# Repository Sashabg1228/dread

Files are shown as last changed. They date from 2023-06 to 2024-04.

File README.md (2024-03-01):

# dread
Version 1 of the battlebot was sawbot battlebot inspired by Sawblaze
It was made for the event TuesBattlebots 2023.
The project was developed from December 2022 to June 2023.

Version 2 of the robot is used for graduation project in school.
The type of the robot is changed from sawbot to hammersaw, meaning the saw no longer has the function of cutting but of striking the opponents. The work on this version started at the end of September 2023.

Link to github repo:
https://github.com/Sashabg1228/dread.git

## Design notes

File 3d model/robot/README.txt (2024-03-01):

To see the current version of the project go to:
https://a360.co/3Ihqd91

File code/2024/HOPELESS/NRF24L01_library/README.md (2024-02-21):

library for nRF24L01 radio module

IMPORTANT:
The library is specifically made for the STM32F103C8 (blue pill) board.

Set the fowolling user labels to the coresponding pins:

NRF24L01_IRQ - the pin connected to the IRG pin of the nRF24L01 module 
NRF24L01_CE - the pin connected to the CE pin of the nRF24L01 module
NRF24L01_CSN - the pin connected to the CSN pin of the nRF24L01 module

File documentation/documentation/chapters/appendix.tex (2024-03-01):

\begingroup % Begin a TeX group in order to localize scope of next three instructions
    \small
    \begin{longtable}{| m{4.5cm} | m{4.5cm} | m{3cm} | m{2cm} |}
    %% Headers and footers
    \caption{Използвани елементи в печатната платка на робота}
    \label{table:elements-robot} \\
    \hline
    \textbf{Вид} 
      & \textbf{Продуктов номер / Размер}
      & \textbf{Reference(s)}
      & \textbf{брой} \\ \hline
    \endfirsthead 
    \hline
    \textbf{Вид} 
      & \textbf{Продуктов номер / Размер}
      & \textbf{Reference(s)}
      & \textbf{брой} \\ \hline
    \endhead 
    \multicolumn{4}{r@{}}{\em}\\
    \endfoot
    \endlastfoot
    %% Body of table
    Електролитен Кондензатор & 100uF & C1, C5, C8 & 3 
    \\ \hline
    Керамичен Кондензатор & 100nF & C2, C3, C4, C6, C7, C9, C10, C11, C12 & 9
    \\ \hline
    Ценеров диод & BZX85C10-TAP & D1 & 1
    \\ \hline
    Двупосочен трансил & P6KE27CA & D3 & 1
    \\ \hline
    Оптрони & HCPL-2531 & IC1, IC2, IC3 & 3
    \\ \hline
    Клема 2 пина & 236-102 & J1, J3, J4, J7, J16, J6, J9, J18, J13, J14, J15 & 11
    \\ \hline
    Клема 4 пина & 236-104 & J2, J10, J11 & 1
    \\ \hline
    Клема 1 пин & 236-401 & J5, J8, J12, J17 & 4
    \\ \hline
    Бобина & 2.2uH & L1 & 1
    \\ \hline
    P-MOS транзистор & IXTP120P065T & Q1 & 1
    \\ \hline
    Резистор & 8.2kR & R1 & 1
    \\ \hline
    Резистор & 680R & R2, R3, R4 & 3
    \\ \hline
    Линеен регулатор & L7805 & U3, U4 & 2
    \\ \hline
    Преобразувател на логическото ниво & CD40109BE & U12 & 1
    \\ \hline
    Гнездо за бушон & 3522-2 & X1 & 1
    \\ \hline
    \end{longtable}
\endgroup % End of TeX group

%================================================================================
%================================================================================

\begingroup % Begin a TeX group in order to localize scope of next three instructions
\begin{landscape}
    \small
    \begin{longtable}{| m{2cm} | m{5cm} | m{3cm} | m{3cm} | m{9cm} |}
    %% Headers and footers
    \caption{Конфигурация на изводите на микроконтролера на робота}
    \label{table:pins-robot} \\
    \hline
    \textbf{Pin Nо.} 
      & \textbf{User label}
      & \textbf{GPIO mode}
      & \textbf{GPIO pull-up}
      & \textbf{GPIO function} \\ \hline
    \endfirsthead 
    \hline
    \textbf{Pin Nо.} 
      & \textbf{User label}
      & \textbf{GPIO mode}
      & \textbf{GPIO pull-up}
      & \textbf{GPIO function} \\ \hline
    \endhead 
    \multicolumn{5}{r@{}}{\em Cont'd on following page}\\
    \endfoot
    \endlastfoot
    %% Body of table
    PA1 & HAND\_PWM & GPIO\_OUTPUT & NO & Чрез таймер 2 се генерират импулси за управление на стъпковия мотор\\
            \hline
            PA2 & HAND\_DIR & GPIO\_OUTPUT & NO & Управлява се посоката на движение на стъпковия мотор\\
            \hline
            PA4 & DISK\_DIR & GPIO\_OUTPUT & NO & Управлява се посоката на движение на мотора за оръжието\\
            \hline
            PA5 & WHEEL\_LEFT\_DIR & GPIO\_OUTPUT & NO & Управлява се посоката на движение на мотора за лявото колело\\
            \hline
            PA6 & WHEEL\_RIGHT\_DIR & GPIO\_OUTPUT & NO & Управлява се посоката на движение на мотора за дясното колело\\
            \hline
            PA7 & DISK\_PWM & TIM3\_CH2 & NO & Чрез канал 2 на таймер 3 се генерира ШИМ сигнал за управление на скоростта на мотора за оръжието\\
            \hline
            PB0 & WHEEL\_LEFT\_PWM & TIM3\_CH3 & NO & Чрез канал 3 на таймер 3 се генерира ШИМ сигнал за управление на скоростта на мотора за лявото колело\\
            \hline
            PB1 & WHEEL\_RIGHT\_PWM & TIM3\_CH4 & NO & Чрез канал 4 на таймер 3 се генерира ШИМ сигнал за управление на скоростта на мотора за дясното колело\\
            \hline
            PB14 & HAND\_END\_LEFT & GPIO\_EXTI14 & PULL-UP & Чрез външното прекъсване на този пин, генерирано при падащ и растящ фронт, се предотвратява излизането на стъпковия мотор извън крайното си състояние\\
            \hline
            PB15 & HAND\_END\_RIGHT & GPIO\_EXTI15 & PULL-UP & Чрез външното прекъсване на този пин, генерирано при падащ и растящ фронт, се предотвратява излизането на стъпковия мотор извън крайното си състояние\\
            \hline
             PB7 & OPT\_END\_WHEEL\_RIGHT & GPIO\_EXTI7 & PULL-UP & Чрез външното прекъсване на този пин, генерирано при падащ фронт, се проследява каква е скоростта на мотора за дясното колело\\
            \hline
            PB8 & OPT\_END\_WHEEL\_LEFT & GPIO\_EXTI8 & PULL-UP & Чрез външното прекъсване на този пин, генерирано при падащ фронт, се проследява каква е скоростта на мотора за лявото колело\\
            \hline
            PB9 & OPT\_END\_WHEEL\_DISK & GPIO\_EXTI9 & PULL-UP & Чрез външното прекъсване на този пин, генерирано при падащ фронт, се проследява каква е скоростта на мотора за оръжието\\
            \hline
            PB5 & SPI1\_MOSI & SPI1\_MOSI & NO & Използва се за MOSI пин при помуникацията с радиочестотния модул\\
            \hline
            PB4 & SPI1\_MISO & SPI1\_MISO & NO & Използва се за MISO пин при помуникацията с радиочестотния модул\\
            \hline
            PB3 & SPI1\_SCK & SPI1\_SCK & NO & Използва се за SCK пин при помуникацията с радиочестотния модул\\
            \hline
            PA10 & NRF24L01\_IRQ & GPIO\_EXTI10 & NO & Чрез външното прекъсване на този пин, генерирано при падащ фронт, се известява за това, че има получен пакет информация\\
            \hline
            PA11 & NRF24L01\_CE & GPIO\_OUTPUT & NO & Управлява се дали може да се изпращат и получават данни\\
            \hline
            PA15 & NRF24L01\_CSN & GPIO\_OUTPUT & NO & Управлява се дали може да се четат и пишат регистрите на радиочестотния модул\\
            \hline
    \end{longtable}
\end{landscape}
\endgroup % End of TeX group

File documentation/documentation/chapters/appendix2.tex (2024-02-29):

\begin{figure}[H]
    \centering
    \caption{На следващата страница е електрическата схема на робота }
    \label{fig:robot-schema} 
\end{figure}

\includepdf[pages={1}]{documents/robot-schema.pdf}

\begin{figure}[H]
    \centering
    \caption{Печатна платка на робот}
    Следващите 7 изображения са отделните слоеве на печатната платка в робота. Те са в мащаб 1:1 и са наредени в следния ред:
    Мед, страна компоненти \\
    Мед, страна спойки \\
    Ситопечат, страна компоненти \\
    Ситопечат, страна спойки \\
    солдер маска, страна компоненти\\
    солдер маска, страна спойки\\
    Ръбове и отвори 
    
    \label{fig:pcb-layout-multy-robot} 
\end{figure}

\includepdf[pages={1}]{documents/PCB-layout-multy-robot.pdf}
\includepdf[pages={2}]{documents/PCB-layout-multy-robot.pdf}
\includepdf[pages={7}]{documents/PCB-layout-multy-robot.pdf}
\includepdf[pages={8}]{documents/PCB-layout-multy-robot.pdf}
\includepdf[pages={9}]{documents/PCB-layout-multy-robot.pdf}
\includepdf[pages={10}]{documents/PCB-layout-multy-robot.pdf}
\includepdf[pages={11}]{documents/PCB-layout-multy-robot.pdf}

\begin{figure}[H]
    \centering
    \caption{На следващата страница е монтажната схема на робота }
    \label{fig:robot-mounting-schema} 
\end{figure}

\includepdf[pages={1}]{documents/robot-mounting-schema.pdf}

\begin{figure}[H]
    \centering
    \caption{На следващата страница е електрическата схема на пулта за управление }
    \label{fig:controller-schema} 
\end{figure}

\includepdf[pages={1}]{documents/controller-schema.pdf}

\begin{figure}[H]
    \centering
    \caption{Печатна платка на пълта за управление}
    Следващите 7 изображения са отделните слоеве на печатната платка в робота. Те са в мащаб 1:1 и са наредени в следния ред:
    Мед, страна компоненти \\
    Мед, страна спойки \\
    Ситопечат, страна компоненти \\
    Ситопечат, страна спойки \\
    солдер маска, страна компоненти\\
    солдер маска, страна спойки\\
    Ръбове и отвори 
    
    \label{fig:pcb-layout-multy-controller} 
\end{figure}

\includepdf[pages={1}]{documents/PCB-layout-multy-controller.pdf}
\includepdf[pages={2}]{documents/PCB-layout-multy-controller.pdf}
\includepdf[pages={3}]{documents/PCB-layout-multy-controller.pdf}
\includepdf[pages={4}]{documents/PCB-layout-multy-controller.pdf}
\includepdf[pages={5}]{documents/PCB-layout-multy-controller.pdf}
\includepdf[pages={6}]{documents/PCB-layout-multy-controller.pdf}
\includepdf[pages={7}]{documents/PCB-layout-multy-controller.pdf}

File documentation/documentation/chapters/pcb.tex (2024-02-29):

\chapter{Проектиране на печатните платки}

За проектирането на печатните платки и монтажните схеми в проекта е използван софтуерния пакет KiCad. Той е избран за целта, защото е безплатен и има богата библиотека с компоненти, съдържащи символи и очертания на корпуси.

%================================================================================
% ЕЛЕКТРИЧЕСКА СХЕМА  -  РОБОТ

\section{Принципна електрическа схема на робота}

Принципната електрическа схема на печатната платка в робота може да бъде видяна на \cref{fig:robot-schema}. Основният елемент на схемата е микроконтролерът STM32F103C8T6 (blue pill), който управлява останалите компоненти. Използваните компоненти в проектирането на тази печатната платка могат да бъдат видяни в таблица \cref{table:pins-robot}.

\subsection{Радиочестотен модул}
\label{ssec:rf-module-robot}

Връзката между дистанционното и робота се осъществява посредством nRF24L01+ PA/LNA радиочестотен модул. Комуникацията между него и използвания микроконтролер е посредством SPI интерфейс. Радиочестотният модул бива захранван с 3,3V от вградения регулатор на напрежението на blue pill. С цел повишаване на съотношението сигнал/шум са поставени 100nF керамичен кондензатор и 100uF електролитен кондензатор, които да намалят съответно високочестотните и нискочестотните шумове.

предавател по далеч / мощни мотори = повече шум
слаб сигнал

%+ какво е ПА/ЛНА 
%+ режим на СПИ интерфей и неговата скорост
\begin{figure}[H]
    \centering
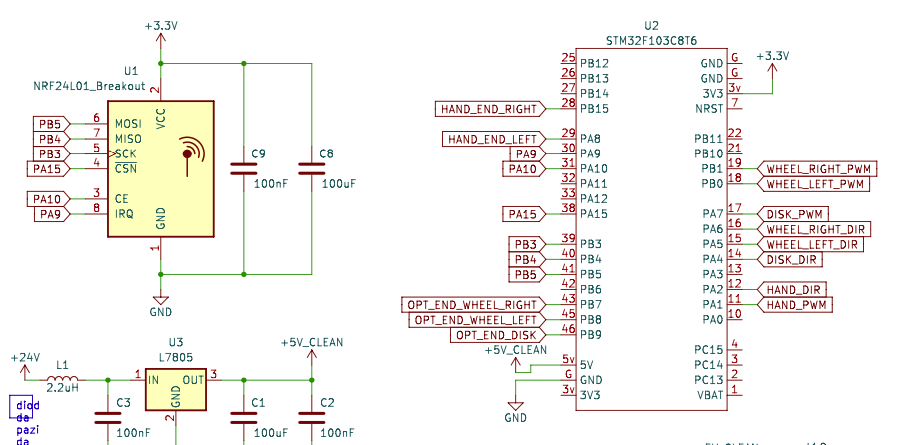
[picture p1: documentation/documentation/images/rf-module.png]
    
    
    \caption{Радиочестотен модул в робота}
    \label{fig:rf-module-robot} 
\end{figure}

\subsection{Управление на моторите}

Управлението на постоянно токовите четкови мотори се извършва посредством MD13S драйвери. Необходимите логически сигнали за да може да се реализира управлението са ШИМ сиганл, който упоменава скоростта, с която мотора трябва да се върти, и високо или ниско ниво, което да показва посоката на движение. С цел постигане на галванична изолация между микроконтролера и драйверите са поставени оптрони. Начинът на свързване на всеки оптрон може да бъде видян на \cref{fig:brushed-control}. Необходимото захранване на всеки мотор е 24V и то бива подадено посредством отделен конектор.

\begin{figure}[H]
    \centering
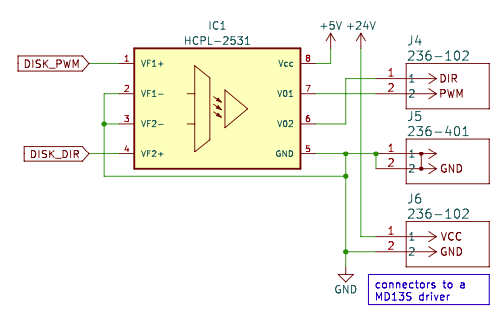
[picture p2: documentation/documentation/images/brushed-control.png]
    
    
    \caption{Оптрон}
    \label{fig:brushed-control} 
\end{figure}

За управлението на стъпковия мотор се използва драйвер DM556T. Сигналите за управление включват , поредица от импулси, които указват колко стъпки трябва да бъдат направени и логическо ниво (високо или ниско), указващо посоката им. Не е поставен допълнителен оптрон за изолация между драйвера и микроконтролера, поради причината, че на входовете си DM556T има вградени такива. Така направена схемата обаче няма да работи, защото логика на blue pill-а е на 3,3V, докато драйвера използва 5V логика. Този проблем бива решен като се използва преобразувател на логически нива U12, който превежда логическото управление от 3,3V към 5V, съответстващо на логиката, използвана от драйвера.

\begin{figure}[H]
    \centering
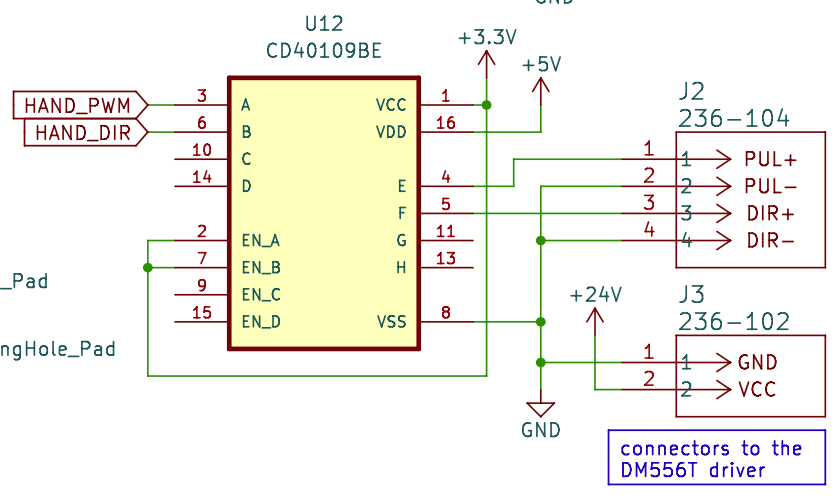
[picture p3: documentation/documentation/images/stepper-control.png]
    
    
    \caption{Преобразувател на логически нива}
    \label{fig:stepper-control} 
\end{figure}

\subsection{Сензори}

За следене на скоростта на робота са предвидени и инсталирани оптични сензори. Те биват свързвани към печатната плака чрез конекторите J10, J11 и J12. Всеки сензор има извод за данни и изводи за захранване. Сигналите от оптичните сензори минават през пасивни нискочестотни RC филтри с цел да се премахнат потенциални смущения.

\begin{figure}[H]
    \centering
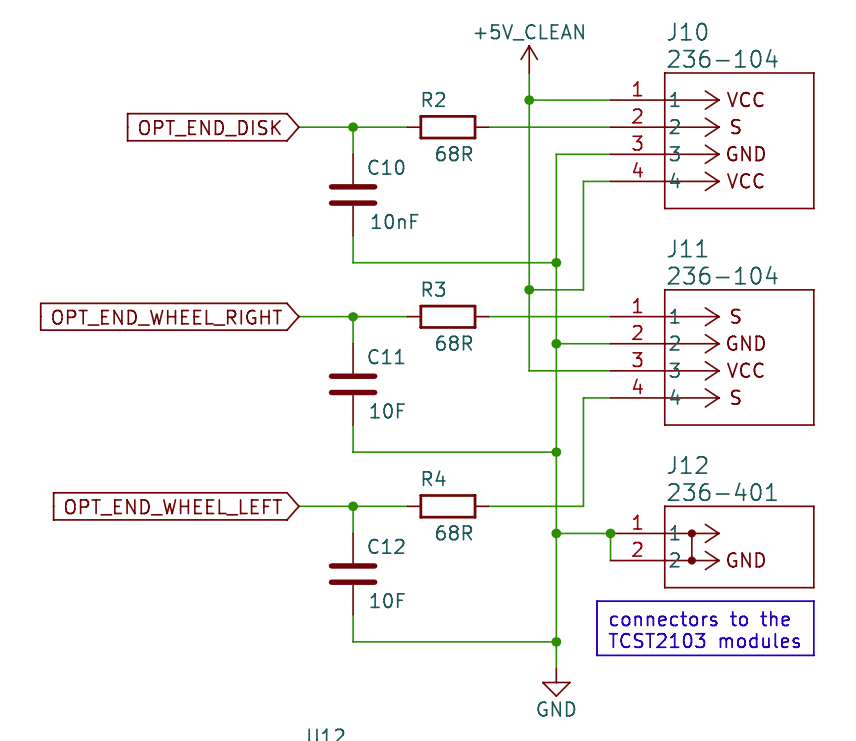
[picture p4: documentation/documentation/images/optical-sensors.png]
    
    
    \caption{оптични сензори}
    \label{fig:optical-sensors} 
\end{figure}

Съгласно изискванията за безопасност са предвидени и крайни изключватели, които да следят дали стъпковият мотор е достигнал някоя от крайните си позиции. Те са свързани, чрез конекторите J13 и J14

\begin{figure}[H]
    \centering
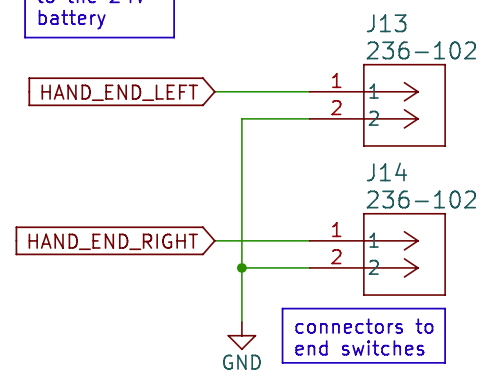
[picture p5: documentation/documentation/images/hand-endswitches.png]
    
    
    \caption{Крайни изключватели за ръката}
    \label{fig:hand-endswitches} 
\end{figure}

\subsection{Захранване на печатната платка}

Печатната платка се захранва директно от 24V постояннотокова батерия. Съгласно изискванията за безопасност изводите на конектор J15 са предвидени за ключ, който да спира цялото захранване на робота. Освен това има имплементирани хардуерни защити против късо съединение, пренапрежение и обратен поляритет на захранването. Първата от трите е реализирана чрез поставянето на автомобилен бушон на държача X1 последователно свързан след главния ключ. Защитата против пренапрежение се осъществява посредством двупосочния трансил D3. С цел защита против неправилен поляритет на напрежението е поставена P-MOS защита след трансила. Тя се реализира чрез транзистора Q2, ценеровия диод D1 и резистора R1. При правилното свързване на батерията през диода в Q1 протича ток. Поради образувания делител на напрежение D1 и R1, напрежението гейт-сорс на Q2 става равно на пробивното напрежение на D1 и транзисторът се отпушва. В случай, че батерията бъде свързана с обратен поляритет, диодът в Q1 бива свързан в обратна посока и транзисторът остава запушен. Във веригата е поставен и кондензатора C7 за да стабилизира напрежението върху ценера D1.

\begin{figure}[H]
    \centering
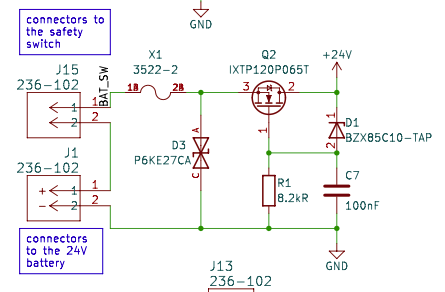
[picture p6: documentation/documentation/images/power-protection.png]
    
    
    \caption{Защити на захранването}
    \label{fig:power-protection} 
\end{figure}

Захранването на логическата част на проекта е постигнато посредством линейни стабилизатори L7805. Tо е разделено на два канала за да може да бъдат намалени шумовете в захранването на микроконтролера и радиочестотния модул. По-чувствителните към шумове елементи разполагат с отдлно захранване. 

Първият канал използва стабилизатора U4 за да успее да свали напрежението до 5V, които да бъдат подадени после на оптроните на логическата част на четковите мотори и на логическия преобразовател на стъпковия мотор. Той е показан на \cref{fig:power-5V}. За намаляване на шумовете в системата са поставени електролитния кондензатор C5 и керамичния C4 и C6. 

Второто захранване е почти идентичен с първия. Той се използва за захранването на микроконтролера, радиочестотния модул и сензорите в робота. Може да бъде видян на \cref{fig:power-5V-clean}. Това захранване допълнително разполага с индуктор L1, който блокира смущения.

\begin{figure}[H] 
    \centering
    \begin{subfigure}[h]{0.6\textwidth}
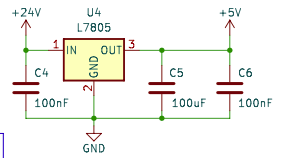
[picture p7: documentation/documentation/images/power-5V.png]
        
        \caption{Захранване на логиката на силовата електроника}
        \label{fig:power-5V}
    \end{subfigure}
    \\ %add desired spacing between images, e. g. ~, \quad, \qquad, \hfill etc. 
      %(or a blank line to force the subfigure onto a new line)
    \begin{subfigure}[h]{0.75\textwidth}
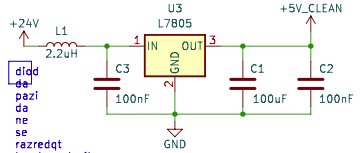
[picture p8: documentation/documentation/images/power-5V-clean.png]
        
        \caption{Захранване на микроконтролера, радиочестотния модул и сензорите}
        \label{fig:power-5V-clean}
    \end{subfigure}
    ~ %add desired spacing between images, e. g. ~, \quad, \qquad, \hfill etc. 
    %(or a blank line to force the subfigure onto a new line)    
    \caption{Захранване на логическата част в робота.}
    \label{fig:power-low}
\end{figure}

%================================================================================
% PCB layout  -  РОБОТ

\section{Опроводяване на печатната платка на робота}

На \cref{fig:pcb-layout-color-robot} могат да се видят двата слоя на печатната платка. Захранващата мрежа +24V е опроводена чрез медни зони. При проектирането и е спазена добрата практика, когато има две различни напрежения на печатната платка те да бъдат отделени максимално далеч едно от друго. По останалата част от проводниците се движат или +5V, или от +3.3V. Голямата медна област от долната страна се използва за земя. В 3 от четирите ъгъла могат да бъдат видени предвидените монтажни отвори за закрепване на платката. Особеност на тази платка е неизбежното застъпването на U1 и U12. В общия случай подобно разположение на елементите е груба грешка, но U1 е модул, монтиран на стандартни рейки. Това оставя повече от достатъчно пространство U12 да бъде поставен. 

В \cref{fig:pcb-layout-multy-robot} са показани поотделно всеки слой на печатната платка.

\begin{figure}[H]
    \centering
    
    
    \caption{Печатна платка на робота}
    \label{fig:pcb-layout-color-robot} 
\end{figure}

%================================================================================
% МОНТАЖНА СХЕМА  -  РОБОТ

\section{Монтажна схема на робота}

Монтажната схема на робота може да бъде намерена в \cref{fig:robot-mounting-schema}. На нея може да се види основната част в робота, представляваща разработената печатна платка, която съдържа радиочестотния модул за комуникация, микроконтролера, управляващ робота, и хардуерните защити на захранването. Нейното захранване индва от 24V батерия DeWalt DE0241 и съгласно изисканията за безопасност във всеки момент то може да бъде прекъснато чрез ключът SW1. Разработената платка захранва и управлява 3 постояннотокови четкови мотори с помощта на драйвери MD13S. С цел мониторинг на тяхната скорост е предвидено на всеки от тях да има монтиран по един оптичен сензор за скорост. Използваният nema 24 стъпков мотор се управлява посредством DM556T драйвер. Начинат на свързване на драйвера към печатната платка е конфигурация общ катод. Съгласно изискванията за безопасност чрез SW1 и SW2 се следи дали стъпковият мотор не е стигнал до крайните си състояния.

%+ параметри на входовете на драйверите

%================================================================================
% ЕЛЕКТРИЧЕСКА СХЕМА  -  ДИСТАНЦИОННО

\section{Принципна електрическа схема на пулта за управление}

Принципната електрическа схема на печатната платка на дистанционното може да бъде видяна на \cref{fig:controller-schema}. Основният елемент на схемата е микроконтролерът STM32F103C8T6 (blue pill), който чете данните от сензорите, обработва ги и после ги праща към робота посредством радиочестотния модул. Връзката между него и микроконтролера е идентична на тази описана в \cref{ssec:rf-module-robot}. Захранването на пулта за управление на бойния робот се реализира посредством USB извода на използвания микроконтролер.

\begin{figure}[H]
    \centering
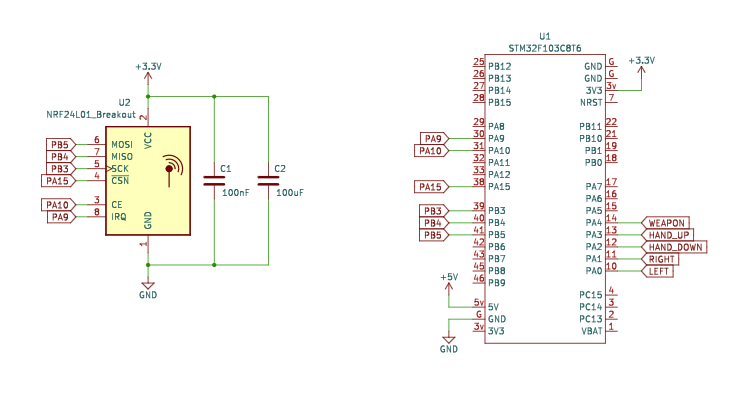
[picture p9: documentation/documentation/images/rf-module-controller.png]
    
    
    \caption{Радиочестотен модул в пулта за управление}
    \label{fig:rf-module-controller} 
\end{figure}

\subsection{Сензори}

Компонентите, които се използват за четене на инструкциите от пилота на бойния робот са 2 потенциометъра и 3 бутона. Потенциометрите са свързани посредством конекторите J4, J5 и J6. Връзката с бутоните е осъществена чрез конекторите J1, J2 и J3.

\begin{figure}[H]
    \centering
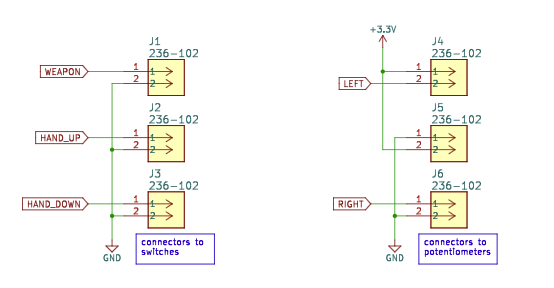
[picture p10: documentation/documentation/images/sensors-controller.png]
    
    
    \caption{Сензори в пулта за управление}
    \label{fig:sensors-controller} 
\end{figure}

%================================================================================
% PCB layout  -  ДИСТАНЦИОННО

\section{Опроводяване на печатната платка на дистанционното}

На \cref{fig:pcb-layout-color-robot} могат да се видят двата слоя на печатната платка на дистанционното. По проводниците, които могат да се видят, се движат 3,3V. Голямата медна област, която се забелязва се използва за земя. Забелязва се и липсата на монтажни отвори. Причината за тяхното отсъствие е това, че платката е предвидена да бъде легнала на страна спойки във специално по размери 3D принтирано легло.

В \cref{fig:pcb-layout-multy-controller} са показани поотделно всеки слой на печатната платка.

\begin{figure}[H]
    \centering
    
    
    \caption{Печатна платка на пулта за управление}
    \label{fig:pcb-layout-color-controller} 
\end{figure}

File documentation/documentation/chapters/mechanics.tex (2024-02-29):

\chapter{Механика}

%================================================================================
% ЦЯЛОСТЕН МОДЕЛ
 
\section{Цялостен модел на робота}

Както е описано в предишната глава, дизайна на бойния робот е вдъхновен от робота SawBlaze. Материала, който е използван за изграждането на прототипа на проекта е два милиметра дебела студено валцована въглеродна стомана DC01. Механичната конструкция на робота може да бъде разделена на два основни компонента - шасито, в което седят почти всички елементи, и механичната ръка, на която е закрепено оръжието.  

\begin{figure}[H]
    \centering
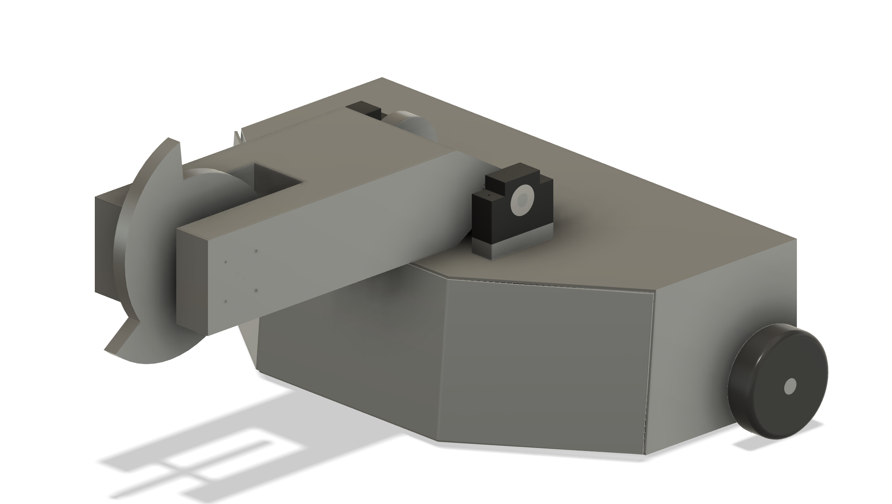
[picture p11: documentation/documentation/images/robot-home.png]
    
    
    \caption{3D макет на бойния робот}
    \label{fig:robot-home} 
\end{figure}

%================================================================================
% ЗАДВИЖВАНЕ

\section{Задвижване на робота}
\label{sec:motion}

По време на проектирането на механиката на боен робот първият проблем, който трябва да бъде разгледан е как той ще се придвижва по арената. След направеното проучване в \cref{sec:motion-types} бе установено, че най-ефективният метод е диференциалното задвижване с колела. По дизайн роботът има две задвижващи колела отдвете си страни и още две допълнителни пасивни колела, които го балансират и му помагат да се движи по-добре. Всяко от задвижващите колела е с външен диаметър 80мм и ширина 12мм. Използваните мотори за тяхното задвижване са CHANCS 895 DC.

\begin{figure}[H]
    \centering
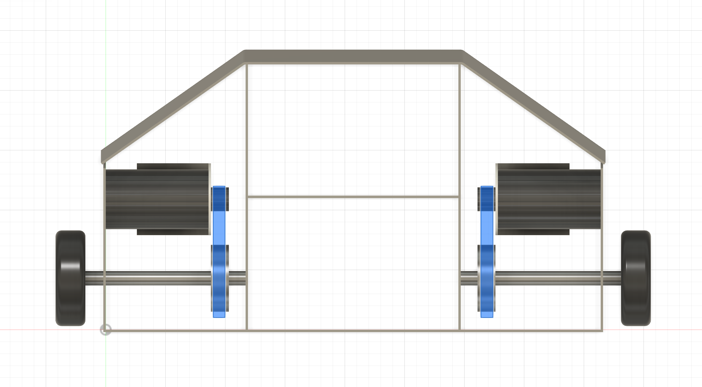
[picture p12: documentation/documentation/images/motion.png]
    
    
    \caption{Схема на задвижването на бойния робот}
    \label{fig:motion} 
\end{figure}

За да може батълбота, който тежи приблизително 18kg, да се задвижва от две колела трябва да бъде пресметнато какъв въртящ момент трябва да достига до всяко от тях
\footnote{Изчисленията са извършени като се приема, че роботът се движи на равна повърхност}
. За целта на изчисленията приемаме, че двете активни колела ще понасят цялото тегло на робота. Понеже на двете колела лежи тежестта от 18kg, означава, че всяко колело изпитва натиска от 9kg или еквивалентните им 88,29N. Коефициента на триене между колелата и пода на арената варира между 0,75 когато робота е в покой и 0,65 когато е в движение. Следователно най-голямата сила на съпротивление, която всяко колело може да генерира без самото колело да се върти е 88,29N х 0.75 = 66,2175N. След като диаметъра на колелото е 80мм следва, че радиусът му е 40мм или 0,04м. Следователно минималният въртящ момент, който позволява на колелата да се въртят е равен на 66,2175N x 0,04m = 2,6487Nm. Следователно минималният въртящ момент, който мотора трябва да достави на колелото е 2,6487Nm, но по време на въртенето си той има само 0,735Nm.

Поради тази причина се налага да се направи редукция на скоростта на мотора за да се увеличи неговия въртящ момент. За да се изчисли каква трябва да бъде нужната редукция трябва да се намери отношението на необходимият въртящ момент и този, който може да бъде генериран. Редукцията, която се получава, че трябва да бъде реализирана между мотора и колелото е минимум 2,6487Nm / 0,735Nm = 3,6.

Начинът, по който е реализирано диференциалното задвижване е като всяко от активните колела бива задвижвано от различен мотор. Връзката между тях е реализирана, чрез зъбчат ремък с ширина 10мм. За да се постигне необходимата редукция, отношението на зъбите на ремъчните ролки на осите на колелата и тези на моторите трябва да бъде равно на нея. Поради това използваните ролки на моторите са с по 10 зъба, а другите са с по 36 зъба. С цел намаляване на триенето между осите на колелата и стените, осите са захванати с лагери в специално изработените за целта лагерни опори, закрепени за стените.

%================================================================================
% РЪКАТА

\section{Задвижване на ръката}

Първата специфична функционалност на разработения боен робот е начина, по който механичната ръка се върти около оста си и се задържа на позицията, на която и бива зададено да седи. Тази задача бива изпълнена чрез употребата на стъпков мотор Nema 24.

За да може ръката да се върти около оста си първо трябва да бъде изчислено какъв въртящ момент ще бъде необходим за целта. Тежестта на ръката е приблизително 4kg, което означава, че силата която е нужно да бъде приложена за да може тя да се завърти е 39,24N. За да пресметнем колко е необходимият въртящ момент за нейното завъртане е необходимо получената сила да бъде умножена по дължината на ръката, която е 240мм(0,24м). По този начин получаваме, че трябва да бъдат приложени 39,24N х 0,24м = 9,4176Nm. Употребеният стъпков мотор може да задържа на една позиция само товари, които изискват въртящ момент 3,1Nm или по-малко, от което следва, че се налага да бъде приложена минимална редукция от 3,03 за да може да бъде реализирано въртенето на ръката.

\begin{figure}[H]
    \centering
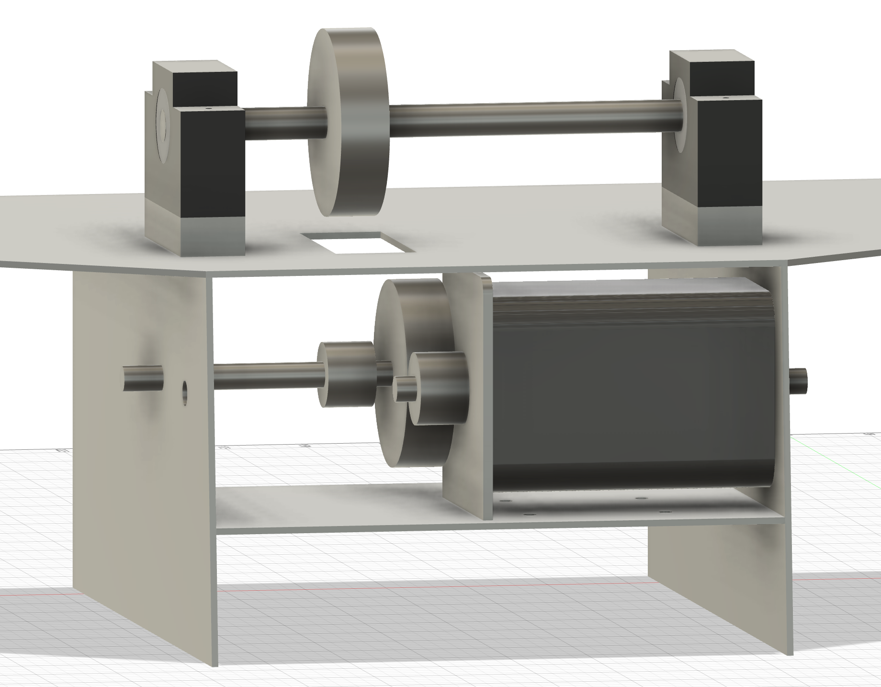
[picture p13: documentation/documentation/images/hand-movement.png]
    
    
    \caption{Схема на задвижването на механичната ръка}
    \label{fig:hand-movement} 
\end{figure}

Начинът, по който е осъществено завъртането на ръката е като тя бива захваната за своята ос така, че чрез завъртането на оста ръката да бъде придвижена заедно с нея. Предаването на движението от стъпковия мотор към оста на ръката е постигнато посредством зъбни ремъци. С цел максималното увеличение на приложената редукция е поставена спомагателна ос между мотора и оста на ръката. По този начин се получават две редукции на движението на мотора. Първата бива от мотора към спомагателната ос, като поставената ролка на мотора има 12 зъба, а тази на спомагателната ос 36 зъба. Постиганата редукция чрез тази връзка е 3. Втората редукция бива от спомагателната ос към оста на ръката и използваните ролки са в същото отношение като тези в предишната предавка. Резултатът от двете връзки е, че общата редукция на скоростта на въртене на мотора се получава да бъде умножението на двете, от които е съставена, което я прави 9. За намаляване на съпротивлението по време на въртенето си са поставени лагерни опори в краищата на двете оси.

%================================================================================
% ОРЪЖИЕТО

\section{Задвижване на оръжието}

Друг проблем, който трябва да бъде решен по време на проектирането на механиката на всеки боен робот е по какъв начин неговото оръжие ще се задвижва. Както е описано в точка \cref{sec:block-schemas} оръжието, което се използва в разработения проект е 180-милиметров диск с ширина 8мм и специфична форма. Формата на диска може да бъде видяна на фигура \cref{fig:disk}. Той е захванат за своята ос така, че чрез завъртането на оста и диска да се върти заедно с нея. Използваният мотор за движението на оръжието е CHANCS 895 DC. Начина, по който е реализирано предаването на движението от мотора до оста на диска е посредством плосък ремък. Избран е плосък ремък за тази цел, а не зъбчат поради причината, че при удар ремъка и мотора трябва отведнъж да спрат своето движение, което често може да доведе до прескачане на зъби на зъбчатия ремък и тяхното ронене. В тези ситуации плоския ремък няма да се амортизира по този начин, а само ще се приплъзне леко по своите ролки. Реализирана е и редукция от 5 на скоростта на тази предавка поради високата скорост, с която би се въртял диска. С цел намаляване на съпротивлението по време на въртенето си в краищата си оста на диска е поставен в лагерни опори, които са застопорени за стените на ръката.

\begin{figure}[H]
    \centering
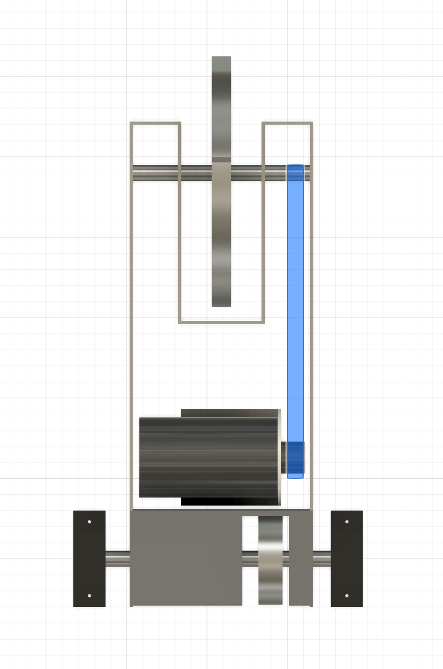
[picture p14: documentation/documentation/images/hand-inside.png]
    
    
    \caption{Схема на задвижването на оръжието}
    \label{fig:hand-inside} 
\end{figure}

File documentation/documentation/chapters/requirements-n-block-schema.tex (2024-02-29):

\chapter{Дизайн и блоковата схема на робота}

\section{Дизайн и Функционални изисквания към робота}
\label{sec:requirements}

В рамките на дипломната работа бойният робот, който се разработва, е с оръжие "hammer saw". Този вид оръжие е хибрид между пневматичните чукове и въртящите се режещи дискове. По дизайн оръжието е диск, чиято формата не е перфектен кръг, а е неправилна особена форма. Тя може да бъде видяна на \cref{fig:disk}. Разработения робот е вдъхновен от робота SawBlaze участник от телевизионното състезание BattleBots.

\begin{figure}[H]
    \centering
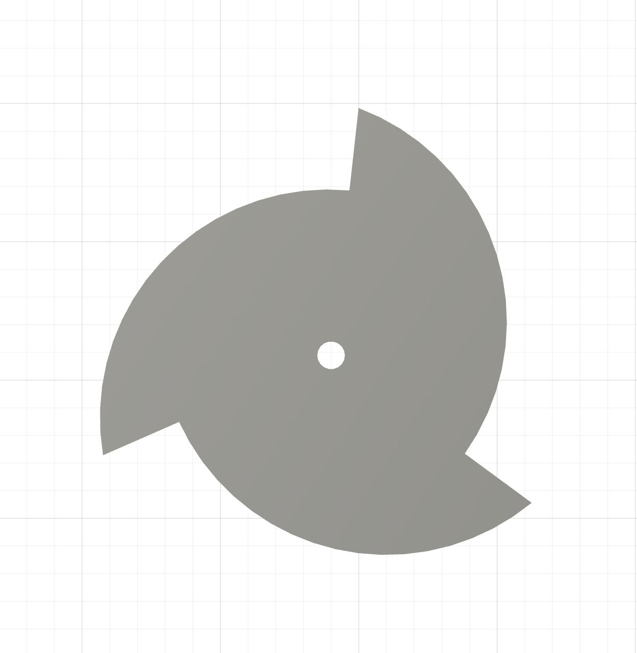
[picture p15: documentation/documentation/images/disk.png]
    
    
    \caption{Хоризонтален разрез на оръжието}
    \label{fig:disk} 
\end{figure}

\section{Блок схеми}
\label{sec:block-schemas}

На \cref{fig:block-controller} и \cref{fig:block-robot} са представени блоковите схеми на пулта за управление и робота. Със син цвят са представени устройствата слаботоковите устройства, а червен захранването и силовата електроника. Черните стрелки на схемите представляват пренос на данни, а червените - захранване.

Основния компонент в схемата на дистанционното печатната платка, върху която седи микроконтролерът и радиочестотния модул. Това което микроконтролера прави е да прочита данните от бутоните и потенциометрите и да се предават посредством радио модула до печатната платка в робота. За повече информация какъв е цикъла на работа може да се прочете \cref{sec:logic-schemas}.

\begin{figure}[H]
    \centering
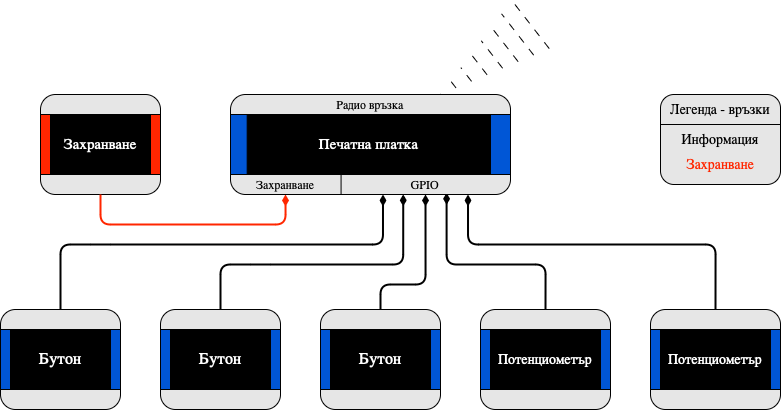
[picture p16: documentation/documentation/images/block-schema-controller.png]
    
    
    \caption{Блокова схема на дистанционното}
    \label{fig:block-controller} 
\end{figure}

Подобно на пулта за управление основния компонент в робота е печатната платка, защото на нея са поставени избраният микроконтролер и радиочестотния модул. Тук функцията на nRF модула е да се получават данните изпратени от дистанционното и да се предадат на микроконтролера. Той на свой ред ги изпълнява като в зависимост от тях се променя управлението на силовите компоненти. Два от четковите мотори се използват за задвижване на робота, а третия за завъртане на оръжието. Стъпковият мотор се използва за да се контролира позицията на ръката с оръжието. Успоредно на това чрез оптичните сензори се следи скоростта на четковите мотори. Освен това чрез крайните изключватели се следи стъпковия мотор да не излиза извън крайните си състояния.

\begin{figure}[H]
    \centering
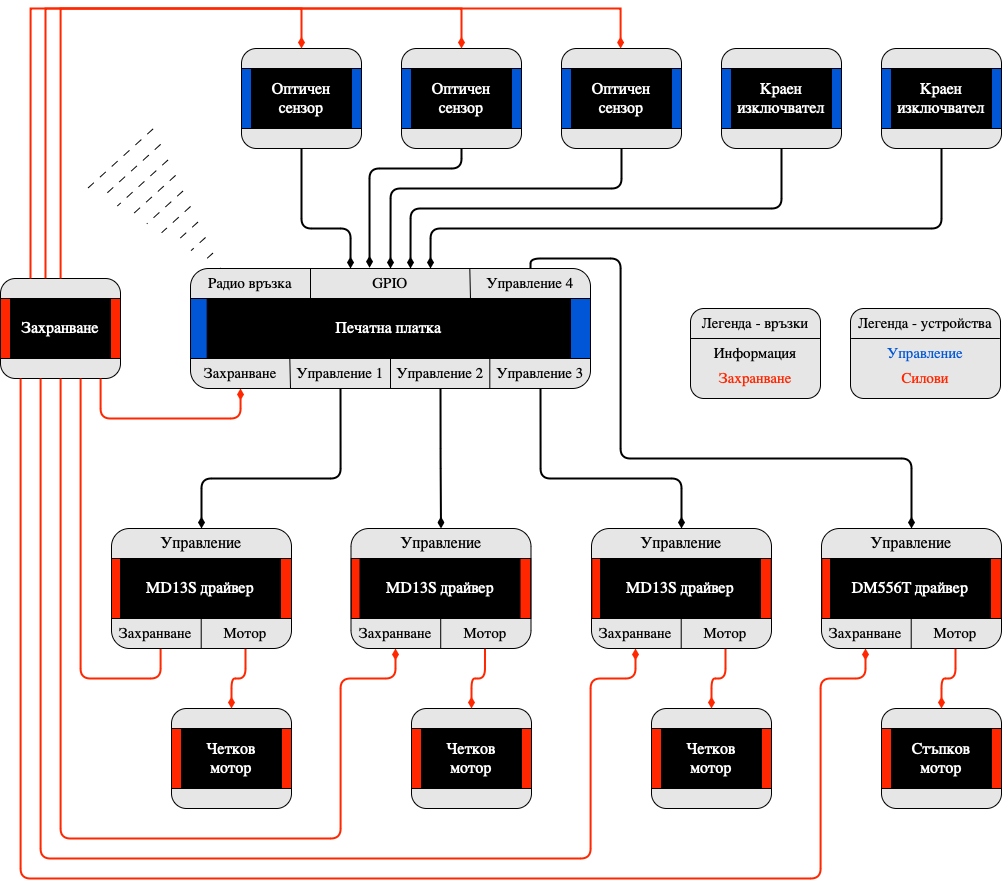
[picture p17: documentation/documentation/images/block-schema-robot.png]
    
    
    \caption{Блокова схема на робота}
    \label{fig:block-robot} 
\end{figure}

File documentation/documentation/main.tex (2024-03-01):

\documentclass{tu_coursework}

%================================================================================
% МЕТАДАННИ
\title{Боен робот с пулт за дистанционно управление по радио връзка}
\doctype{ДИПЛОМНА РАБОТА}
\author{Александър Иванов}
%\speciality{Системно програмиране}
\admgroup{69}
\faculty{ТЕХНОЛОГИЧНО УЧИЛИЩЕ ЕЛЕКТРОННИ СИСТЕМИ\\ към ТЕХНИЧЕСКИ УНИВЕРСИТЕТ - СОФИЯ}
\fac{ФЕТТ}
\facnumber{101218420}
\supervisor{инж. Владимир Гаристов}
% Закоментирай долния ред, ако няма рецензент
%\reviewer{проф. д.т.н. Юлиан Вучков}
\date{\today}
\city{София}

\usepackage{array,ragged2e,longtable}
\usepackage{pdflscape}
\begin{document}

%================================================================================
% Заглавие

\maketitle
\cleardoublepage

%================================================================================
% Задание

\includepdf[pages={1}]{documents/assignment_signed.pdf}

%================================================================================
% Съдържание

\pagenumbering{arabic}
\tableofcontents
\listoffigures
\listoftables
\lstlistoflistings

%================================================================================
% Глави

\input{chapters/intro}

\input{chapters/research}
\input{chapters/requirements-n-block-schema}
\input{chapters/mechanics}
\input{chapters/pcb}
\input{chapters/software}

\input{chapters/conclusion}

\appendix
\chapter{Списъци на използваните пинове и компоненти}
\input{chapters/appendix}

\chapter{Схеми на използваните печатните платки}
\input{chapters/appendix2}

\nocite{combat-tutorial}
\nocite{battlebots-rules}
\nocite{pmos-article}
\nocite{optron-article}
\nocite{nRF24L01-datasheet}
\nocite{STM32F103C8-reference}
\nocite{STM32F103C8-datasheet}

\printbibliography
\end{document}

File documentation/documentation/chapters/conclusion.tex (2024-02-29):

\chapter{Заключение}

\section{Постигнати резултати}

Успешно е реализирано проектирането и изработката на механичното конструкция на бойния робот. Осъществен е и контрола на движението на постояннотоковите четкови мотори посредством широчинно-импулсен сигнал. Инсталирани са и са тествани оптични сензори, с които се мери скоростта на четковите мотори. Реализирано е и управлението на стъпковия мотор на механичната ръка. Инсталирани са и крайните изключватели, които да следят да не се преминават крайните позиции от ръката. Постигната е и безжичната радиовръзка робот - пулт за управление. По време на проектирането на дипломния проект бяха спазени всички изисквания от правила на Tues BattleBots 2024 и дефинираните функции за безопасност.

\section{Бъдещо развитие}

Основните недостатъци на разработения дипломен проект са свързани с избрания радиочестотен модул и неговата употреба в проекта. Избраният модул въпреки, че има възможността да предава и получава повече от достатъчно количество информация на голямо разстояние, не може да го прави едновременно. За да се постигне двупосочна комуникация трябва постоянно да се преконфигурира неговият режим на работа. 

Разработената безжична комуникация е постигната без употребата на криптиране на инструкциите към робота. Този факт излага на риск хората и техниката около робота поради причината, че се дава възможност на злонамерени лица да управляват робота.

Към момента на предаване на дипломния проект има реализирана функция за отмерване на скоростта на постояннотоковите мотори, но тази информация е достъпна само за микроконтролера в робота. На пулта за управление може да бъде добавен дисплей и да се разработи графичен интерфейс, който да показва отмерените скорости, състоянието на оръжието и друга информация като нивото на батерията на робота.

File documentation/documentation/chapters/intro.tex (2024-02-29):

\chapter{Увод}

Още от зората си, човечеството търси разнообразни и вълнуващи начини да успее да избяга от еднообразното си ежедневие. За целта много и различни методи за развлечение са възникнали, вариращи от приятелски игри до зрелищни спектакли. Едно от най-разпространените забавления още от тогава е също толкова популярно и днес, а именно – боевете. Зрелището на това два индивида да се бият помежду си завладява всеки зрител. Годините са доказали, че колкото по-драматична е една битка, толкова по-силни са чувствата, които се пораждат у нейните наблюдатели. Но това води до един неизбежен проблем: участниците в такива интензивни битки винаги биват физически наранени. Поради тази причина се появява казусът как може да се постигнат тези зрелища, без участниците да пострадат. Решението на този проблем са битките с бойни роботи (или батълботи). Стандартна битка трае 3 минути и в тях роботизираните системи, контролирани чрез дистанционно управление, целят увреждането на опонента до такава степен, че вече да не може да извършва движения.

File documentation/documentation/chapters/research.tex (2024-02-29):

\chapter{ Методи, средства и методологии за изработване на бойни роботи}

%================================================================================
% ЗАДВИЖВАНЕ

\section{Основни методи и технологии за задвижване на бойни роботи}
\label{sec:motion-types}

Бойните роботи традиционно могат да се задвижват по три начина чрез вериги, колела или механични крака. Има и други начини, но те не са ефективни в битка.
Роботите, задвижвани с танкови вериги, имат отлично сцепление със земята и вървят много стабилно, но имат много недостатъци. Поради голямата площ на триене при завъртане те изразходват значително количество енергия. Освен това и самото движение се извършва сравнително бавно, което позволява на опонента да заобиколи робота и да го удари в гръб. Боен робот, задвижван от верига, може да се види на \cref{fig:using-treads}.

\begin{figure}[H]
    \centering
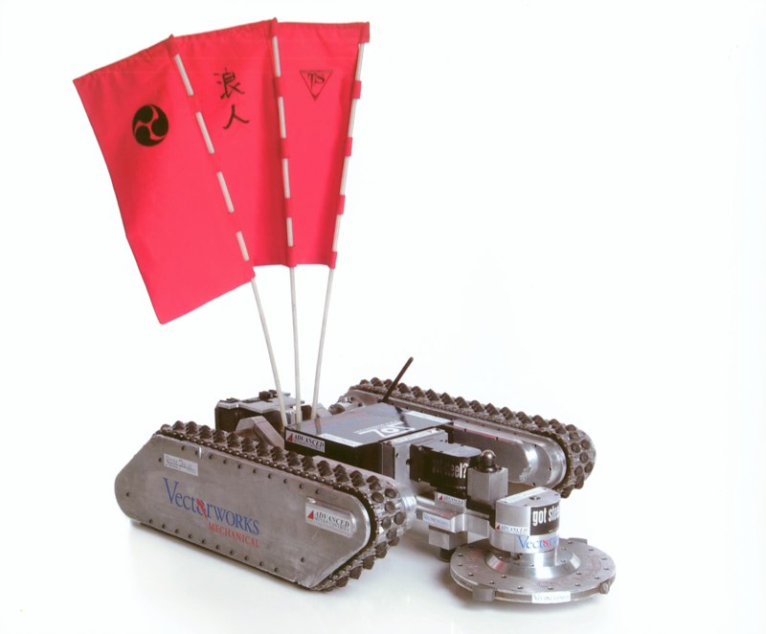
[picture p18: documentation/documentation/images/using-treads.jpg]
    
    
    \caption{Боен робот, задвижван от вериги}
    \label{fig:using-treads} 
\end{figure}

Механичните крака имат също много недостатъци. Някои от които са, че са много сложни за конструкция и контрол. Друг техен недостатък е, че те не са достатъчно здрави по време на битка, особено срещу посичащите спинер роботи. Повече за този тип бойни роботи може да се прочете в \cref{sec:robot-types}. Трета слабост е, че центъра на тежестта на роботи с такава система за задвижване е много високо над земята, което ги прави уязвими срещу атаки, целящи преобръщане. Батълбот, използващ механични крака може да бъде видян на \cref{fig:using-legs}.

\begin{figure}[H]
    \centering
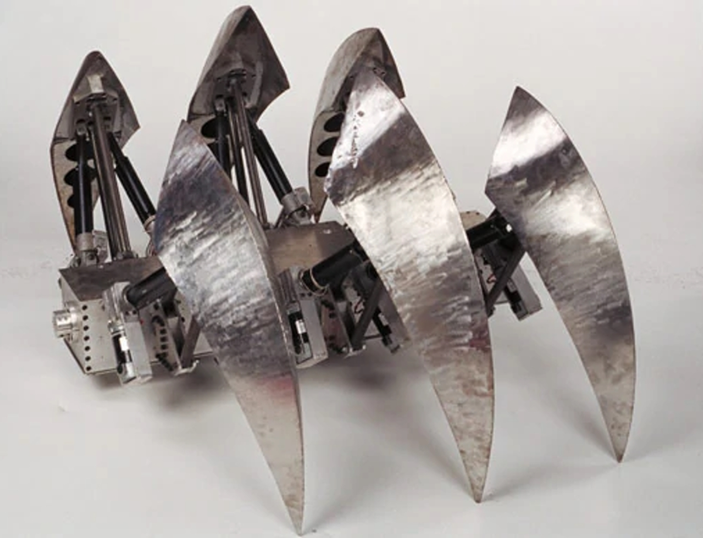
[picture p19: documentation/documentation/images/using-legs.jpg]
    

    \caption{Боен робот, задвижван от механични крака}
    \label{fig:using-legs} 
\end{figure}

Поради гореспоменатите причини, най-често бойните роботи се задвижват чрез колела. Разпространени са два начина на управление на задвижването на моторни средства с колела – Акерман управление и диференциално управление. Акерман управлението е възприето от повечето моторни-превозни средства. При него един голям мотор задвижва колелата и един по-малък отговаря за тяхното завъртане. То е ефективно при движение в права линия, но когато трябва да се завие се изискват определени маневри. Диференциалното управление е много по-често срещано в роботиката. При него лявата и дясната страна на робота се задвижват напълно индивидуално. Недостатъкът на този метод е фактът, че за да се движи моторното средство в права линия двете половини требва да имат еднаква скорост, което е трудно за постигане. Голямото преимущество обаче е, че завиването става значително по-бързо.

Освен по начин на управление на задвижването роботите придвижващи се с колела се различават помежду си и чрез броя на задвижваните колела. При такива с две задвижващи колела и диференциално управление на задвижването, завиването се случва със сравнително ниски загуби на енергия. Проблемът е, че с две опорни точки, роботът най-вероятно ще има нужда от поне още една такава. Той се решава чрез добавянето на ball transfer units.

%================================================================================
% КОМУНИКАЦИЯ

\section{Основни методи и технологии за дистанционно управление на бойни роботи}

Съгласно официалните изисквания за работа към бойните роботи, те трябва да бъдат контролирани безжично дистанционно. За целта могат да се използват много технологии за безжична комуникация, като едни от най–популярните са Wi-Fi, Bluetooth и nRF24L01.

Wi-Fi позволява много висока скорост на предаване на информацията, но има много недостатъци. Един от тях е, че има много високо потребление на енергия. Друг е, че не може директно да се предава информация от едно устройство на друго безжично, а първо трябва тази информация да се подаде на маршрутизатор и след това той да я изпрати до устройството получател. Отделно по време на боевете се очаква да има голяма публика и безплатен Wi-Fi което предполага, че каналите, които се използват за тази технология ще бъдат претоварени и съответно ще има по-лоша свързаност. 

Bluetooth технологията осигурява средна скорост на предаване на информация, на цената на средно ниво на консумация на енергия. Недостатъкът е, че за да могат две устройства да се свържат и да общуват безжично и двете трябва предварително да се сдвоят, което е непрактично за системи, които не включват компютри или телефони.

Модулът nRF24L01 позволява безжична радиочестотна комуникация с други такива модули. От трите технологии за безжична комуникация този модул предлага тази с най-ниско потребление на енергия. За разлика от Wi-Fi, nRF24L01 може да се комуникира с друго устройство директно, без необходимостта от маршрутизатор. Предимството му пред Bluetooth е, че не е необходимо предварително двете устройства да се сдвояват.

\begin{table}[H]
    \centering
    \begin{tabular}{| m{4cm} | m{3,5cm} | m{3,5cm} | m{3,5cm} |}
        \hline
        & Wi-fi & Bluetooth & nRF24L01+ \\
        \hline
        Скорост &  Висока & Средно & Средна \\
        \hline
        Обхват & 10ки метри & 10 метра & 10-150 метра \\
        \hline
        Енергийна консумация & Висока & Средна & Ниска\\
        \hline
    \end{tabular}
    \caption{Сравнителна таблица за безжични технологии}
    \label{table:wireless}
\end{table}

%================================================================================
% БРОНЯ

\section{Основни методи за защита на бойни роботи}

За защита на бойните роботи винаги се монтира броня около неговата структура. Видовете броня са: традиционна, аблативна и реактивна.

Традиционната броня е изработена от много здрави и твърди материали, които се стремят да абсорбират и предадат енергията на удара без да се повреждат. Високата твърдост и здравина на този вид защита често се използва за чупене или изтъпяване на остриетата на вражеските оръжия и запазване целостта на робота при удари. Благодарение на здравината си тази броня по-рядко трябва да се сменя след битки, но нейният недостатък е, че при удар енергията на сблъсъка се предава до елементите вътре в робота, което може да доведе до тяхното повреждане.

Аблативната защита, от друга страна е проектирана да предпазва от щети робота, като самата тя бива повреждана чрез процеса аблация. Това е процеса на премахване на материал от повърхността на обект посредством изпарение или стружко отделяне. Материалите, от които е изградена са също твърди и здрави, но за разлика от традиционната броня имат по-ниска твърдост. Поради това тяхно свойство, когато тези брони трябва да предпазват от силни удари, вътрешните елементи биват изложени на риск. Материали като дървото са много ефикасни представители на този вид елементи, но друг техен недостатък е, че сблъсъците водят до много визуални следи, което често носи допълнителни точки на опонента за щети.

Третия вид броня е реактивната. По време на удар тя реагира по някакъв начин, за да предотврати щети. Има различни видове реактивна броня и всяка има свой предимства и недостатъци. Пример за такъв вид защита е пласт гума между два пласта метал. Предимството й е, че в случай на удар, пластът гума би абсорбирал енергията на удара. Този вид броня не е ефективна в боевете с роботи, поради причината, че много бързо бива повреждана и спира да пази.

%================================================================================
% ВИДОВЕ РОБОТИ

\section{Видове съществуващи бойни роботи}
\label{sec:robot-types}

Съществуват много различни видове батълботи. Основно изискване към всеки от тях е да имат поне едно оръжие, чрез което да могат да повредят опонента. В зависимост от своето оръжие роботите се разделят на 14 типа: „rammer“, „wedge“, „lifter“, „flipper“, „spearbots“, „horizontal spinner“, „sawbot“, „vertical spinner“, „drumbot“, „hammerbot“, „clamper“, „crusher“, „flamethrower“ и „multibot“. Има и други видове роботи, но те почти винаги могат да бъдат категоризирани в един от гореспоменатите видове. За ефективността на бойния робот в битка има голямо значение какво оръжие е избрано. Примерно със своите огромни дискове нанасящи разрушителни удари роботите с оръжие „vertical spinner“ са много ефективни срещу голяма част от роботите. Те имат обаче един фатален недостатък, който се изразява в това, че поради голямата скорост на въртене на съответното оръжие генерират жироскопичен ефект, който намалява осезателно скоростта им на движение, което ги прави уязвими към удари отзад. С времето в роботските боеве категориите „flipper“, „horizontal spinner“, „vertical spinner“, „drumbot“, „hammerbot“ и „clamper“ са се откроили като по-ефективни в сравнение с останалите.

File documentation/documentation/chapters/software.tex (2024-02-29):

\chapter{Софтуерна реализация}
\label{chap:software}
% TODO: ask Garistov if 1/4 sec is enough for magic smoke to appear
% TODO: ask Garistov what to do with the messed up interupts
Използваната среда за разработка на софтуерната част от дипломния проект е софтуерния пакет STM32CubbeIDE на STMicroelectronics. Тази платформа е предназначена за изграждане на софтуерното управление на STM микроконтролери и микропроцесори. Чрез интеграцията на GNU GCC компилатор и GBD дебъгер, тя предоставя стабилна среда за разработка на C/C++ програми. В STM32CubbeIDE е интегриран и графичния инструмент STM32CubeMX. Той улеснява конфигурацията и инициализацията на различни части и периферии на микроконтролерите, сред които са пинове, таймери, системни прекъсвания и DMA заявки. Друга основна характеристика на избраната среда за разработка е възможността за подробен дебъгване чрез мониторинг на процесорните ядра, регистрите на периферията, паметта и заделените променливи и други. Софтуерният пакет може да бъде свален безплатно от сайта на STMicroelectronics за 64-битовите версии на операционните системи Windows, Linux и macOS. Поради споменатите причини тази среда за разработка беше използвана за проекта.

%================================================================================
% ЛОГИЧЕСКА СХЕМА  -  РОБОТ

\section{Логическа схема на проекта}
\label{sec:logic-schemas}

Съгласно заданието на дипломния проект разработеният боен робот бива управляван посредством специално изработено дистанционно. Комуникацията между тях бива реализирана посредством радиочестотните модули nRF24L01 на компанията Nordic. Те използват вградения си протокол за комуникация Enhanced ShockBurst, който е предназначен за лесна комуникация с ниска енергийна консумация.

Като се получи захранване микроконтролера и радиочестотния модул в дистанционното биват инициализирани. След това започва непрекъснато повтарящият се на равни интерваи цикъл на работа. Първо се прочитат входните данни от потенциометрите и бутоните. След това те биват обработени и записани в подходящ вид. В края на този цикъл обработените потребителски команди биват записани в пакет с инструкции за контрол на бойния робот и той бива изпратен към батълбота за изпълнение. После цикъла на работа на дистанционното започва да се изпълнява отначало. Микроконтролерът е настроен да може да бъдат изпращани по 20 пакета с команди в секунда. Това скорост гарантира на пилота възможността да може да управлява своята машина с минимално системно забавяне.

\begin{figure}[H]
    \centering
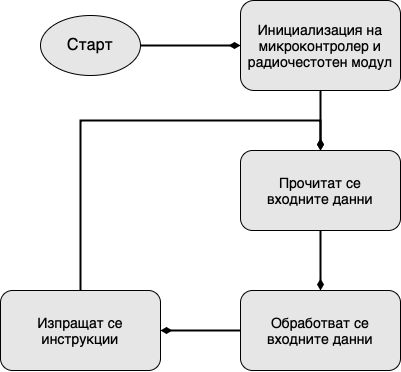
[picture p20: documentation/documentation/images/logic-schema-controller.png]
    
    
    \caption{Логическа схема на дистанционното}
    \label{fig:logic-controller} 
\end{figure}

Полетата, които се съдържат в изпратения пакет са инструкция за позицията, на която трябва да застане механичната ръка на робота, инструкции за скоростта и посоката на въртене на двете колела и инструкция за това дали оръжието трябва да се върти. Структурата на такъв пакет може да бъде видяна на \autoref{lst:payload}.

\lstinputlisting[language=c, consecutivenumbers=false, linerange={11-17}, caption={Пакет инструкции}, label={lst:payload}]{documents/rf-library/NRF24L01.h}

Подобно на дистанционното първата работа на печатната платка, когато получи захранване е да се инициализират микроконтролера и радиочестотния модул. След това започва непрекъснат цикъл на проверяване дали има получен пакет инструкции и ако има се прави опит той да бъде достъпен. При успешното им прочитане те биват заредени в паметта на платката и биват изпълнени. След тази стъпка следва повторно започване на работния цикъл на робота. В случаите, в които няма получени инструкции или не бъде успешно тяхното прочитане, цикъла на работа започва отначало и се спира движението на робота.

\begin{figure}[H]
    \centering
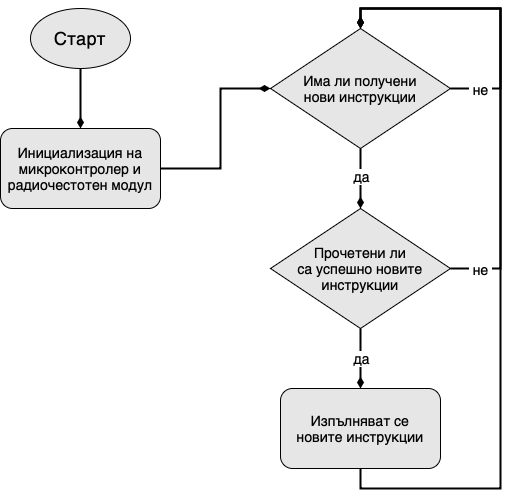
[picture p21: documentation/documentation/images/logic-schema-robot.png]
    
    
    \caption{Логическа схема на робота}
    \label{fig:logic-robot} 
\end{figure}

%================================================================================
% СОФТУЕР  -  РАДИО

\input{chapters/sections/software-library}

%================================================================================
% СОФТУЕР  -  ДИСТАНЦИОННО

\input{chapters/sections/software-controller}

%================================================================================
% СОФТУЕР  -  РОБОТ

\input{chapters/sections/software-robot}

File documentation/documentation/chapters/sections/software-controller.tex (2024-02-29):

\section{Софтуерна реализация на дистанционното}
\label{sec:software-controller}

%================================================================================
% ИНИЦИАЛИЗАЦИЯ

\subsection{Инициализация на микроконтролера на дистанционното}
\label{ssec:init-controller}

След като получи захранването си микроконтролера преминава през серия от процеси, които трябва да конфигурират използваните периферии, изводи и променливи. Посредством функцията HAL\_Init() се рестартират всички периферии и се инициализират HAL библиотеката и всички нейни функционалности. След това чрез SystemClock\_Config() се конфигурира системния таймер. После следва конфигурацията на изводите на микроконтролера. Една от тях може да бъде видяна в \autoref{lst:conf-pin-controller}. За това кой пин как е конфигуриран и за какво се използва може да се разбере от таблица \cref{table:pins-controller}. След това се инициализира SPI връзката с nRF модула. Чрез MX\_TIM4\_Init() се инициализира таймер 4, с помощта на когото се изпращат пакетите с инструкции на равни периоди. След това се инициализират и двата аналогово-цифрови преобразувателя, които се използват за четене на състоянието на потенциометрите. Последната инициализация е тази на радиочестотния модул и се задава неговия режим на работа. Преди да започне повтарящият се цикъл на работа таймера се стартира и се пуска калибрация на аналогово-цифровите преобразуватели.

\lstinputlisting[language=c, consecutivenumbers=false, linerange={72-76}, caption={Конфигуриране на пин}, label={lst:conf-pin-controller}]{documents/controller/gpio.c}

%================================================================================
% РАБОТЕН ЦИКЪЛ

\subsection{Работен цикъл на дистанционното}
\label{ssec:loop-controller}

Както е описано в \cref{sec:logic-schemas} цикъла на работа се повтаря на равни интервали. Това е постигнато посредством прекъсването при преливане на таймер 4. Той е конфигуриран така, че прекъсването да бъде генерирано на всяка десета от секундата. След извикването на прекъсването се вдига флага send\_flag. При това действие се прочитат състоянията на потенциометрите и се записват на полетата за скорост на лявото и дясното колело. Това е последвано от извикването на функцията за калибриране на данните. В края на този цикъл се инициира изпращане на пакета с инструкциите и при успех се сменя състоянието на вградения светодиод.

\lstinputlisting[language=c, consecutivenumbers=false, linerange={113-134}, caption={Работен цикъл}, label={lst:loop-controller}]{documents/controller/controller.c}

Успоредно на това има конфигурирани и външни прекъсвания. Те имат функцията да редактират позицията на ръката и да пускат или спират движението на оръжието.

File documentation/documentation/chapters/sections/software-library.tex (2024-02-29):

\section{Софтуерна реализация на библиотеката на радиочестотния модул}
\label{sec:library}

Безжичната комуникация между дистанционното и бойния робот се осъществава посредством радиочестотния модул nRF24L01 на компанията Nordic. За целите на дипломния проект не беше употребявана готова библиотека за управление на избрания модул, а беше разработена собствена такава. За нейната реализация са употребявани функционалностите на вградената HAL библиотека. С цел улеснение на написването на библиотеката, в заглавния файл са дефинирани като макроси адресите в паметта на регистрите и SPI командните думи. За да може библиотеката да работи, предварително трябва да бъде конфигуриран SPI интерфейса и пиновете, които се използват nRF модула. С цел улеснение на работата с библиотеката е предвидено предварително изводите на радиочестотния модул да имат зададени потребителските етикети NRF24L01\_CSN, NRF24L01\_CE и NRF24L01\_IRQ на съответните им пинове на микроконтролера.

Основните функционалности, които трябва да бъдат реализирани, за да може библиотеката да бъде разработена са писане и четене на регистрите на радиочестотния модул. За да се пише в регистър се подготвя масив с дължина 2 байта. В първия се поставя номера на регистъра, а във втория стойността, която трябва да бъде записана. За да може nRF модула да разбере, че трябва да запише получената стойност, трябва да бъде поставена единица на 5-та позиция от първия байт. Съгласно секция 8.3. "SPI комуникация" от документацията на nRF24L01 всяка SPI операция трябва да бъде започната с падащ фронт на CSN извода на радиочестотния модул. След това се извиква HAL функцията за предаване на информация по SPI интерфейса.

\lstinputlisting[language=c, consecutivenumbers=false, linerange={37-51}, caption={Писане в регистър}, label={lst:write-register}]{documents/rf-library/NRF24L01.c}

Четенето на регистър се реализира аналогично. При него не се подготвя масив, в който да се постави адреса на регистъра и той не бива редактиран. Вместо това първо се използва HAL функцията за предаване на номера на регистъра, който трябва да бъде прочетен, и след това се използва HAL функцията за получаване на данни по SPI.

\lstinputlisting[language=c, consecutivenumbers=false, linerange={72-87}, caption={Четене на регистър}, label={lst:read-register}]{documents/rf-library/NRF24L01.c}

Основната част от регистрите в паметта на използвания nRF модул са с размер 1 байт, но тези, които съхраняват адреси за каналите за комуникация 0 и 1 имат 5 пъти по-голяма дължина. Поради тази причина са написани функциите nrf24\_write\_reg\_multi() и nrf24\_read\_reg\_multi(), които съответно могат да бъдат видени на \autoref{lst:write-big-register} и \autoref{lst:read-big-register}. Те са реализирани аналогично на по-малките им подобни функции.

\lstinputlisting[language=c, consecutivenumbers=false, linerange={52-70}, caption={Писане на големи регистри}, label={lst:write-big-register}]{documents/rf-library/NRF24L01.c}

\lstinputlisting[language=c, consecutivenumbers=false, linerange={88-99}, caption={Четене на големи регистри}, label={lst:read-big-register}]{documents/rf-library/NRF24L01.c}

%================================================================================
% ИНИЦИАЛИЗАЦИЯ

\subsection{Инициализация на модула}
\label{ssec:init}

При получаване на захранване първата задача на микроконтролера и радио модула е да бъдат конфигурирани. Инициализацията на първия може да бъде видяна в \cref{ssec:init-controller} и \cref{ssec:init-robot}. Привеждането на радиочестотния модул в състояние, което позволява безжично предаване на информация е осъществено като се извикват една след друга първо функцията за инициализация на модула и след това и допълнителна такава, с която се пояснява дали същия е предавател или получател на информацията.

При началото на инициализацията на CE пина се подава ниско ниво за да се гарантира, че няма да се активира механизма за изпращане на данни. След това се подават зануляват стойностите на CONFIG и RF\_CH регистрите. Те следва да бъдат редактирани при задаването на роля на модула(предавател или приемник). Чрез записване на 0 в EN\_AA регистъра се изключват автоматичните потвърждения по време на безжичното предаване. В регистъра EN\_RXADDR стойността 0 спира употребата на 6-те информационни канала. За да се дефинира дължината на адреса да бъде 5 байта в регистъра SETUP\_AW са поставени единици на битове 0 и 1. Последния регистър, който се конфигурира в рамките на тази функция е RF\_SETUP. Чрез поставяне на 0 на 3 бит в него се задава скоростта на предаване на информация да бъде 1Mbps, а посредством единици на битове 1 и 2, мощността на предаване на изхода на радиото е 0dBm. 

\lstinputlisting[language=c, consecutivenumbers=false, linerange={145-159}, caption={Инициализация на радио модула}, label={lst:init}]{documents/rf-library/NRF24L01.c}

След функцията за инициализиране на nRF модула се извиква функция, която да пояснява дали модула е предавател или получател на данни. В \autoref{lst:conf-transmitter} може да бъде видяна процедурата за конфигуриране предавател. Първо се задава в регистър RF\_CH честотата (канала), на която ще се предава информацията. След това се записва 5 байтовия адрес на получателя в TX\_ADDR регистъра. После без да се редактира останалата част от регистъра в CONFIG се поставят единица на бит 1 и се оставя нула на бит 0 съответно за да се стартира дейността на радиочестотния модул и за да се влезе в режим на изпращач на информация. 

\lstinputlisting[language=c, consecutivenumbers=false, linerange={164-174}, caption={Конфигуриране на изпращач на данни}, label={lst:conf-transmitter}]{documents/rf-library/NRF24L01.c}

Подобно на последно разглежданата функция NRF24\_RX\_mode() започва със задаване на честотата на предаване на информация. След това без да се редактира останалата част от регистъра EN\_RXADDR се поставя единица на бит 1 поради за да се позволи употребата на информационен канал 1. После се записва 5 байтовия адрес на изпращача на информация в RX\_ADDR\_P1 регистъра. За да се дефинира дължината на пакета данни, който ще се изпраща безжично, се записва големината на структурата Payload в регистъра RX\_PW\_P1. След това без да се реактира останалата му част в CONFIG регистъра се поставят единици на битове 0 и 1 съответно за да се стартира дейността на радиочестотния модул и за да се влезе в режим на получател на данни. В края на тази функция CE пина бива поставен във високо състояние и се държи в това през целия период на работа. В случай, че CE мине в ниско ниво, nRF модула ще излезе от режима на получател.

\lstinputlisting[language=c, consecutivenumbers=false, linerange={234-256}, caption={Конфигуриране на получател на данни}, label={lst:conf-receiver}]{documents/rf-library/NRF24L01.c}

Стойностите, които са избрани за скорост на безжичното предаване, мощността на предаване на изхода на nRF модула и честотата на излъчване на сигнали са подбрани такива, че да осигуряват максимален обхват на безжичната комуникация.

%================================================================================
% ИЗПРАЩАНЕ НА ДАННИ

\subsection{Изпращане на информация}
\label{ssec:transmit}

Изпращането на пакет инструкции от дистанционното към робота се извършва посредством функцията NRF24\_transmit(). Първата стъпка от нейното изпълнение е пакета с инструкции да бъде зареден в паметта на радио модула, посредством функцията, която може да бъде видяна в \autoref{lst:push-payload}. След това се генерира импулс на CE извода по-дълъг от 10us. Съгласно секция 6.1.5. "режим предаване" от документацията на nRF24L01 при такъв импулс в режима за изпращане на данни, записаните в паметта на модула пакети инструкции започват да се излъчват. Останалата част на функцията проверява дали пакетите са били изпратени успешно като проверява съдържанието на FIFO\_STATUS регистъра. Ако четвъртият бит в него е вдигнат означава, че пакета е бил успешно изпратен.

\lstinputlisting[language=c, consecutivenumbers=false, linerange={204-228}, caption={Изпращане на пакет инструкции}, label={lst:transmit}]{documents/rf-library/NRF24L01.c}

Когато се зарежда пакет инструкции в паметта на радиочестотния модул, първо се проверява дали пакета не е твърде голям. В случай, че е опита за безжично изпращане на инструкциите бива прекратен. Останалата част от зареждането на пакета наподобява значително функциите за писане в регистри. Първо се заделя масив от еднобайтови променливи. След това на първа позиция в масива се записва SPI командата за записване на пакета в паметта на модула и чрез функцията memcpy() се записва съдържанието на пакета в масива от втория елемент нататък. Както беше споменато в предишната секция следва да се направи падащ фронт на пин CSN. Когато буфера е вече готов, той бива зареден в паметта, чрез HAL функцията за предаване на информация по SPI интерфейса. Накрая функцията завършва като CSN пина ве върне в свойто предишно състояние.

\lstinputlisting[language=c, consecutivenumbers=false, linerange={175-202}, caption={Зареждане на пакет инструкции}, label={lst:push-payload}]{documents/rf-library/NRF24L01.c}

%================================================================================
% ПОЛУЧАВАНЕ НА ДАННИ

\subsection{Получаване на информация}
\label{ssec:receive}

Получаването на пакети с инструкции се реализира чрез две функции. Първата проверява дали има нова получена информация в радио модула, а втората е същинското и извличане в паметта на микроконтролера. Проверката се осъществява като се прочита STATUS регистъра. Ако бит 6 е единица следва, че има получени нови команди, а в битове 1, 2 и 3 е запазен номера на информационния канал, от който е получената информация. След това стойността на същия регистър се рестартира и функцията връща резултат, показващ, че има получени данни. 

\lstinputlisting[language=c, consecutivenumbers=false, linerange={256-273}, caption={Проверка дали има получен пакет инструкции}, label={lst:check-delivered}]{documents/rf-library/NRF24L01.c}

Във функцията за извличане на данни първата първо се дефинират двата помощни масива. В първия се записва SPI командата R\_RX\_PAYLOAD, която се използва за да се извлече получения нов пакет информация, а във втория следва тя да се бъде записана. След това посредством HAL функцията за предаване и получаване на информация по SPI интерфейса командата се изпраща до радиочестотния модул и сеполучава резултата във втория помощен масив. После чрез функцията memcpy() информацията се премества от помощния регистър в желаната променлива.

\lstinputlisting[language=c, consecutivenumbers=false, linerange={275-299}, caption={Получаване на пакет инструкции}, label={lst:receive}]{documents/rf-library/NRF24L01.c}

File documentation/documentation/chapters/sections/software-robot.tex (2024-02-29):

\section{Софтуерна реализация на управлението на робота}
\label{sec:software-robot}

%================================================================================
% ИНИЦИАЛИЗАЦИЯ

\subsection{Инициализация на микроконтролера на робота}
\label{ssec:init-robot}

След като получи захранването си микроконтролера преминава през серия от процеси, които трябва да конфигурират използваните периферии, изводи и променливи. Посредством функцията HAL\_Init() се рестартират всички периферии и се инициализират HAL библиотеката и всички нейни функционалности. След това чрез SystemClock\_Config() се конфигурира системния таймер. После следва конфигурацията на изводите на микроконтролера. Една от тях може да бъде видяна в \autoref{lst:conf-pin-robot}. За това кой пин как е конфигуриран и за какво се използва може да се разбере от таблица \cref{table:pins-robot}. След това се инициализира SPI връзката с nRF модула. Чрез функциите MX\_TIM3\_Init(), MX\_TIM2\_Init() и MX\_TIM4\_Init() се инициализират таймери 2, 3 и 4. Таймер 3 се използва за генериране широчинно импулсен сигнал за контролиране на скоростта на въртене на четковите мотори, а 4-тия се използва за измерване на тяхната скорост. Таймер 2 се използва за генерирането на импулси за движението на робота. След това се инициализира радиочестотния модул и се задава неговия режим на робота. Чрез функцията HAL\_TIM\_PWM\_Start() се стартира генерирането на широчинно импулсния сигнал. Преди да започне повтарящият се цикъл на работа и таймери 2 и 4 се стартират.

\lstinputlisting[language=c, consecutivenumbers=false, linerange={72-76}, caption={Конфигуриране на пин}, label={lst:conf-pin-robot}]{documents/controller/gpio.c}

%================================================================================
% РАБОТЕН ЦИКЪЛ

\subsection{Работен цикъл на робота}
\label{ssec:loop-robot}

Както е описано в \cref{sec:logic-schemas} цикъла на работа започва с проверка на това дали има получен нов пакет инструкции. Ако има получен такъв се извиква функцията за извличане на данните от радиочестотния модул и ако е успешна се извиква функцията, която прилага инструкциите.

\lstinputlisting[language=c, consecutivenumbers=false, linerange={122-135}, caption={Работен цикъл}, label={lst:loop-robot}]{documents/robot/robot.c}

Функцията за прилагането на инструкциите е съставена от помощни функции. Първо чрез функцията get\_brushed\_DIR() се проверява в коя посока кой от четковите мотори трябва да се върти и се задава съответната стойност на съответния извод. След това посредством get\_brushed\_DIR() се задава какъв трябва да бъде коефициента на запълване на широчинно-импулсния сигнал, който се използва за дава каква трябва да бъде скоростта на въртене на четковите мотори.

\lstinputlisting[language=c, consecutivenumbers=false, linerange={249-280}, caption={Управление на четковите мотори}, label={lst:dc-motor}]{documents/robot/robot.c}

Последната функция, която се извиква във функцията unload\_payload() се казва get\_hand\_DIR(). Тя се използва за да се определя посоката на движение на стъпковия мотор. Импулсите за колко стъпки да бъдат направени се генерират чрез прекъсването при преливане на таймер 2. Функцията за обработка на прекъсването може да бъде видяна в \cref{lst:overflow-interupts}.

\lstinputlisting[language=c, consecutivenumbers=false, linerange={282-297}, caption={Управление на стъпковия мотор}, label={lst:stepper-motor}]{documents/robot/robot.c}

%================================================================================
% СЕНЗОРИ ЗА ОБРАТНА ВРЪЗКА

\subsection{Сензори за обратна връзка}
\label{ssec:feedback-sensors}

Съгласно изискванията за безопасност описани в \cref{sec:requirements} са имплементирани и двата крайни изключвателя за ръката. Те са свързани към изводи на микроконтролера, за които има конфигурирани външни прекъсвания, които се генерират при падащ и нарастващ фронт на вълната. Когато такова прекъсване се появи се вдига флаг, който спира работата на движението на ръката докато ръката не отвори отново крайния изключвател. 

\lstinputlisting[language=c, consecutivenumbers=false, linerange={184-209}, caption={Външни прекъсвания}, label={lst:external-interupts}]{documents/robot/robot.c}

В проекта има монтирани и оптични сензори, чрез които се следи приблизителната скорост на четковите мотори. Тази функционалност е реализирана посредством външни прекъсвания и прекъсване при преливане. При генерирането на първото се увеличава променлива, която съдържа броя завъртания на съответния мотор. Чрез прекъсването при преливане на таймер 4, на равни интервали от време, се проверява дали има направени завъртания за текущия период. Ако няма направени следва да бъде забранено на съответния мотор да се върти известно време.

\lstinputlisting[language=c, consecutivenumbers=false, linerange={211-247}, caption={Прекъсвания при преливане}, label={lst:overflow-interupts}]{documents/robot/robot.c}

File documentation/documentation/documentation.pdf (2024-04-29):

ТЕХНОЛОГИЧНО УЧИЛИЩЕ ЕЛЕКТРОННИ СИСТЕМИ към ТЕХНИЧЕСКИ УНИВЕРСИТЕТ - СОФИЯ

# ДИПЛОМНА РАБОТА

## на тема

## Боен робот с пулт за дистанционно управление по радио връзка

### Дипломант: Александър Иванов специалност

### Дипломен ръководител: инж. Владимир Гаристов

27 април 2024 г.

### София

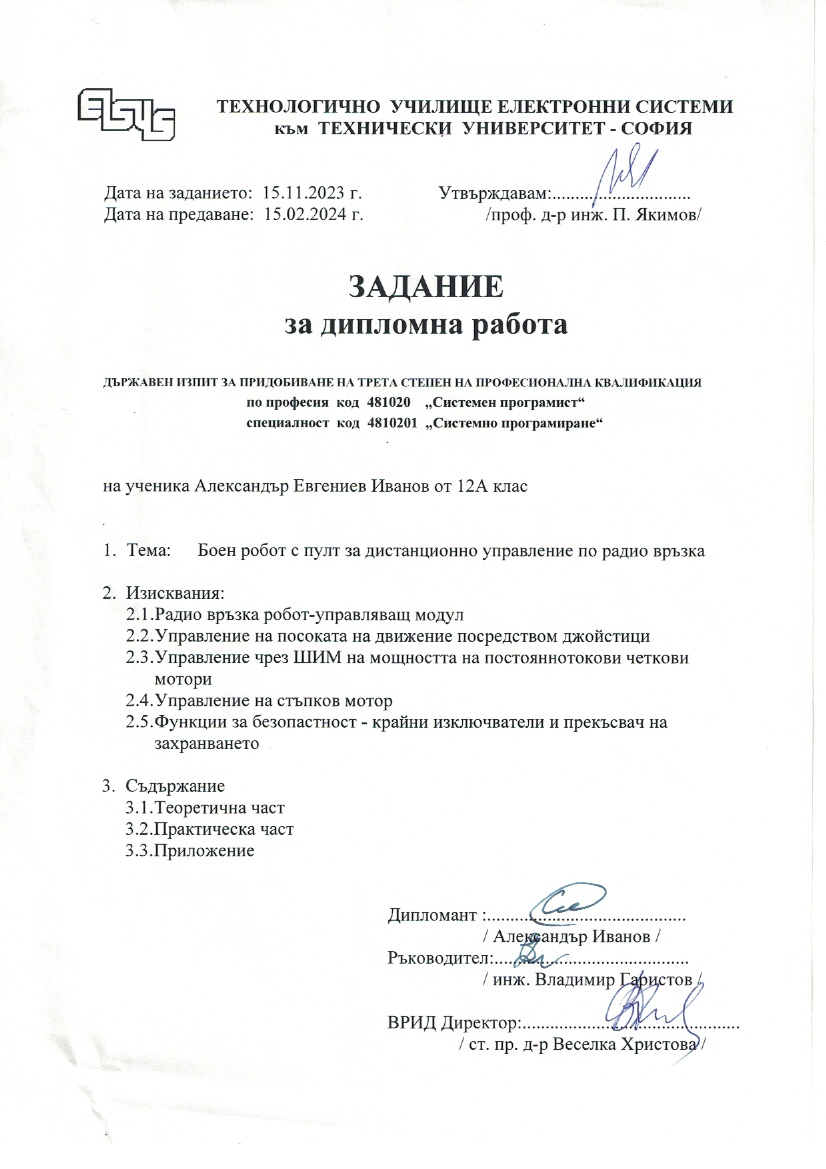
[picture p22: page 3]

# Съдържание

Списък на фигурите | 3
Списък на таблиците | 4
Listings | 5
1. Увод | 6

### 2. Методи, средства и методологии за изработване на бойни

роботи | 7
2.1. Основни методи и технологии за задвижване на бойни роботи 7
2.2. Основни методи и технологии за дистанционно управление
3. Дизайн и блоковата схема на робота | 12
4. Механика | 15
5. Проектиране на печатните платки | 21

1

5.4. Принципна електрическа схема на пулта за управление . . 28
5.5. Опроводяване на печатната платка на дистанционното . . 29
6. Софтуерна реализация | 31
6.2. Софтуерна реализация на библиотеката на радиочестотния
6.3.1. Инициализация на микроконтролера на дистанцион-
6.4.1. Инициализация на микроконтролера на робота . . . . 44
7. Заключение | 49
Приложения | 51
А. Списъци на използваните пинове и компоненти | 51
Б. Схеми на използваните печатните платки | 55
Библиография | 77

### 2 Съдържание

# Списък на фигурите

2.1. Боен робот, задвижван от вериги | | 7
2.2. Боен робот, задвижван от механични крака | | 8
3.1. Хоризонтален разрез на оръжието | 12
3.2. Блокова схема на дистанционното | 13
3.3. Блокова схема на робота | 14
4.1. 3D макет на бойния робот | 15
4.2. Схема на задвижването на бойния робот | 16
4.3. Схема на задвижването на механичната ръка | 18
4.4. Схема на задвижването на оръжието | 20
5.1. Радиочестотен модул в робота | 22
5.2. Оптрон | 22
5.3. Преобразувател на логически нива | 23
5.4. оптични сензори | 24
5.5. Крайни изключватели за ръката | 24
5.6. Защити на захранването | 25
5.7. Захранване на логическата част в робота | 26
5.8. Печатна платка на робота | 27
5.9. Радиочестотен модул в пулта за управление | 29
5.10. Сензори в пулта за управление | 29
5.11. Печатна платка на пулта за управление | 30
6.1. Логическа схема на дистанционното | 32
6.2. Логическа схема на робота | 33

Б.1. На следващата страница е електрическата схема на робота 55
Б.2. Печатна платка на робот | 57
Б.3. На следващата страница е монтажната схема на робота . . 65 Б.4. На следващата страница е електрическата схема на пулта
за управление | 67
Б.5. Печатна платка на пълта за управление | 69

3

# Списък на таблиците

2.1. Сравнителна таблица за безжични технологии | 10
А.1. Използвани елементи в печатната платка на робота | 51
А.2. Конфигурация на изводите на микроконтролера на робота . . 52

4

# Listings

6.1. Пакет инструкции | 32
6.2. Писане в регистър | 34
6.3. Четене на регистър | 34
6.4. Писане на големи регистри | 35
6.5. Четене на големи регистри | 36
6.6. Инициализация на радио модула | 37
6.7. Конфигуриране на изпращач на данни | 37
6.8. Конфигуриране на получател на данни | 38
6.9. Изпращане на пакет инструкции | 39
6.10. Зареждане на пакет инструкции | 40
6.11. Проверка дали има получен пакет инструкции | 41
6.12. Получаване на пакет инструкции | 41
6.13. Конфигуриране на пин | 43
6.14. Работен цикъл | 43
6.15. Конфигуриране на пин | 44
6.16. Работен цикъл | 45
6.17. Управление на четковите мотори | 45
6.18. Управление на стъпковия мотор | 46
6.19. Външни прекъсвания | 47
6.20. Прекъсвания при преливане | 48

5

# Увод

1

Още от зората си, човечеството търси разнообразни и вълнуващи начини да успее да избяга от еднообразното си ежедневие. За целта много и различни методи за развлечение са възникнали, вариращи от приятелски игри до зрелищни спектакли. Едно от най-разпространените забавления още от тогава е също толкова популярно и днес, а именно – боевете. Зрелището на това два индивида да се бият помежду си завладява всеки зрител. Годините са доказали, че колкото по-драматична е една битка, толкова по-силни са чувствата, които се пораждат у нейните наблюдатели. Но това води до един неизбежен проблем: участниците в такива интензивни битки винаги биват физически наранени. Поради тази причина се появява казусът как може да се постигнат тези зрелища, без участниците да пострадат. Решението на този проблем са битките с бойни роботи (или батълботи). Стандартна битка трае 3 минути и в тях роботизираните системи, контролирани чрез дистанционно управление, целят увреждането на опонента до такава степен, че вече да не може да извършва движения.

6

# Методи, средства и методологии за изработване на бойни роботи

2

## 2.1 Основни методи и технологии за задвижване на бойни роботи

Бойните роботи традиционно могат да се задвижват по три начина чрез вериги, колела или механични крака. Има и други начини, но те не са ефективни в битка. Роботите, задвижвани с танкови вериги, имат отлично сцепление със земята и вървят много стабилно, но имат много недостатъци. Поради голямата площ на триене при завъртане те изразходват значително количество енергия. Освен това и самото движение се извършва сравнително бавно, което позволява на опонента да заобиколи робота и да го удари в гръб. Боен робот, задвижван от верига, може да се види на фиг. 2.1.

Фигура 2.1.: Боен робот, задвижван от вериги

7

Механичните крака имат също много недостатъци. Някои от които са, че са много сложни за конструкция и контрол. Друг техен недостатък е, че те не са достатъчно здрави по време на битка, особено срещу посичащите спинер роботи. Повече за този тип бойни роботи може да се прочете в раздел 2.4. Трета слабост е, че центъра на тежестта на роботи с такава система за задвижване е много високо над земята, което ги прави уязвими срещу атаки, целящи преобръщане. Батълбот, използващ механични крака може да бъде видян на фиг. 2.2.


Фигура 2.2.: Боен робот, задвижван от механични крака

Поради гореспоменатите причини, най-често бойните роботи се задвижват чрез колела. Разпространени са два начина на управление на задвижването на моторни средства с колела – Акерман управление и диференциално управление. Акерман управлението е възприето от повечето моторни-превозни средства. При него един голям мотор задвижва колелата и един по-малък отговаря за тяхното завъртане. То е ефективно при движение в права линия, но когато трябва да се завие се изискват определени маневри. Диференциалното управление е много по-често срещано в роботиката. При него лявата и дясната страна на робота се задвижват напълно индивидуално. Недостатъкът на този метод е фактът, че за да се движи моторното средство в права линия двете половини требва да имат еднаква скорост, което е трудно за постигане. Голямото преимущество обаче е, че завиването става значително по-бързо.

### 8 Глава 2 Методи, средства и методологии за изработ-

ване на бойни роботи

Освен по начин на управление на задвижването роботите придвижващи се с колела се различават помежду си и чрез броя на задвижваните колела. При такива с две задвижващи колела и диференциално управление на задвижването, завиването се случва със сравнително ниски загуби на енергия. Проблемът е, че с две опорни точки, роботът найвероятно ще има нужда от поне още една такава. Той се решава чрез добавянето на ball transfer units.

## 2.2 Основни методи и технологии за дистанционно управление на бойни роботи

Съгласно официалните изисквания за работа към бойните роботи, те трябва да бъдат контролирани безжично дистанционно. За целта могат да се използват много технологии за безжична комуникация, като едни от най–популярните са Wi-Fi, Bluetooth и nRF24L01.

Wi-Fi позволява много висока скорост на предаване на информацията, но има много недостатъци. Един от тях е, че има много високо потребление на енергия. Друг е, че не може директно да се предава информация от едно устройство на друго безжично, а първо трябва тази информация да се подаде на маршрутизатор и след това той да я изпрати до устройството получател. Отделно по време на боевете се очаква да има голяма публика и безплатен Wi-Fi което предполага, че каналите, които се използват за тази технология ще бъдат претоварени и съответно ще има по-лоша свързаност.

Bluetooth технологията осигурява средна скорост на предаване на информация, на цената на средно ниво на консумация на енергия. Недостатъкът е, че за да могат две устройства да се свържат и да общуват безжично и двете трябва предварително да се сдвоят, което е непрактично за системи, които не включват компютри или телефони.

Модулът nRF24L01 позволява безжична радиочестотна комуникация с други такива модули. От трите технологии за безжична комуникация този модул предлага тази с най-ниско потребление на енергия. За разлика от Wi-Fi, nRF24L01 може да се комуникира с друго устройство директно, без необходимостта от маршрутизатор. Предимството му

### 2.2 Основни методи и технологии за дистанционно

управление на бойни роботи

9

пред Bluetooth е, че не е необходимо предварително двете устройства да се сдвояват.

| Wi-fi | Bluetooth | nRF24L01+
Скорост | Висока | Средно | Средна
Обхват | 10ки метри | 10 метра | 10-150 метра
Енергийна консу-мация | Висока | Средна | Ниска

Таблица 2.1.: Сравнителна таблица за безжични технологии

## 2.3 Основни методи за защита на бойни роботи

За защита на бойните роботи винаги се монтира броня около неговата структура. Видовете броня са: традиционна, аблативна и реактивна.

Традиционната броня е изработена от много здрави и твърди материали, които се стремят да абсорбират и предадат енергията на удара без да се повреждат. Високата твърдост и здравина на този вид защита често се използва за чупене или изтъпяване на остриетата на вражеските оръжия и запазване целостта на робота при удари. Благодарение на здравината си тази броня по-рядко трябва да се сменя след битки, но нейният недостатък е, че при удар енергията на сблъсъка се предава до елементите вътре в робота, което може да доведе до тяхното повреждане.

Аблативната защита, от друга страна е проектирана да предпазва от щети робота, като самата тя бива повреждана чрез процеса аблация. Това е процеса на премахване на материал от повърхността на обект посредством изпарение или стружко отделяне. Материалите, от които е изградена са също твърди и здрави, но за разлика от традиционната броня имат по-ниска твърдост. Поради това тяхно свойство, когато тези брони трябва да предпазват от силни удари, вътрешните елементи биват изложени на риск. Материали като дървото са много ефикасни представители на този вид елементи, но друг техен недостатък е, че сблъсъците водят до много визуални следи, което често носи допълнителни точки на опонента за щети.

Третия вид броня е реактивната. По време на удар тя реагира по някакъв начин, за да предотврати щети. Има различни видове реактивна

### 10 Глава 2 Методи, средства и методологии за изработ-

ване на бойни роботи броня и всяка има свой предимства и недостатъци. Пример за такъв вид защита е пласт гума между два пласта метал. Предимството й е, че в случай на удар, пластът гума би абсорбирал енергията на удара. Този вид броня не е ефективна в боевете с роботи, поради причината, че много бързо бива повреждана и спира да пази.

## 2.4 Видове съществуващи бойни роботи

Съществуват много различни видове батълботи. Основно изискване към всеки от тях е да имат поне едно оръжие, чрез което да могат да повредят опонента. В зависимост от своето оръжие роботите се разделят на 14 типа: „rammer“, „wedge“, „lifter“, „flipper“, „spearbots“, „horizontal spinner“, „sawbot“, „vertical spinner“, „drumbot“, „hammerbot“, „clamper“, „crusher“, „flamethrower“ и „multibot“. Има и други видове роботи, но те почти винаги могат да бъдат категоризирани в един от гореспоменатите видове. За ефективността на бойния робот в битка има голямо значение какво оръжие е избрано. Примерно със своите огромни дискове нанасящи разрушителни удари роботите с оръжие „vertical spinner“ са много ефективни срещу голяма част от роботите. Те имат обаче един фатален недостатък, който се изразява в това, че поради голямата скорост на въртене на съответното оръжие генерират жироскопичен ефект, който намалява осезателно скоростта им на движение, което ги прави уязвими към удари отзад. С времето в роботските боеве категориите „flipper“, „horizontal spinner“, „vertical spinner“, „drumbot“, „hammerbot“ и „clamper“ са се откроили като по-ефективни в сравнение с останалите.

### 2.4 Видове съществуващи бойни роботи 11

# Дизайн и блоковата схема на робота

3

## 3.1 Дизайн и Функционални изисквания към робота

В рамките на дипломната работа бойният робот, който се разработва, е с оръжие "hammer saw". Този вид оръжие е хибрид между пневматичните чукове и въртящите се режещи дискове. По дизайн оръжието е диск, чиято формата не е перфектен кръг, а е неправилна особена форма. Тя може да бъде видяна на фиг. 3.1. Разработения робот е вдъхновен от робота SawBlaze участник от телевизионното състезание BattleBots.

Фигура 3.1.: Хоризонтален разрез на оръжието

12

## 3.2 Блок схеми

На фиг. 3.2 и фиг. 3.3 са представени блоковите схеми на пулта за управление и робота. Със син цвят са представени устройствата слаботоковите устройства, а червен захранването и силовата електроника. Черните стрелки на схемите представляват пренос на данни, а червените - захранване.

Основния компонент в схемата на дистанционното печатната платка, върху която седи микроконтролерът и радиочестотния модул. Това което микроконтролера прави е да прочита данните от бутоните и потенциометрите и да се предават посредством радио модула до печатната платка в робота. За повече информация какъв е цикъла на работа може да се прочете раздел 6.1.

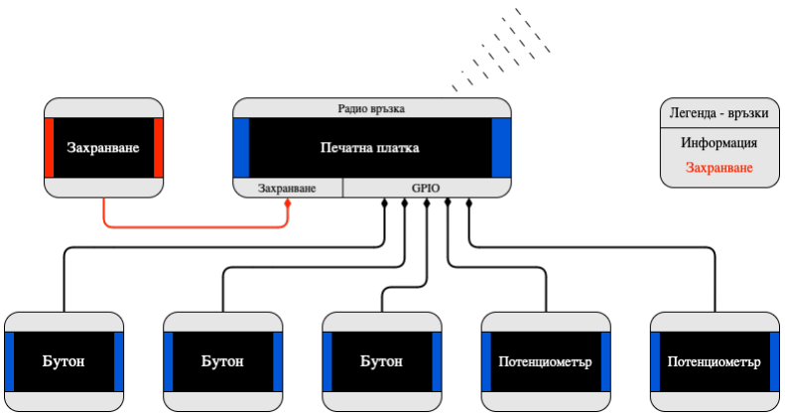
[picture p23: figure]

Фигура 3.2.: Блокова схема на дистанционното

Подобно на пулта за управление основния компонент в робота е печатната платка, защото на нея са поставени избраният микроконтролер и радиочестотния модул. Тук функцията на nRF модула е да се получават данните изпратени от дистанционното и да се предадат на микроконтролера. Той на свой ред ги изпълнява като в зависимост от тях се променя управлението на силовите компоненти. Два от четковите мотори се използват за задвижване на робота, а третия за завъртане

### 3.2 Блок схеми 13

на оръжието. Стъпковият мотор се използва за да се контролира позицията на ръката с оръжието. Успоредно на това чрез оптичните сензори се следи скоростта на четковите мотори. Освен това чрез крайните изключватели се следи стъпковия мотор да не излиза извън крайните си състояния.

Фигура 3.3.: Блокова схема на робота

### 14 Глава 3 Дизайн и блоковата схема на робота

# Механика

4

## 4.1 Цялостен модел на робота

Както е описано в предишната глава, дизайна на бойния робот е вдъхновен от робота SawBlaze. Материала, който е използван за изграждането на прототипа на проекта е два милиметра дебела студено валцована въглеродна стомана DC01. Механичната конструкция на робота може да бъде разделена на два основни компонента - шасито, в което седят почти всички елементи, и механичната ръка, на която е закрепено оръжието.

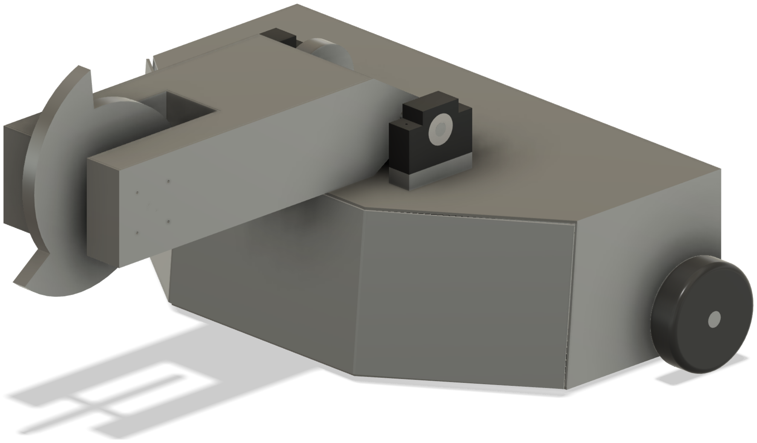
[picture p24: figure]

Фигура 4.1.: 3D макет на бойния робот

15

## 4.2 Задвижване на робота

По време на проектирането на механиката на боен робот първият проблем, който трябва да бъде разгледан е как той ще се придвижва по арената. След направеното проучване в раздел 2.1 бе установено, че най-ефективният метод е диференциалното задвижване с колела. По дизайн роботът има две задвижващи колела отдвете си страни и още две допълнителни пасивни колела, които го балансират и му помагат да се движи по-добре. Всяко от задвижващите колела е с външен диаметър 80мм и ширина 12мм. Използваните мотори за тяхното задвижване са CHANCS 895 DC.

Фигура 4.2.: Схема на задвижването на бойния робот

За да може батълбота, който тежи приблизително 18kg, да се задвижва от две колела трябва да бъде пресметнато какъв въртящ момент трябва да достига до всяко от тях 1
. За целта на изчисленията приемаме, че двете активни колела ще понасят цялото тегло на робота. Понеже на двете колела лежи тежестта от 18kg, означава, че всяко колело изпитва натиска от 9kg или еквивалентните им 88,29N. Коефициента на триене между колелата и пода на арената варира между 0,75 когато робота е в покой и 0,65 когато е в движение. Следователно

1Изчисленията са извършени като се приема, че роботът се движи на равна повърхност

### 16 Глава 4 Механика

най-голямата сила на съпротивление, която всяко колело може да генерира без самото колело да се върти е 88,29N х 0.75 = 66,2175N. След като диаметъра на колелото е 80мм следва, че радиусът му е 40мм или 0,04м. Следователно минималният въртящ момент, който позволява на колелата да се въртят е равен на 66,2175N x 0,04m = 2,6487Nm. Следователно минималният въртящ момент, който мотора трябва да достави на колелото е 2,6487Nm, но по време на въртенето си той има само 0,735Nm.

Поради тази причина се налага да се направи редукция на скоростта на мотора за да се увеличи неговия въртящ момент. За да се изчисли каква трябва да бъде нужната редукция трябва да се намери отношението на необходимият въртящ момент и този, който може да бъде генериран. Редукцията, която се получава, че трябва да бъде реализирана между мотора и колелото е минимум 2,6487Nm / 0,735Nm = 3,6.

Начинът, по който е реализирано диференциалното задвижване е като всяко от активните колела бива задвижвано от различен мотор. Връзката между тях е реализирана, чрез зъбчат ремък с ширина 10мм. За да се постигне необходимата редукция, отношението на зъбите на ремъчните ролки на осите на колелата и тези на моторите трябва да бъде равно на нея. Поради това използваните ролки на моторите са с по 10 зъба, а другите са с по 36 зъба. С цел намаляване на триенето между осите на колелата и стените, осите са захванати с лагери в специално изработените за целта лагерни опори, закрепени за стените.

## 4.3 Задвижване на ръката

Първата специфична функционалност на разработения боен робот е начина, по който механичната ръка се върти около оста си и се задържа на позицията, на която и бива зададено да седи. Тази задача бива изпълнена чрез употребата на стъпков мотор Nema 24.

За да може ръката да се върти около оста си първо трябва да бъде изчислено какъв въртящ момент ще бъде необходим за целта. Тежестта на ръката е приблизително 4kg, което означава, че силата която е нужно да бъде приложена за да може тя да се завърти е 39,24N. За да пресметнем колко е необходимият въртящ момент за нейното

### 4.3 Задвижване на ръката 17

завъртане е необходимо получената сила да бъде умножена по дължината на ръката, която е 240мм(0,24м). По този начин получаваме, че трябва да бъдат приложени 39,24N х 0,24м = 9,4176Nm. Употребеният стъпков мотор може да задържа на една позиция само товари, които изискват въртящ момент 3,1Nm или по-малко, от което следва, че се налага да бъде приложена минимална редукция от 3,03 за да може да бъде реализирано въртенето на ръката.


Фигура 4.3.: Схема на задвижването на механичната ръка

Начинът, по който е осъществено завъртането на ръката е като тя бива захваната за своята ос така, че чрез завъртането на оста ръката да бъде придвижена заедно с нея. Предаването на движението от стъпковия мотор към оста на ръката е постигнато посредством зъбни ремъци. С цел максималното увеличение на приложената редукция е поставена спомагателна ос между мотора и оста на ръката. По този начин се получават две редукции на движението на мотора. Първата бива от мотора към спомагателната ос, като поставената ролка на

### 18 Глава 4 Механика

мотора има 12 зъба, а тази на спомагателната ос 36 зъба. Постиганата редукция чрез тази връзка е 3. Втората редукция бива от спомагателната ос към оста на ръката и използваните ролки са в същото отношение като тези в предишната предавка. Резултатът от двете връзки е, че общата редукция на скоростта на въртене на мотора се получава да бъде умножението на двете, от които е съставена, което я прави 9. За намаляване на съпротивлението по време на въртенето си са поставени лагерни опори в краищата на двете оси.

## 4.4 Задвижване на оръжието

Друг проблем, който трябва да бъде решен по време на проектирането на механиката на всеки боен робот е по какъв начин неговото оръжие ще се задвижва. Както е описано в точка раздел 3.2 оръжието, което се използва в разработения проект е 180-милиметров диск с ширина 8мм и специфична форма. Формата на диска може да бъде видяна на фигура фиг. 3.1. Той е захванат за своята ос така, че чрез завъртането на оста и диска да се върти заедно с нея. Използваният мотор за движението на оръжието е CHANCS 895 DC. Начина, по който е реализирано предаването на движението от мотора до оста на диска е посредством плосък ремък. Избран е плосък ремък за тази цел, а не зъбчат поради причината, че при удар ремъка и мотора трябва отведнъж да спрат своето движение, което често може да доведе до прескачане на зъби на зъбчатия ремък и тяхното ронене. В тези ситуации плоския ремък няма да се амортизира по този начин, а само ще се приплъзне леко по своите ролки. Реализирана е и редукция от 5 на скоростта на тази предавка поради високата скорост, с която би се въртял диска. С цел намаляване на съпротивлението по време на въртенето си в краищата си оста на диска е поставен в лагерни опори, които са застопорени за стените на ръката.

### 4.4 Задвижване на оръжието 19

Фигура 4.4.: Схема на задвижването на оръжието

### 20 Глава 4 Механика

# Проектиране на печатните платки

5

За проектирането на печатните платки и монтажните схеми в проекта е използван софтуерния пакет KiCad. Той е избран за целта, защото е безплатен и има богата библиотека с компоненти, съдържащи символи и очертания на корпуси.

## 5.1 Принципна електрическа схема на робота

Принципната електрическа схема на печатната платка в робота може да бъде видяна на фиг. Б.1. Основният елемент на схемата е микроконтролерът STM32F103C8T6 (blue pill), който управлява останалите компоненти. Използваните компоненти в проектирането на тази печатната платка могат да бъдат видяни в таблица табл. А.2.

### 5.1.1 Радиочестотен модул

Връзката между дистанционното и робота се осъществява посредством nRF24L01+ PA/LNA радиочестотен модул. Комуникацията между него и използвания микроконтролер е посредством SPI интерфейс. Радиочестотният модул бива захранван с 3,3V от вградения регулатор на напрежението на blue pill. С цел повишаване на съотношението сигнал/шум са поставени 100nF керамичен кондензатор и 100uF електролитен кондензатор, които да намалят съответно високочестотните и нискочестотните шумове.

предавател по далеч / мощни мотори = повече шум слаб сигнал

21


Фигура 5.1.: Радиочестотен модул в робота

### 5.1.2 Управление на моторите

Управлението на постоянно токовите четкови мотори се извършва посредством MD13S драйвери. Необходимите логически сигнали за да може да се реализира управлението са ШИМ сиганл, който упоменава скоростта, с която мотора трябва да се върти, и високо или ниско ниво, което да показва посоката на движение. С цел постигане на галванична изолация между микроконтролера и драйверите са поставени оптрони. Начинът на свързване на всеки оптрон може да бъде видян на фиг. 5.2. Необходимото захранване на всеки мотор е 24V и то бива подадено посредством отделен конектор.

Фигура 5.2.: Оптрон

За управлението на стъпковия мотор се използва драйвер DM556T. Сигналите за управление включват , поредица от импулси, които указват колко стъпки трябва да бъдат направени и логическо ниво (високо или ниско), указващо посоката им. Не е поставен допълнителен оптрон

### 22 Глава 5 Проектиране на печатните платки

за изолация между драйвера и микроконтролера, поради причината, че на входовете си DM556T има вградени такива. Така направена схемата обаче няма да работи, защото логика на blue pill-а е на 3,3V, докато драйвера използва 5V логика. Този проблем бива решен като се използва преобразувател на логически нива U12, който превежда логическото управление от 3,3V към 5V, съответстващо на логиката, използвана от драйвера.


Фигура 5.3.: Преобразувател на логически нива

### 5.1.3 Сензори

За следене на скоростта на робота са предвидени и инсталирани оптични сензори. Те биват свързвани към печатната плака чрез конекторите J10, J11 и J12. Всеки сензор има извод за данни и изводи за захранване. Сигналите от оптичните сензори минават през пасивни нискочестотни RC филтри с цел да се премахнат потенциални смущения.

### 5.1 Принципна електрическа схема на робота 23

Фигура 5.4.: оптични сензори

Съгласно изискванията за безопасност са предвидени и крайни изключватели, които да следят дали стъпковият мотор е достигнал някоя от крайните си позиции. Те са свързани, чрез конекторите J13 и J14


Фигура 5.5.: Крайни изключватели за ръката

### 24 Глава 5 Проектиране на печатните платки

### 5.1.4 Захранване на печатната платка

Печатната платка се захранва директно от 24V постояннотокова батерия. Съгласно изискванията за безопасност изводите на конектор J15 са предвидени за ключ, който да спира цялото захранване на робота. Освен това има имплементирани хардуерни защити против късо съединение, пренапрежение и обратен поляритет на захранването. Първата от трите е реализирана чрез поставянето на автомобилен бушон на държача X1 последователно свързан след главния ключ. Защитата против пренапрежение се осъществява посредством двупосочния трансил D3. С цел защита против неправилен поляритет на напрежението е поставена P-MOS защита след трансила. Тя се реализира чрез транзистора Q2, ценеровия диод D1 и резистора R1. При правилното свързване на батерията през диода в Q1 протича ток. Поради образувания делител на напрежение D1 и R1, напрежението гейт-сорс на Q2 става равно на пробивното напрежение на D1 и транзисторът се отпушва. В случай, че батерията бъде свързана с обратен поляритет, диодът в Q1 бива свързан в обратна посока и транзисторът остава запушен. Във веригата е поставен и кондензатора C7 за да стабилизира напрежението върху ценера D1.

Фигура 5.6.: Защити на захранването

Захранването на логическата част на проекта е постигнато посредством линейни стабилизатори L7805. Tо е разделено на два канала за да може да бъдат намалени шумовете в захранването на микроконтролера и радиочестотния модул. По-чувствителните към шумове елементи разполагат с отдлно захранване.

### 5.1 Принципна електрическа схема на робота 25

Първият канал използва стабилизатора U4 за да успее да свали напрежението до 5V, които да бъдат подадени после на оптроните на логическата част на четковите мотори и на логическия преобразовател на стъпковия мотор. Той е показан на фиг. 5.7а. За намаляване на шумовете в системата са поставени електролитния кондензатор C5 и керамичния C4 и C6.

Второто захранване е почти идентичен с първия. Той се използва за захранването на микроконтролера, радиочестотния модул и сензорите в робота. Може да бъде видян на фиг. 5.7б. Това захранване допълнително разполага с индуктор L1, който блокира смущения.


(а) Захранване на логиката на силовата електроника

(б) Захранване на микроконтролера, радиочестотния модул и сензорите

Фигура 5.7.: Захранване на логическата част в робота.

### 26 Глава 5 Проектиране на печатните платки

## 5.2 Опроводяване на печатната платка на робота

На фиг. 5.8 могат да се видят двата слоя на печатната платка. Захранващата мрежа +24V е опроводена чрез медни зони. При проектирането и е спазена добрата практика, когато има две различни напрежения на печатната платка те да бъдат отделени максимално далеч едно от друго. По останалата част от проводниците се движат или +5V, или от +3.3V. Голямата медна област от долната страна се използва за земя. В 3 от четирите ъгъла могат да бъдат видени предвидените монтажни отвори за закрепване на платката. Особеност на тази платка е неизбежното застъпването на U1 и U12. В общия случай подобно разположение на елементите е груба грешка, но U1 е модул, монтиран на стандартни рейки. Това оставя повече от достатъчно пространство U12 да бъде поставен.

В фиг. Б.2 са показани поотделно всеки слой на печатната платка.


Фигура 5.8.: Печатна платка на робота

### 5.2 Опроводяване на печатната платка на робота 27

## 5.3 Монтажна схема на робота

Монтажната схема на робота може да бъде намерена в фиг. Б.3. На нея може да се види основната част в робота, представляваща разработената печатна платка, която съдържа радиочестотния модул за комуникация, микроконтролера, управляващ робота, и хардуерните защити на захранването. Нейното захранване индва от 24V батерия DeWalt DE0241 и съгласно изисканията за безопасност във всеки момент то може да бъде прекъснато чрез ключът SW1. Разработената платка захранва и управлява 3 постояннотокови четкови мотори с помощта на драйвери MD13S. С цел мониторинг на тяхната скорост е предвидено на всеки от тях да има монтиран по един оптичен сензор за скорост. Използваният nema 24 стъпков мотор се управлява посредством DM556T драйвер. Начинат на свързване на драйвера към печатната платка е конфигурация общ катод. Съгласно изискванията за безопасност чрез SW1 и SW2 се следи дали стъпковият мотор не е стигнал до крайните си състояния.

## 5.4 Принципна електрическа схема на пулта за управление

Принципната електрическа схема на печатната платка на дистанционното може да бъде видяна на фиг. Б.4. Основният елемент на схемата е микроконтролерът STM32F103C8T6 (blue pill), който чете данните от сензорите, обработва ги и после ги праща към робота посредством радиочестотния модул. Връзката между него и микроконтролера е идентична на тази описана в раздел 5.1.1. Захранването на пулта за управление на бойния робот се реализира посредством USB извода на използвания микроконтролер.

### 28 Глава 5 Проектиране на печатните платки

Фигура 5.9.: Радиочестотен модул в пулта за управление

### 5.4.1 Сензори

Компонентите, които се използват за четене на инструкциите от пилота на бойния робот са 2 потенциометъра и 3 бутона. Потенциометрите са свързани посредством конекторите J4, J5 и J6. Връзката с бутоните е осъществена чрез конекторите J1, J2 и J3.


Фигура 5.10.: Сензори в пулта за управление

## 5.5 Опроводяване на печатната платка на дистанционното

На фиг. 5.8 могат да се видят двата слоя на печатната платка на дистанционното. По проводниците, които могат да се видят, се движат 3,3V. Голямата медна област, която се забелязва се използва за земя. Забелязва се и липсата на монтажни отвори. Причината за тяхното

### 5.5 Опроводяване на печатната платка на дистанци-

онното

29


отсъствие е това, че платката е предвидена да бъде легнала на страна
спойки във специално по размери 3D принтирано легло.

В фиг. Б.5 са показани поотделно всеки слой на печатната платка.

Фигура 5.11.: Печатна платка на пулта за управление

30 Глава 5 Проектиране на печатните платки

# Софтуерна реализация

6

Използваната среда за разработка на софтуерната част от дипломния проект е софтуерния пакет STM32CubbeIDE на STMicroelectronics. Тази платформа е предназначена за изграждане на софтуерното управление на STM микроконтролери и микропроцесори. Чрез интеграцията на GNU GCC компилатор и GBD дебъгер, тя предоставя стабилна среда за разработка на C/C++ програми. В STM32CubbeIDE е интегриран и графичния инструмент STM32CubeMX. Той улеснява конфигурацията и инициализацията на различни части и периферии на микроконтролерите, сред които са пинове, таймери, системни прекъсвания и DMA заявки. Друга основна характеристика на избраната среда за разработка е възможността за подробен дебъгване чрез мониторинг на процесорните ядра, регистрите на периферията, паметта и заделените променливи и други. Софтуерният пакет може да бъде свален безплатно от сайта на STMicroelectronics за 64-битовите версии на операционните системи Windows, Linux и macOS. Поради споменатите причини тази среда за разработка беше използвана за проекта.

## 6.1 Логическа схема на проекта

Съгласно заданието на дипломния проект разработеният боен робот бива управляван посредством специално изработено дистанционно. Комуникацията между тях бива реализирана посредством радиочестотните модули nRF24L01 на компанията Nordic. Те използват вградения си протокол за комуникация Enhanced ShockBurst, който е предназначен за лесна комуникация с ниска енергийна консумация.

Като се получи захранване микроконтролера и радиочестотния модул в дистанционното биват инициализирани. След това започва непрекъснато повтарящият се на равни интерваи цикъл на работа. Първо се прочитат входните данни от потенциометрите и бутоните. След това те биват обработени и записани в подходящ вид. В края на този цикъл обработените потребителски команди биват записани в пакет

31 с инструкции за контрол на бойния робот и той бива изпратен към батълбота за изпълнение. После цикъла на работа на дистанционното започва да се изпълнява отначало. Микроконтролерът е настроен да може да бъдат изпращани по 20 пакета с команди в секунда. Това скорост гарантира на пилота възможността да може да управлява своята машина с минимално системно забавяне.

Фигура 6.1.: Логическа схема на дистанционното

Полетата, които се съдържат в изпратения пакет са инструкция за позицията, на която трябва да застане механичната ръка на робота, инструкции за скоростта и посоката на въртене на двете колела и инструкция за това дали оръжието трябва да се върти. Структурата на такъв пакет може да бъде видяна на Програмен код 6.1.

11 typedef struct
12 {
13 | int8_t hand_position; // hand position (-100 ~ +100)
14 | int8_t left_speed; | // left wheel speed | (-100 ~ +100)
15 | int8_t right_speed; | // right wheel speed (-100 ~ +100)
16 | uint8_t weapon; | // weapon on/off (0 / 1)
17 } Payload;

Програмен код 6.1: Пакет инструкции

Подобно на дистанционното първата работа на печатната платка, когато получи захранване е да се инициализират микроконтролера и

### 32 Глава 6 Софтуерна реализация

радиочестотния модул. След това започва непрекъснат цикъл на проверяване дали има получен пакет инструкции и ако има се прави опит той да бъде достъпен. При успешното им прочитане те биват заредени в паметта на платката и биват изпълнени. След тази стъпка следва повторно започване на работния цикъл на робота. В случаите, в които няма получени инструкции или не бъде успешно тяхното прочитане, цикъла на работа започва отначало и се спира движението на робота.


Фигура 6.2.: Логическа схема на робота
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

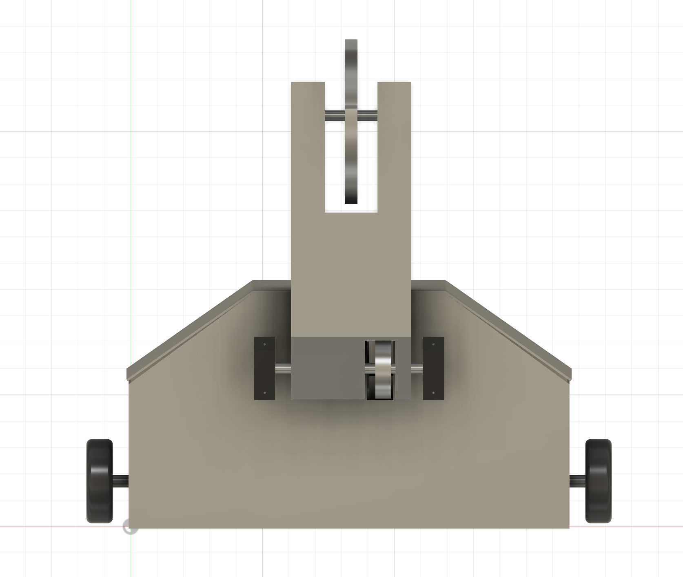
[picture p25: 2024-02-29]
documentation/documentation/images/robot-top.png

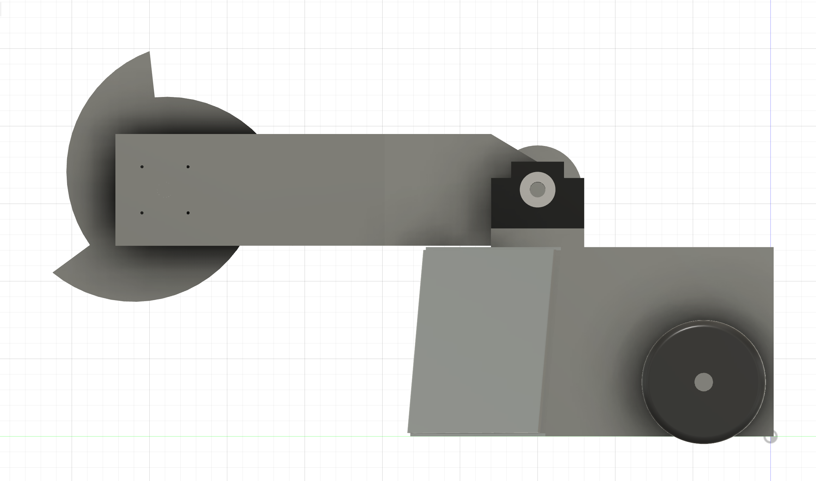
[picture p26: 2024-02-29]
documentation/documentation/images/robot-side.png

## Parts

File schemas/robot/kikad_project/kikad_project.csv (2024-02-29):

Source: | /Users/sasukoboy/Documents/GitHub/dread/schemas/robot/kikad_project/kikad_project.kicad_sch
Date: | Thursday, February 29, 2024 at 11:07:16 AM
Tool: | Eeschema 7.0.9
Generator: | /Applications/KiCad/KiCad.app/Contents/SharedSupport/plugins/bom_csv_grouped_by_value.py
Component Count: | 50
Collated Components:
Item | Qty | Reference(s) | Value | LibPart | Footprint | Datasheet | DNP | Availability | Check_prices | Description | DigiKey_Part_Number | MANUFACTURER | MAXIMUM_PACKAGE_HEIGHT | MF | MP | MPN | OC_FARNELL | OC_NEWARK | PARTREV | Package | Price | Purchase-URL | RS_Components_1676068_Purchase_URL | SNAPEDA_PN | STANDARD | SnapEDA_Link
1 | 3 | C1, C5, C8 | 100uF | Device:C | Capacitor_THT:CP_Radial_D5.0mm_P2.00mm | ~
2 | 6 | C2, C3, C4, C6, C7, C9 | 100nF | Device:C | Capacitor_THT:C_Axial_L5.1mm_D3.1mm_P7.50mm_Horizontal | ~
3 | 3 | C10, C11, C12 | 100nF | Device:C | Capacitor_THT:CP_Radial_D5.0mm_P2.00mm | ~
4 | 1 | D1 | BZX85C10-TAP | BZX85C10-TAP:BZX85C10-TAP | BZX85C10-TAP:DO-41_VIS | BZX85C10-TAP
5 | 1 | D3 | P6KE27CA | P6KE27CA:P6KE27CA | P6KE27CA:DIOAD1300W80L670D310 |  |  | In Stock | https://www.snapeda.com/parts/P6KE27CA/Taiwan+Semiconductor/view-part/?ref=eda | 600W, 27V, 5%, Bidirectional, TVS |  | Taiwan Semiconductor | 3.6 mm | Taiwan Semiconductor | P6KE27CA |  |  |  | K2105 | DO-15 Taiwan Semiconductor | None | https://www.snapeda.com/api/url_track_click_mouser/?unipart_id=4809733&manufacturer=Taiwan Semiconductor&part_name=P6KE27CA&search_term=p6ke27ca |  |  | IPC-7351B | https://www.snapeda.com/parts/P6KE27CA/Taiwan+Semiconductor/view-part/?ref=snap
6 | 3 | H1, H2, H3 | MountingHole_Pad | Mechanical:MountingHole_Pad | MountingHole:MountingHole_3.2mm_M3_Pad | ~
7 | 3 | IC1, IC2, IC3 | HCPL-2531 | HCPL-2531:HCPL-2531 | HCPL-2531:DIL08 |  |  | In Stock | https://www.snapeda.com/parts/HCPL-2531/Broadcom+Limited/view-part/?ref=eda | Optoisolator Transistor Output 3750Vrms 2 Channel 8-DIP Gull Wing |  |  |  | Broadcom Limited | HCPL-2531 | HCPL-2531A-000E | 8550026 | 88H7847 |  | DIP-8 Broadcom / Avago | None |  |  |  |  | https://www.snapeda.com/parts/HCPL-2531/Broadcom+Limited/view-part/?ref=snap
8 | 1 | J1 | 236-102 | 236-102:236-102 | 236-102:CONN_236-102_WAG | 236-102
9 | 1 | J2 | 236-104 | 236-104:236-104 | 236-104:CONN_236-104_WAG | 236-104
10 | 1 | J3 | 236-102 | :236-102_1 | 236-102:CONN_236-102_WAG | 236-102
11 | 3 | J4, J7, J16 | 236-102 | :236-102_5 | 236-102:CONN_236-102_WAG | 236-102
12 | 4 | J5, J8, J12, J17 | 236-401 | 236-744:236-744 | 236-744:236-744_WAG | 236-744
13 | 3 | J6, J9, J18 | 236-102 | :236-102_3 | 236-102:CONN_236-102_WAG | 236-102
14 | 1 | J10 | 236-104 | :236-104_1 | 236-104:CONN_236-104_WAG | 236-104
15 | 1 | J11 | 236-104 | :236-104_4 | 236-104:CONN_236-104_WAG | 236-104
16 | 2 | J13, J14 | 236-102 | :236-102_2 | 236-102:CONN_236-102_WAG | 236-102
17 | 1 | J15 | 236-102 | :236-102_4 | 236-102:CONN_236-102_WAG | 236-102
18 | 1 | L1 | 2.2uH | Device:L | Inductor_THT:L_Axial_L16.0mm_D7.5mm_P5.08mm_Vertical_Fastron_XHBCC | ~
19 | 1 | Q1 | IXTP120P065T | Transistor_FET:IRF540N | Package_TO_SOT_THT:TO-220-3_Vertical | http://www.irf.com/product-info/datasheets/data/irf540n.pdf
20 | 1 | R1 | 8.2kR | Device:R | Resistor_THT:R_Axial_DIN0207_L6.3mm_D2.5mm_P10.16mm_Horizontal | ~
21 | 3 | R2, R3, R4 | 680R | Device:R | Resistor_THT:R_Axial_DIN0207_L6.3mm_D2.5mm_P10.16mm_Horizontal | ~
22 | 1 | U1 | NRF24L01_Breakout | RF:NRF24L01_Breakout | RF_Module:nRF24L01_Breakout | http://www.nordicsemi.com/eng/content/download/2730/34105/file/nRF24L01_Product_Specification_v2_0.pdf
23 | 1 | U2 | STM32F103C8T6 | Robot_Symbols:STM32F103C8T6_pinout | Library:STM32F103C8T6_pinout
24 | 2 | U3, U4 | L7805 | Regulator_Linear:L7805 | Package_TO_SOT_THT:TO-220-3_Vertical | http://www.st.com/content/ccc/resource/technical/document/datasheet/41/4f/b3/b0/12/d4/47/88/CD00000444.pdf/files/CD00000444.pdf/jcr:content/translations/en.CD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
25 | 1 | U12 | CD40109BE | CD40109BE:CD40109BE | CD40109BE:DIP794W45P254L1969H508Q16 |  |  |  | https://www.snapeda.com/parts/CD40109BE/Texas+Instruments/view-part/?ref=eda | CMOS Quad Low-to-High Voltage Level Shifter (20V Rating) | 2156-CD40109BE-ND |  |  | Texas Instruments | CD40109BE |  |  |  |  | PDIP-16 Texas Instruments |  | https://www.snapeda.com/api/url_track_click_mouser/?unipart_id=78965&manufacturer=Texas Instruments&part_name=CD40109BE&search_term=cd40109be |  |  |  | https://www.snapeda.com/parts/CD40109BE/Texas+Instruments/view-part/?ref=snap
26 | 1 | X1 | 3522-2 | 3522-2:3522-2 | 3522-2:FUSE_3522-2 |  |  |  | https://www.snapeda.com/parts/3522-2/Keystone+Electronics/view-part/?ref=eda | Fuse Holder, Auto Blade, THM, Vertical, 1 Cell, Fuse Size Std., 20 A | Keystone Electronics 3522-2 |  | Keystone | 6.73mm | Keystone Electronics | 3522-2 |  |  |  | J | None |  | https://www.snapeda.com/api/url_track_click_mouser/?unipart_id=278059&manufacturer=Keystone Electronics&part_name=3522-2&search_term=keystone 3522-2 | https://www.snapeda.com/api/url_track_click/https%253A//uk.rs-online.com/web/p/fuse-holders/1676068//%253Futm_campaign%253Dbuynow%2526utm_medium%253Daggregato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 Electronics&part_name=3522-2&search_term=keystone 3522-2 | 3522-2 | Manufacturer Recommendations | https://www.snapeda.com/parts/3522-2/Keystone+Electronics/view-part/?ref=snap

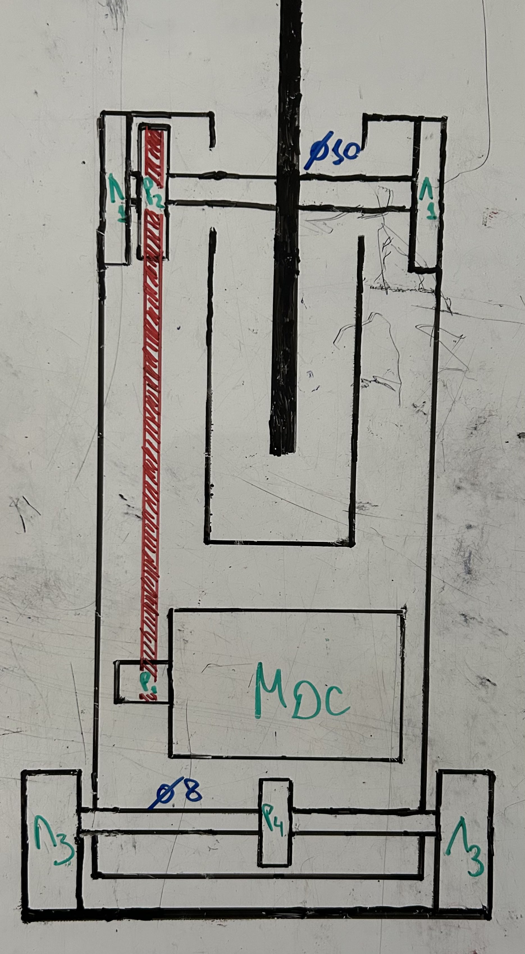
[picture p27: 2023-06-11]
materials/hand.jpg

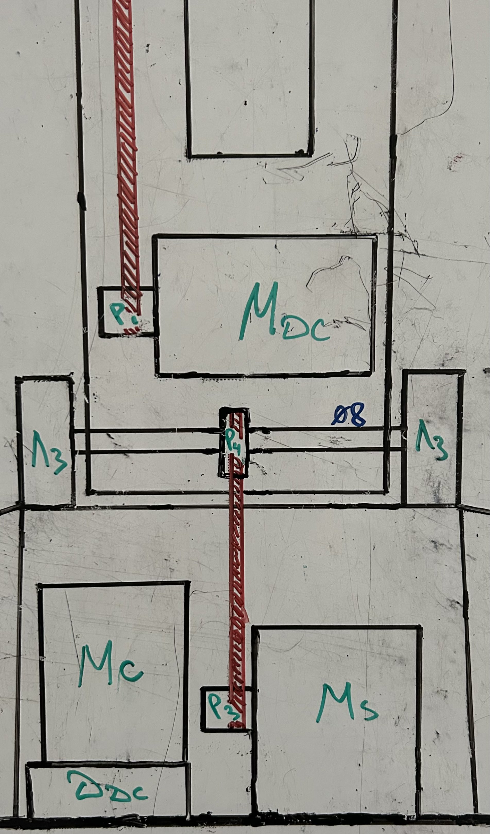
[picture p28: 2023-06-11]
materials/front.jpg

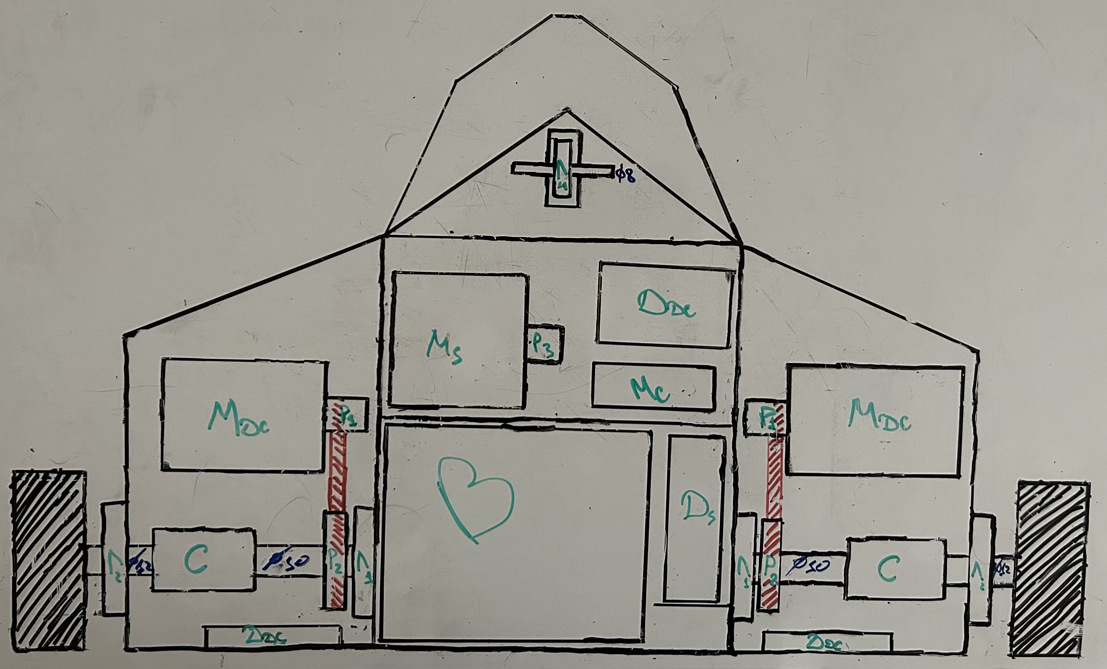
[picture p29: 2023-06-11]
materials/body.jpg

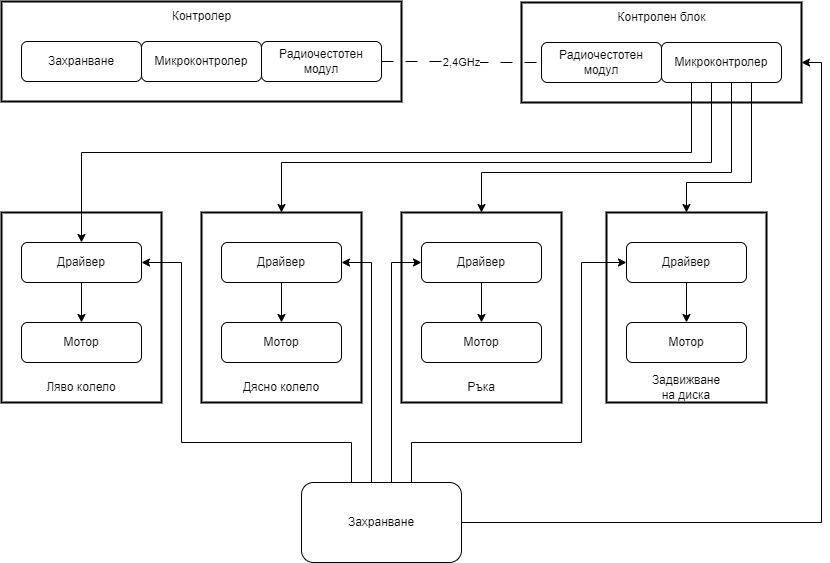
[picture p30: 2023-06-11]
materials/TrueBlockShema.png

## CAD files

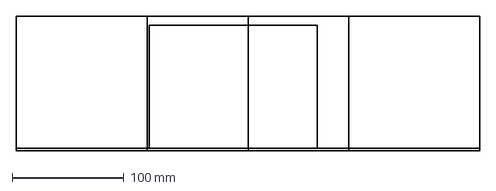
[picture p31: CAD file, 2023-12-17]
3d model/for cutting/back.dxf
414.0 x 120.0 mm

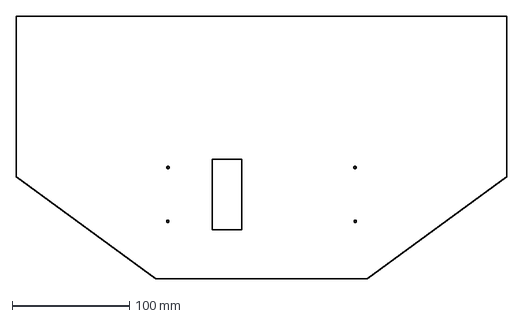
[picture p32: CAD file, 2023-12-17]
3d model/for cutting/body/body top.dxf
418.0 x 224.0 mm

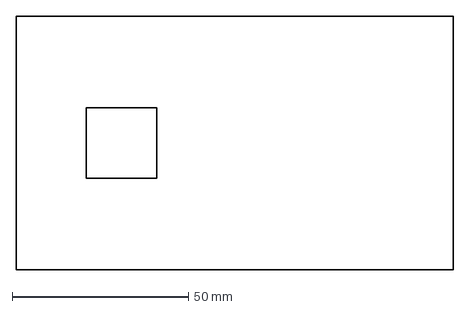
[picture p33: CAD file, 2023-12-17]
3d model/for cutting/hand/hand inner wall.dxf
124.0 x 72.0 mm

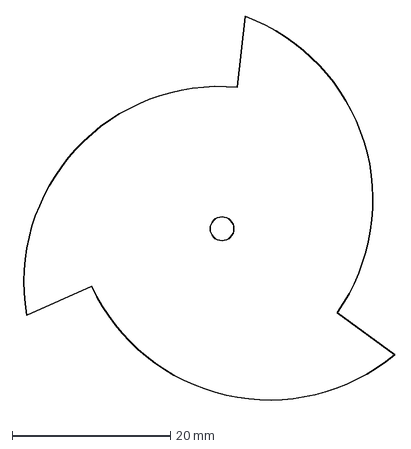
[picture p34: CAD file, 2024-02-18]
3d model/for cutting/other/disk_small.dxf
47.8 x 49.6 mm

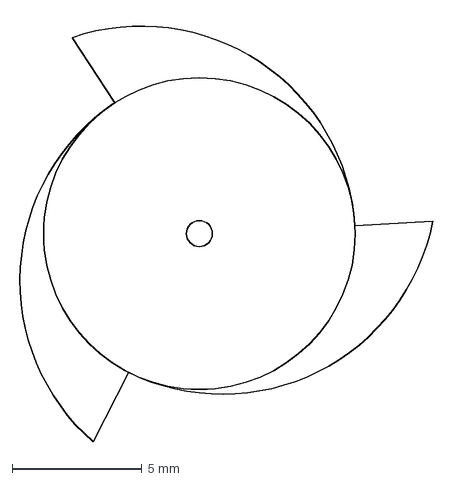
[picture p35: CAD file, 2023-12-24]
schemas/robot/kikad_project/disk.dxf
16.0 x 16.4 mm

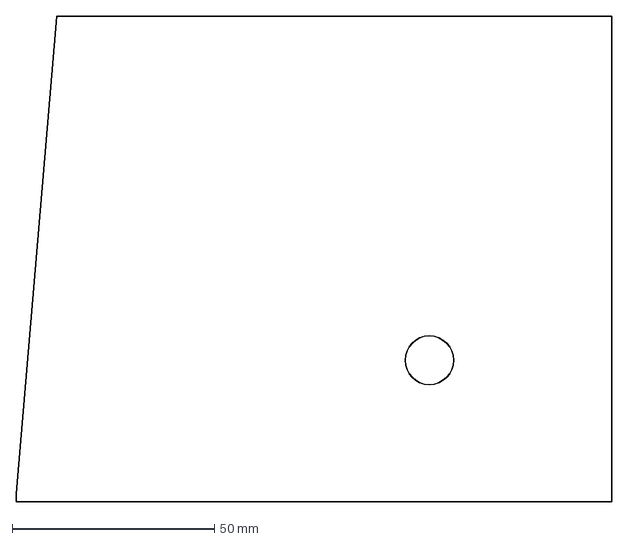
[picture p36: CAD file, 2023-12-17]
3d model/for cutting/body/body outer wall.dxf
147.0 x 120.0 mm

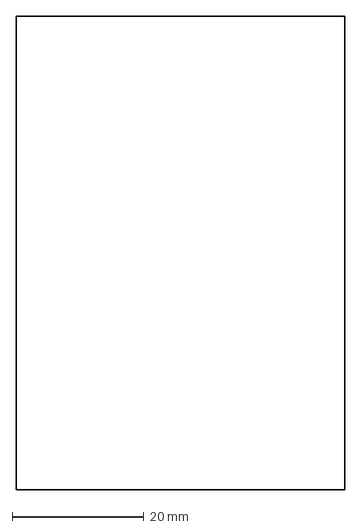
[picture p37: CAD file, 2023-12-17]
3d model/for cutting/hand/hand inner wall back.dxf
50.0 x 72.0 mm

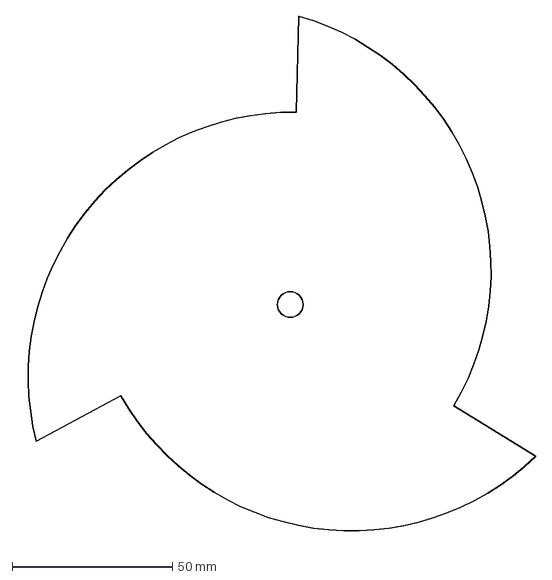
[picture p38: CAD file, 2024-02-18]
3d model/for cutting/other/disk.dxf
162.1 x 163.4 mm

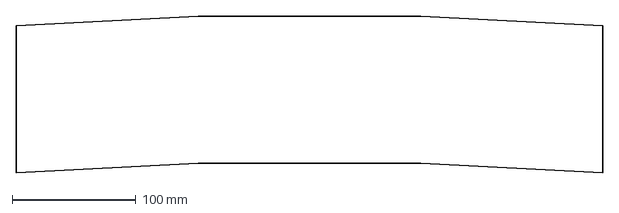
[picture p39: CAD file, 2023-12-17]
3d model/for cutting/body/body front.dxf
473.3 x 126.1 mm

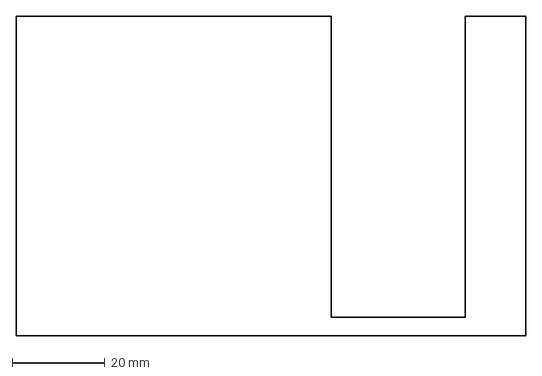
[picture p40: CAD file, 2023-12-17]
3d model/for cutting/hand/hand side.dxf
110.0 x 69.0 mm

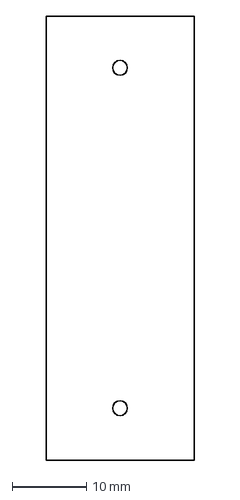
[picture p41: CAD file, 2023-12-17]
3d model/for cutting/other/shtender.dxf
20.0 x 60.0 mm

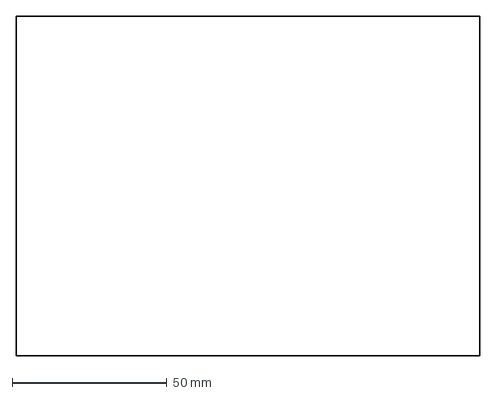
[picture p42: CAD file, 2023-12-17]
3d model/for cutting/body/body back door.dxf
150.0 x 110.0 mm

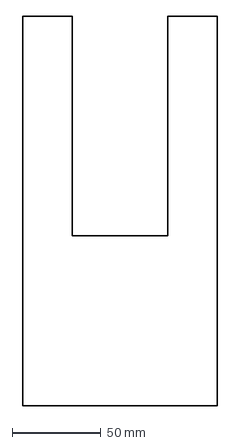
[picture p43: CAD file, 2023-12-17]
3d model/for cutting/hand/hand bottom.dxf
110.0 x 220.0 mm

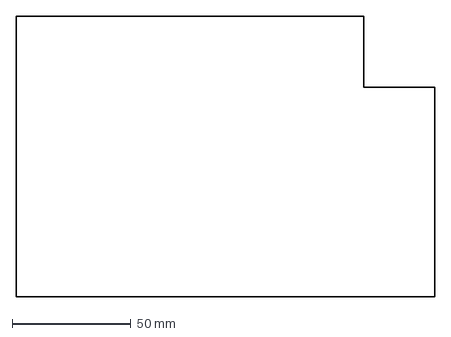
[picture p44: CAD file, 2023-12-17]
3d model/for cutting/body/body inner center wall.dxf
176.0 x 118.0 mm

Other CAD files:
3d model/for cutting/hand/hand outer wall.dxf
3d model/for cutting/body/body back.dxf
3d model/for cutting/hand/hand outer wall front.dxf
3d model/for cutting/body/body bottom.dxf
3d model/for cutting/body/body inner front level.dxf
3d model/for cutting/body/body inner wall.dxf

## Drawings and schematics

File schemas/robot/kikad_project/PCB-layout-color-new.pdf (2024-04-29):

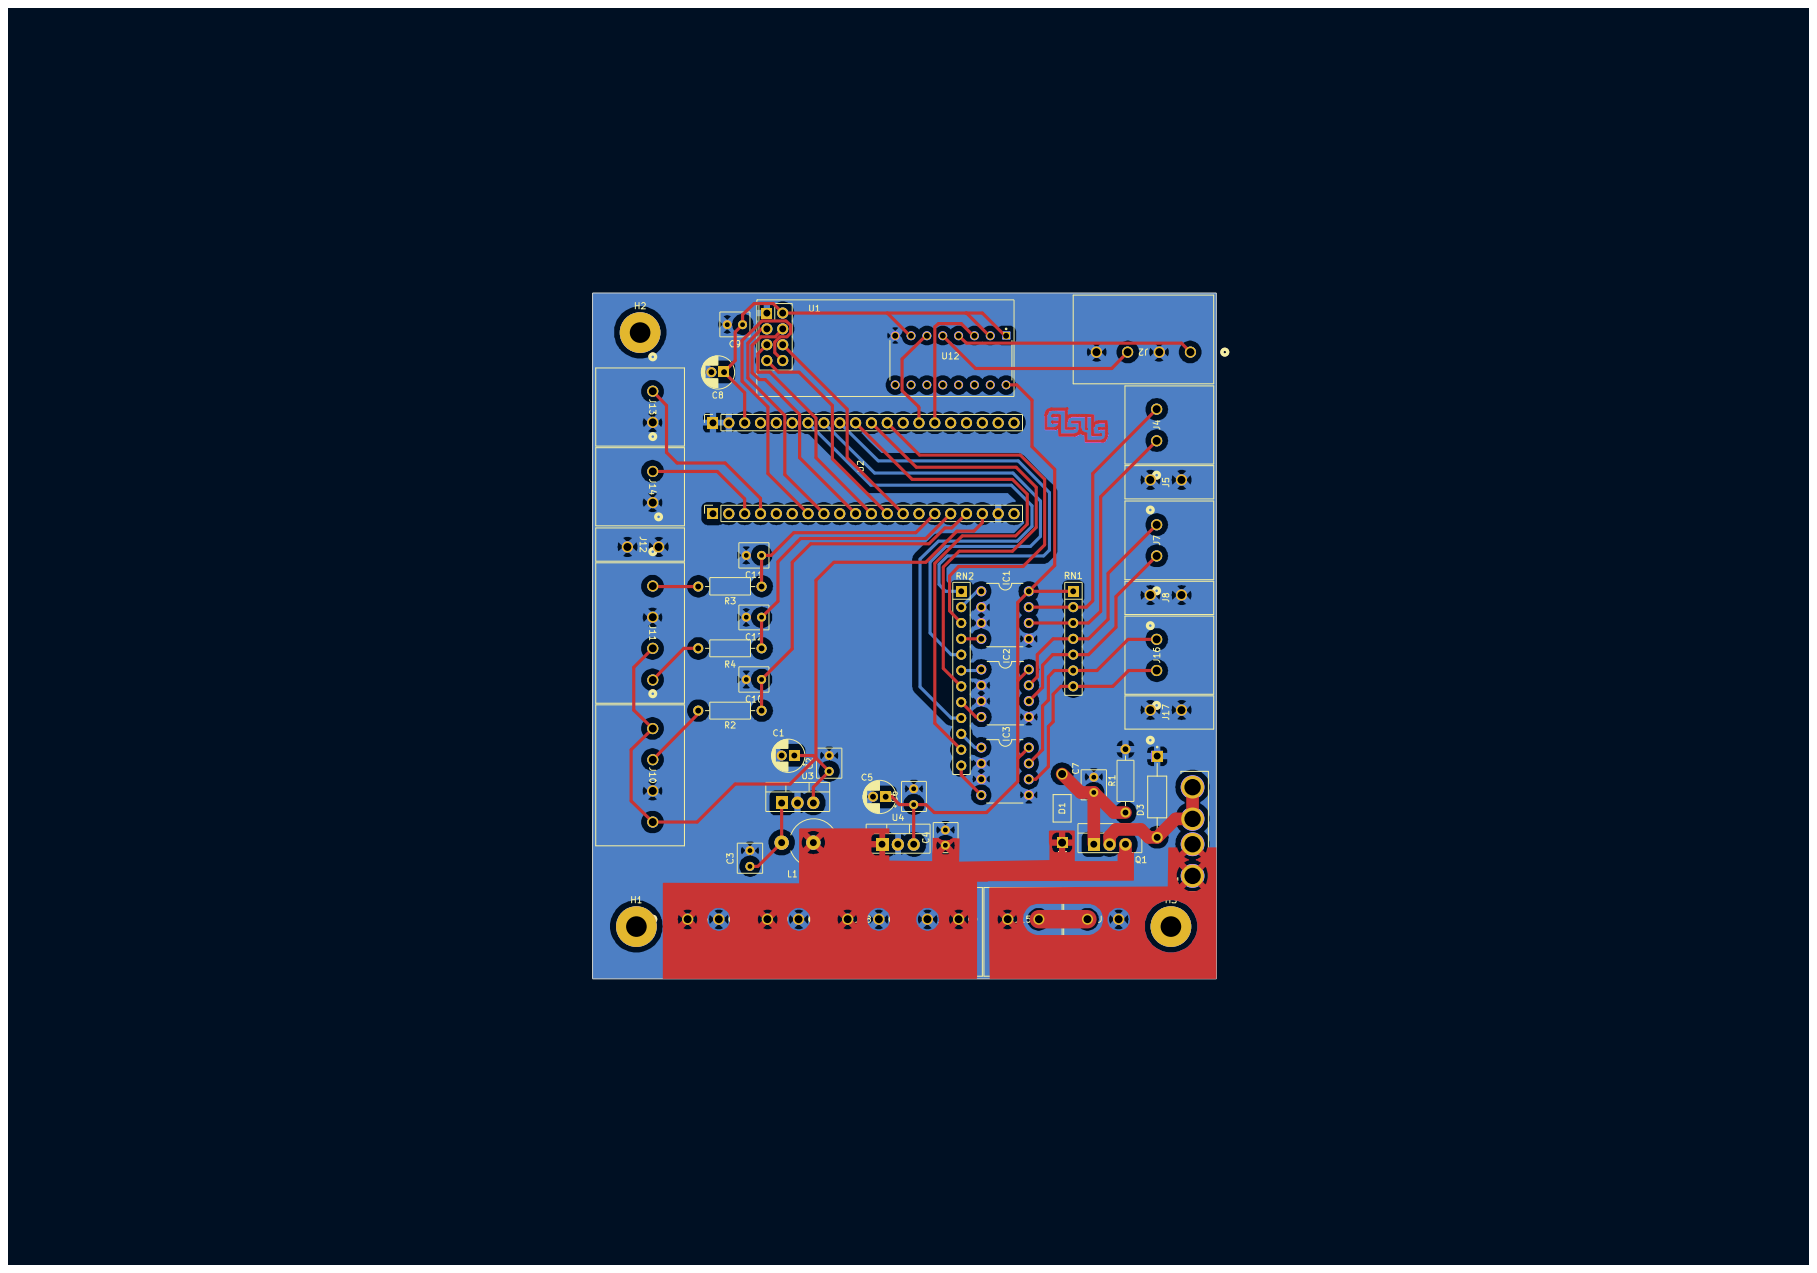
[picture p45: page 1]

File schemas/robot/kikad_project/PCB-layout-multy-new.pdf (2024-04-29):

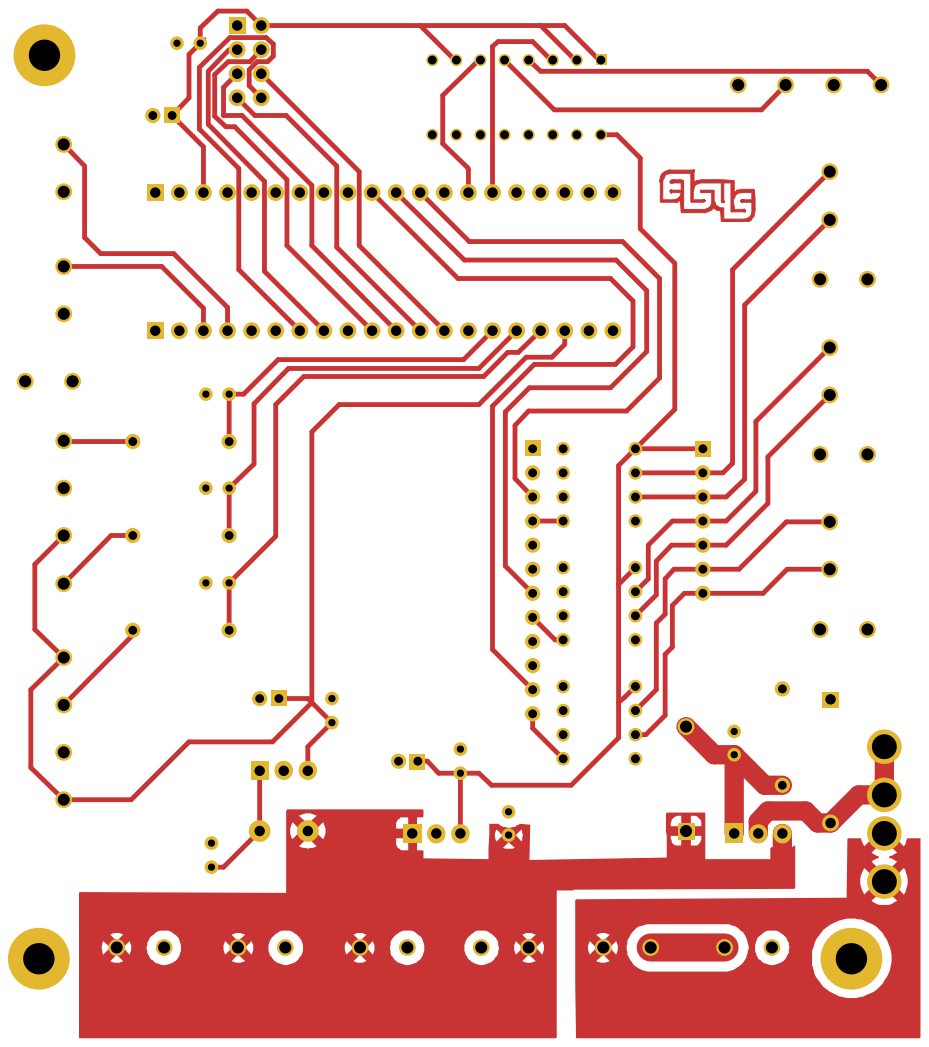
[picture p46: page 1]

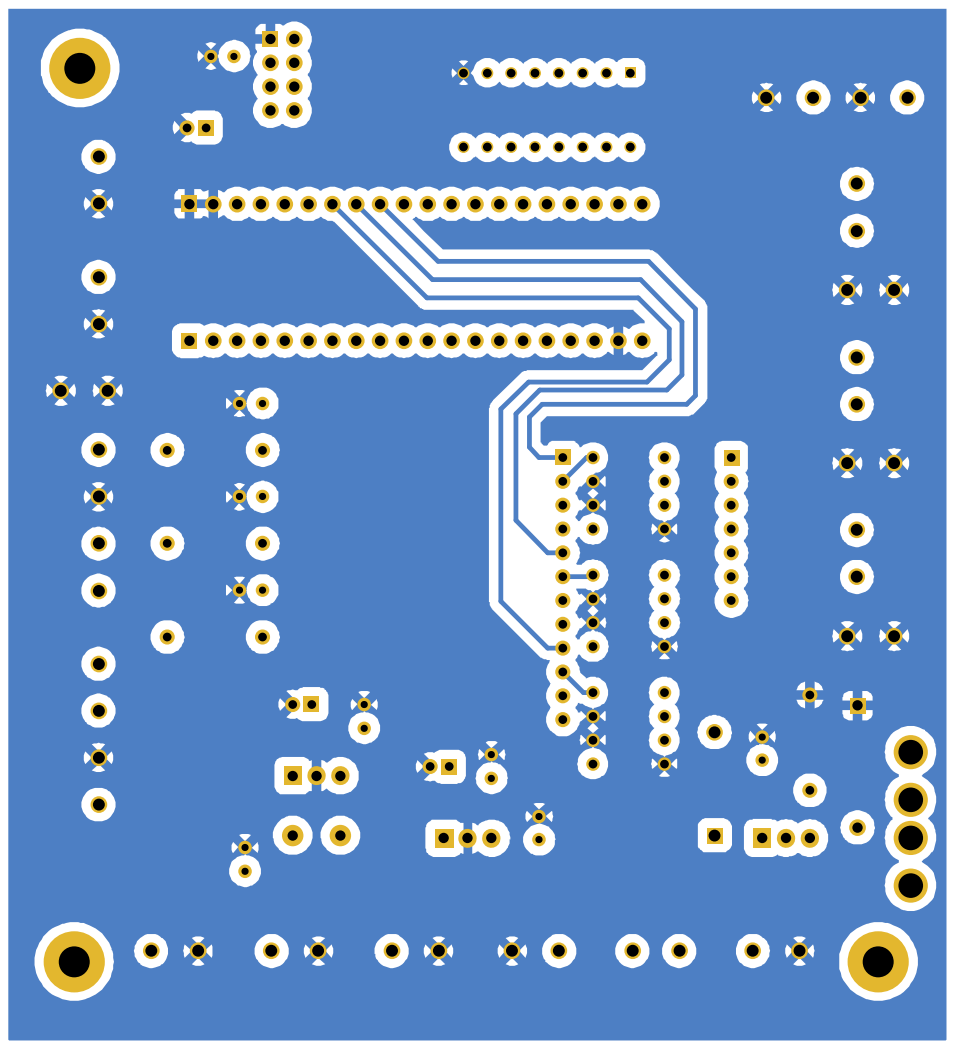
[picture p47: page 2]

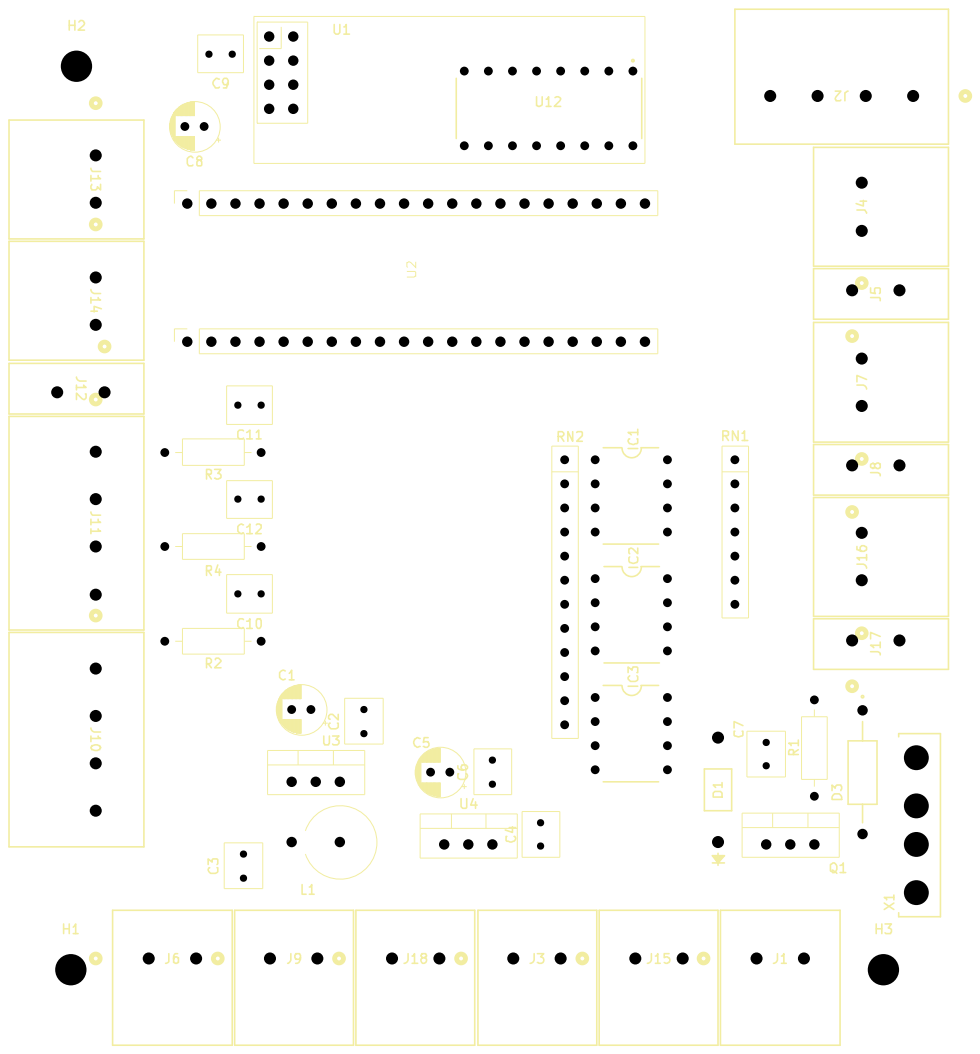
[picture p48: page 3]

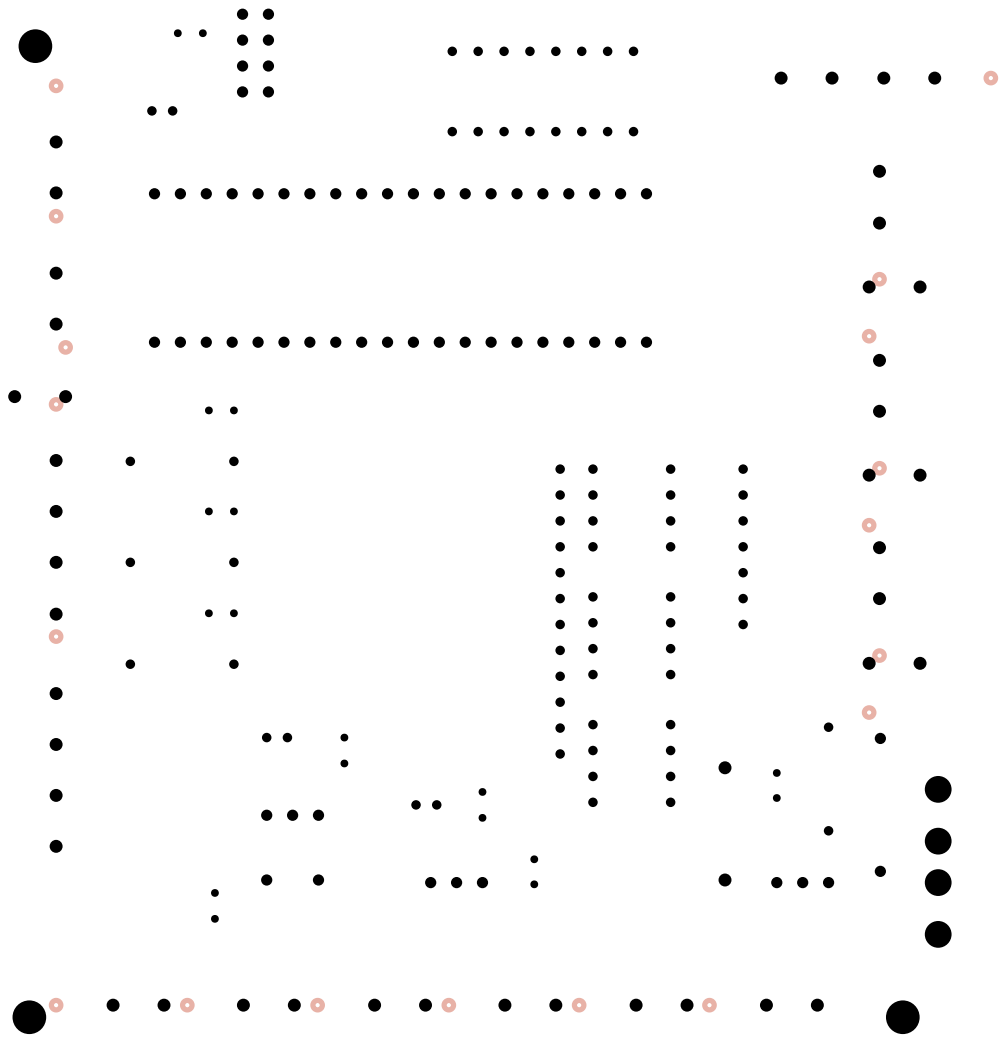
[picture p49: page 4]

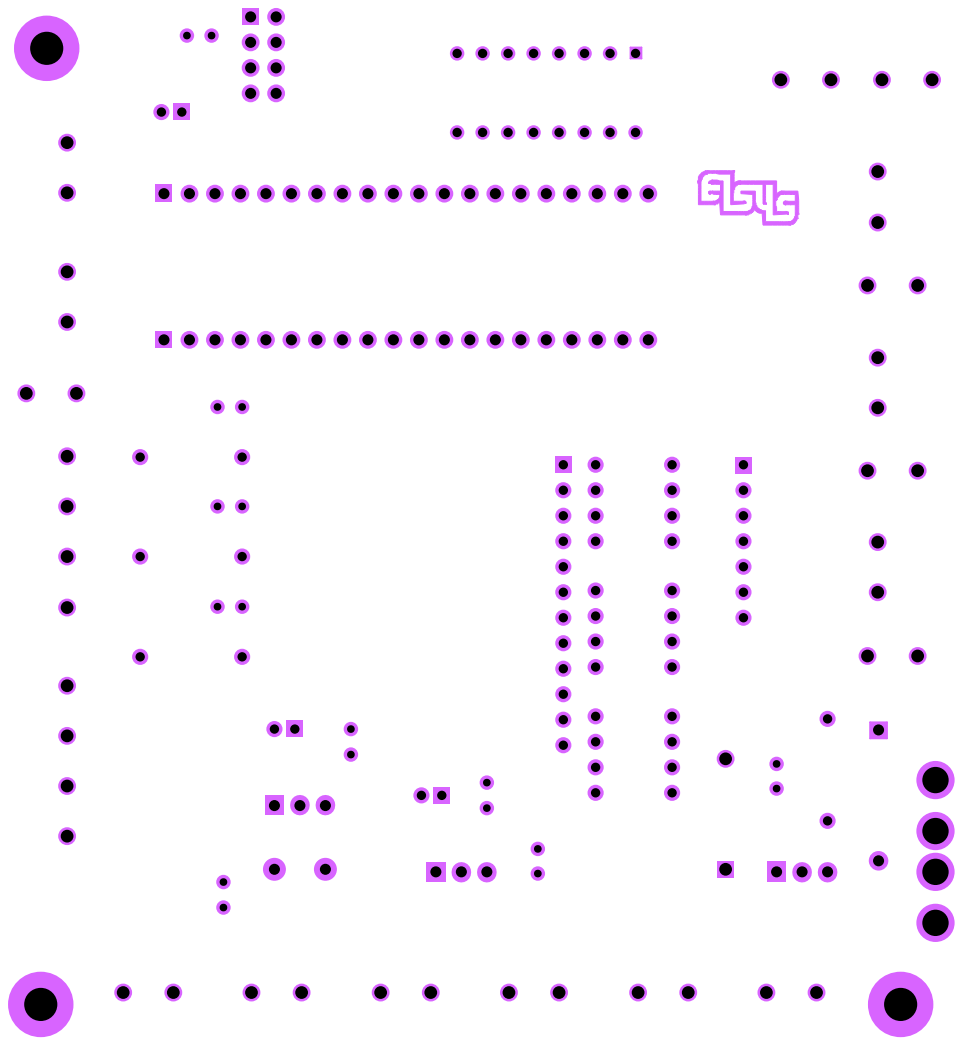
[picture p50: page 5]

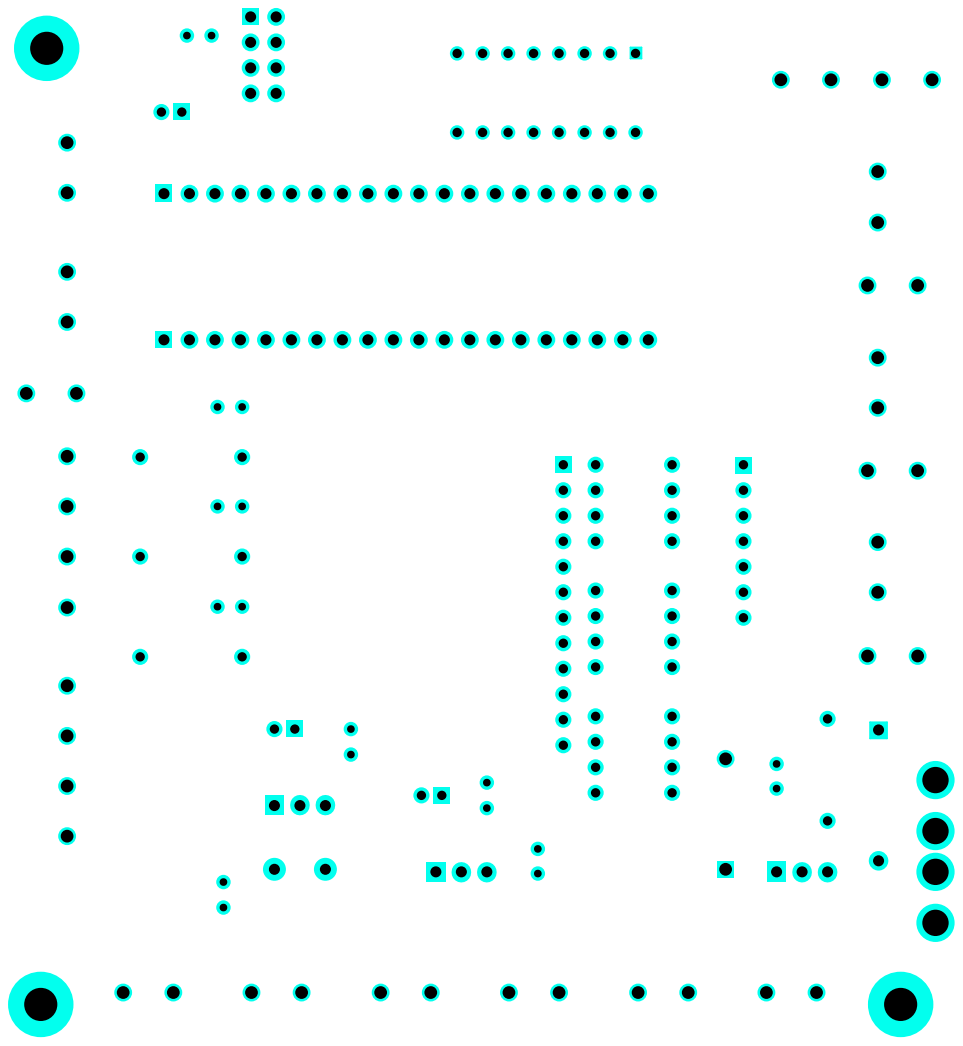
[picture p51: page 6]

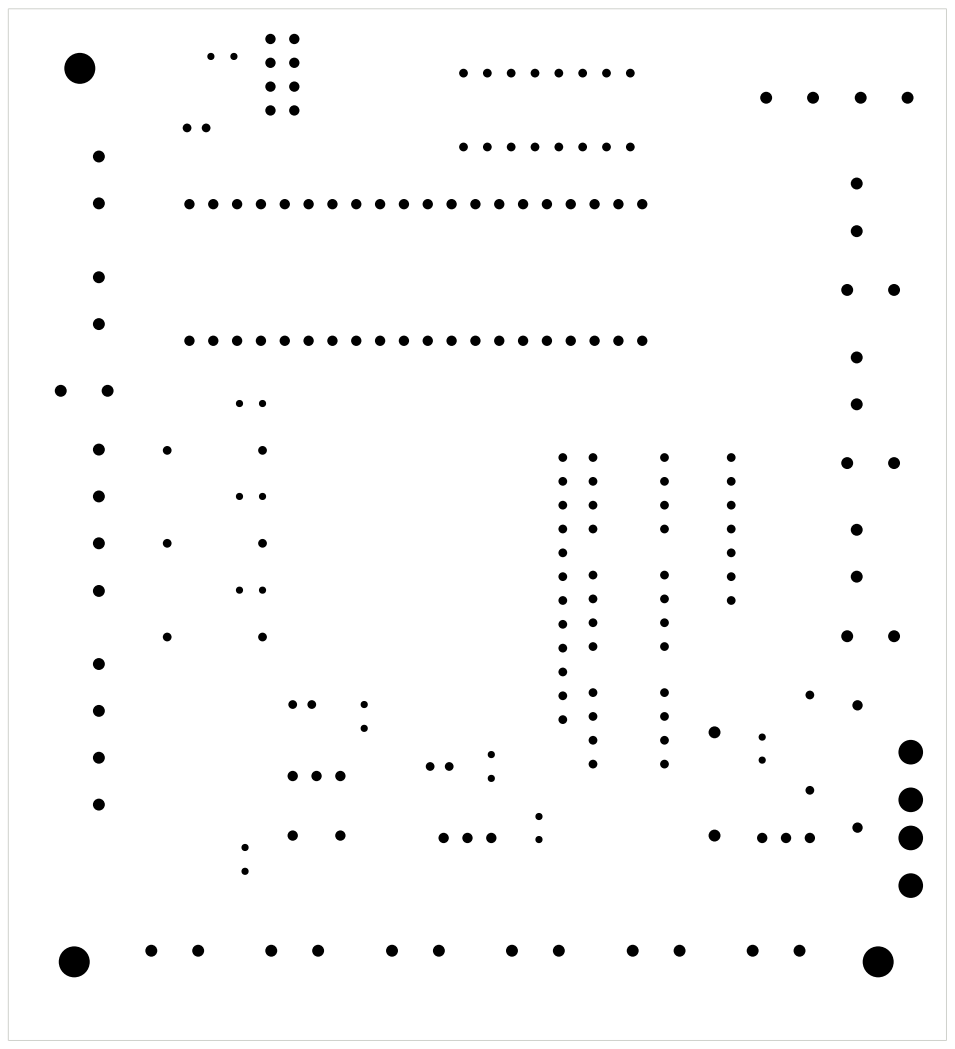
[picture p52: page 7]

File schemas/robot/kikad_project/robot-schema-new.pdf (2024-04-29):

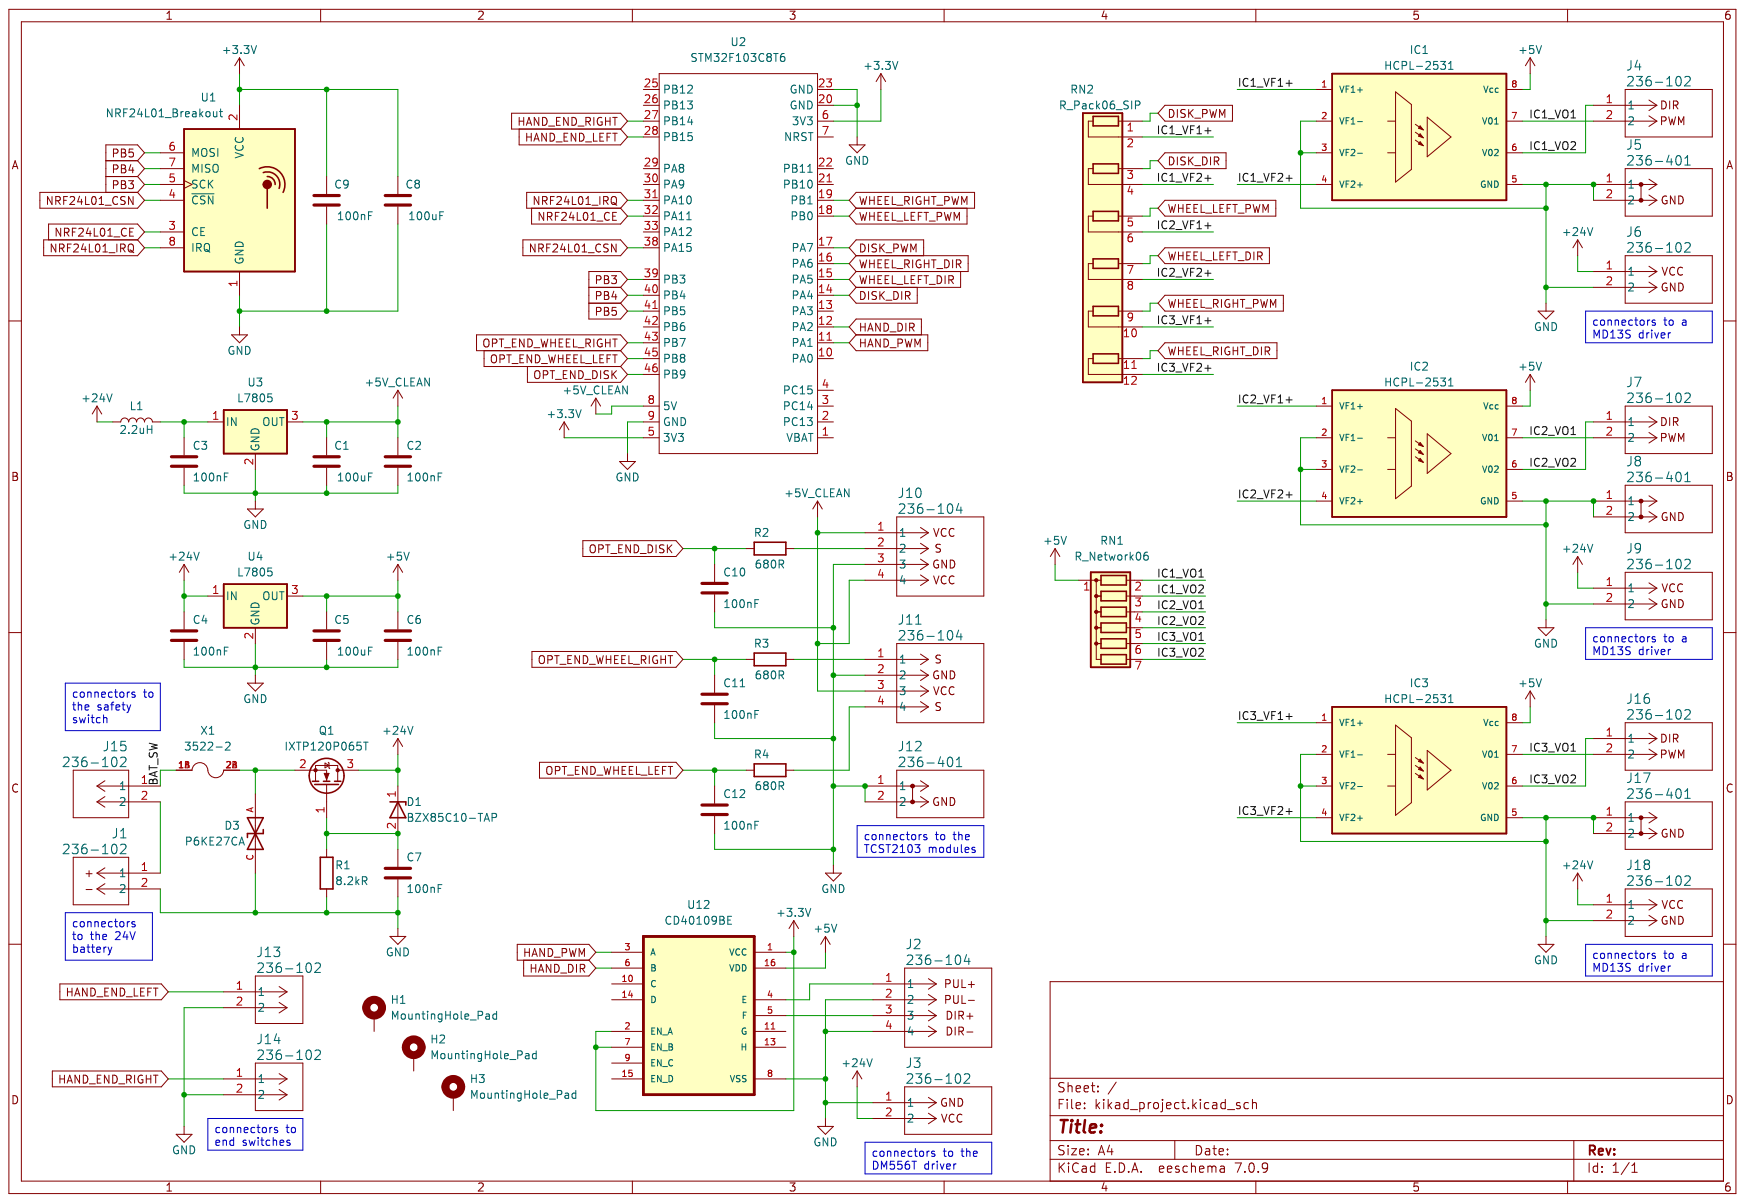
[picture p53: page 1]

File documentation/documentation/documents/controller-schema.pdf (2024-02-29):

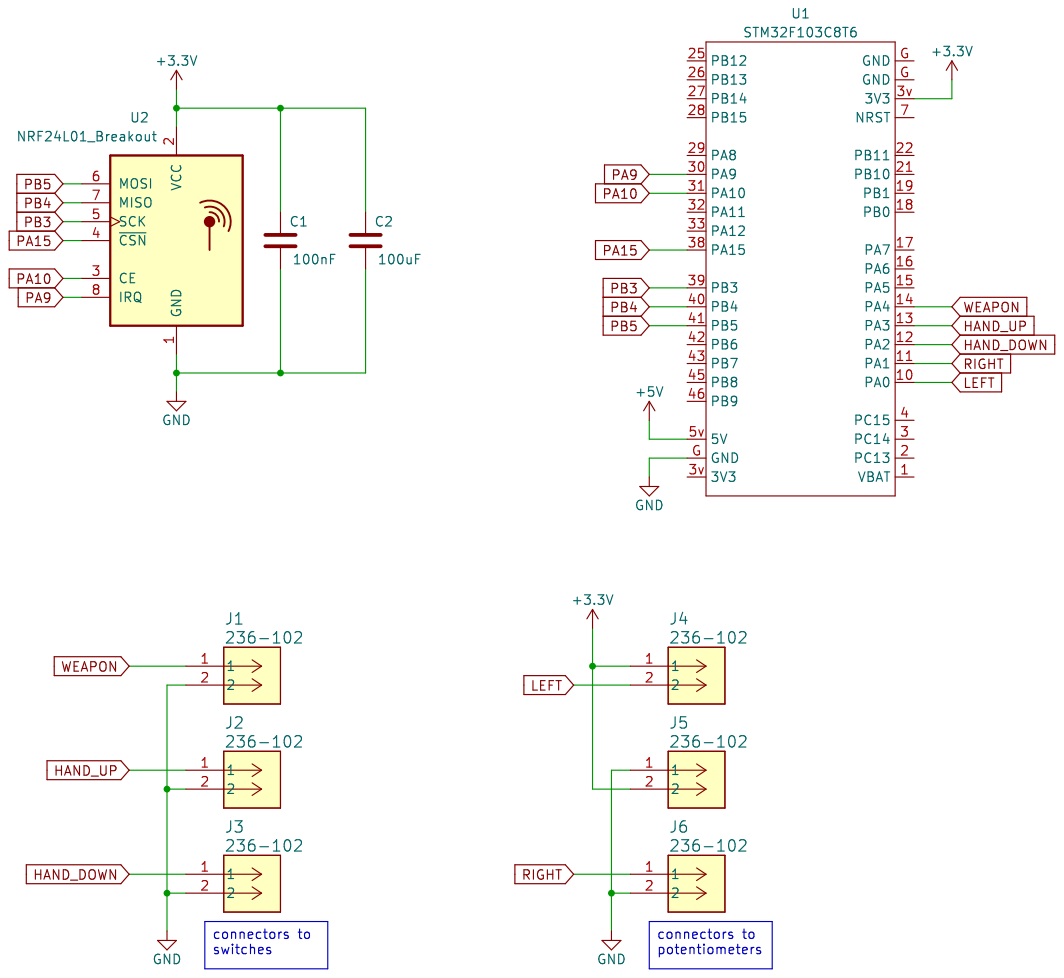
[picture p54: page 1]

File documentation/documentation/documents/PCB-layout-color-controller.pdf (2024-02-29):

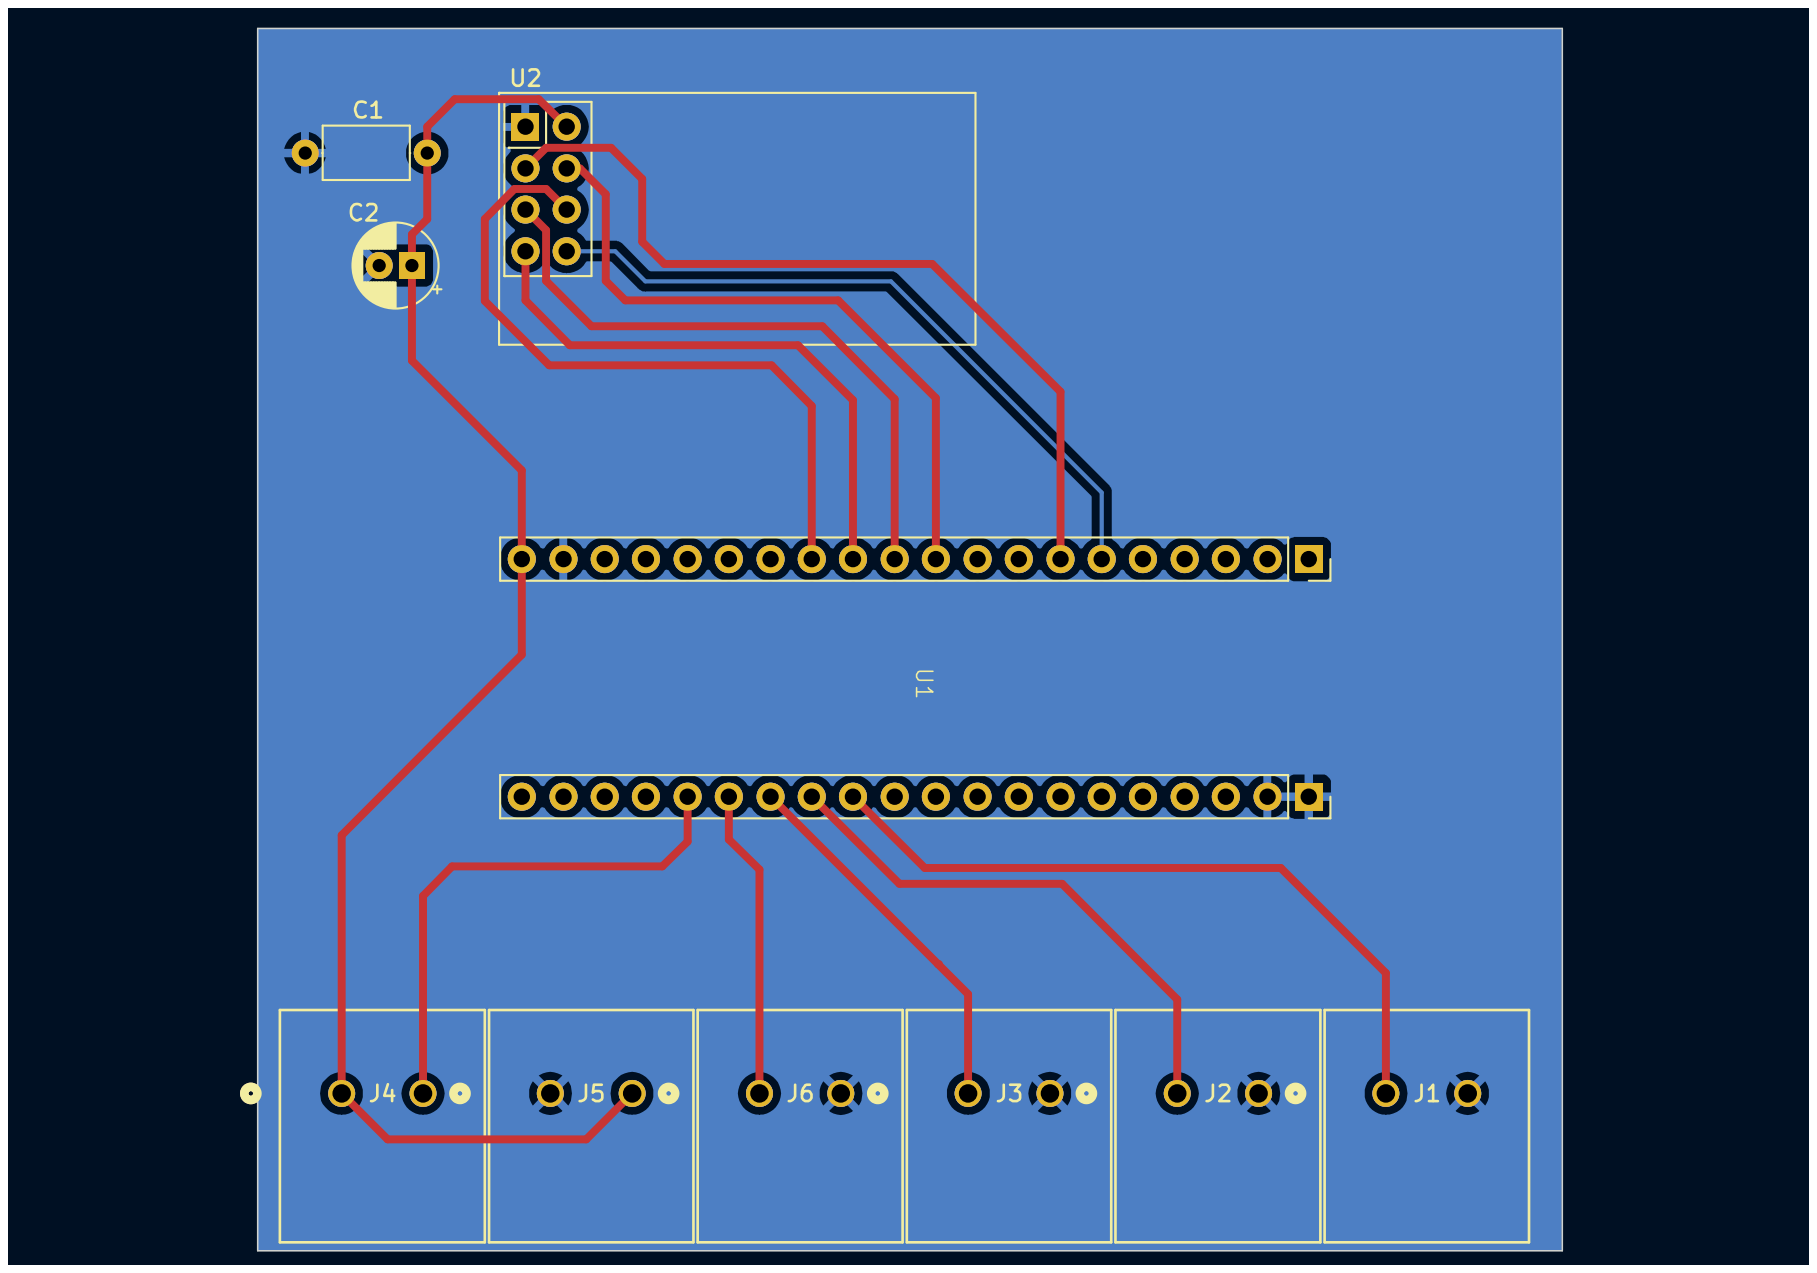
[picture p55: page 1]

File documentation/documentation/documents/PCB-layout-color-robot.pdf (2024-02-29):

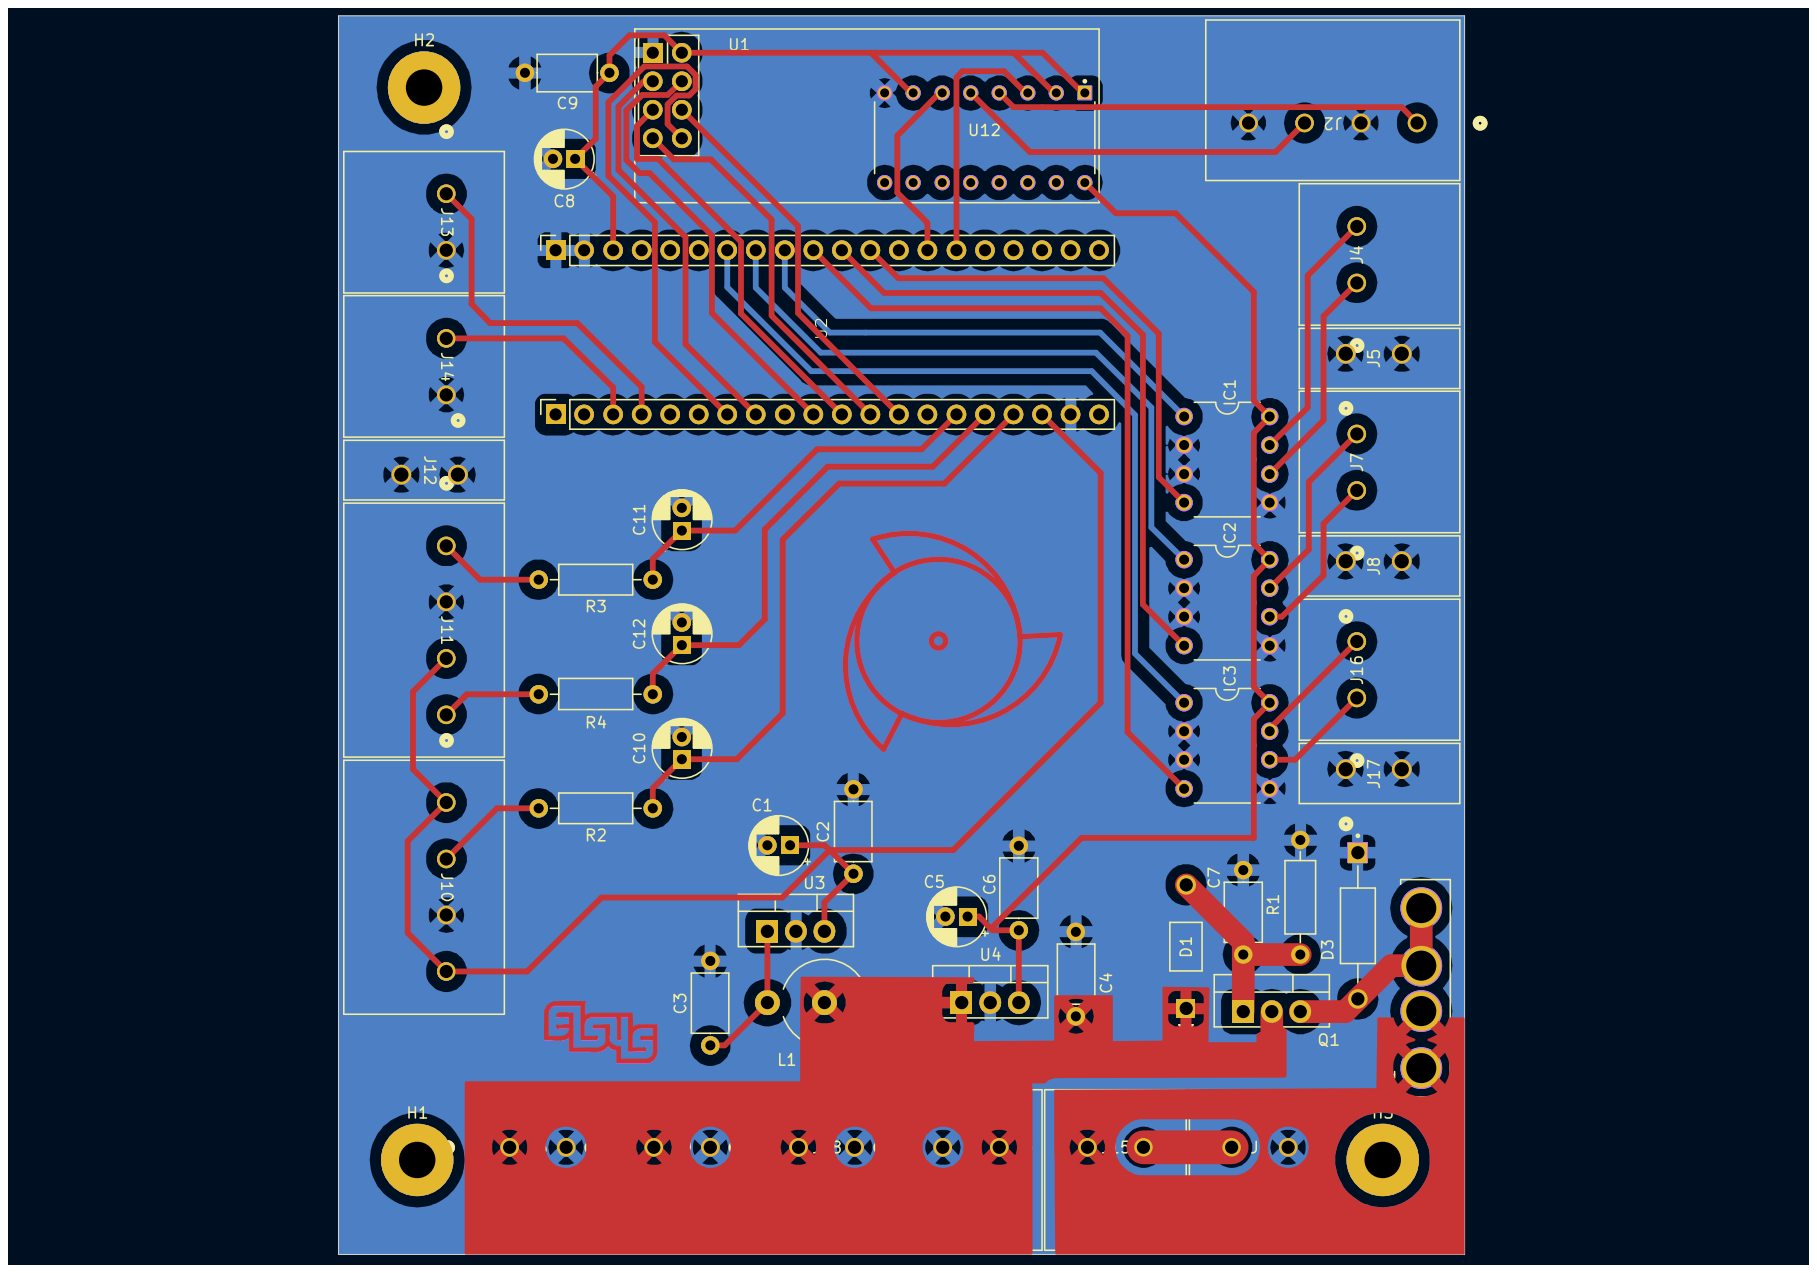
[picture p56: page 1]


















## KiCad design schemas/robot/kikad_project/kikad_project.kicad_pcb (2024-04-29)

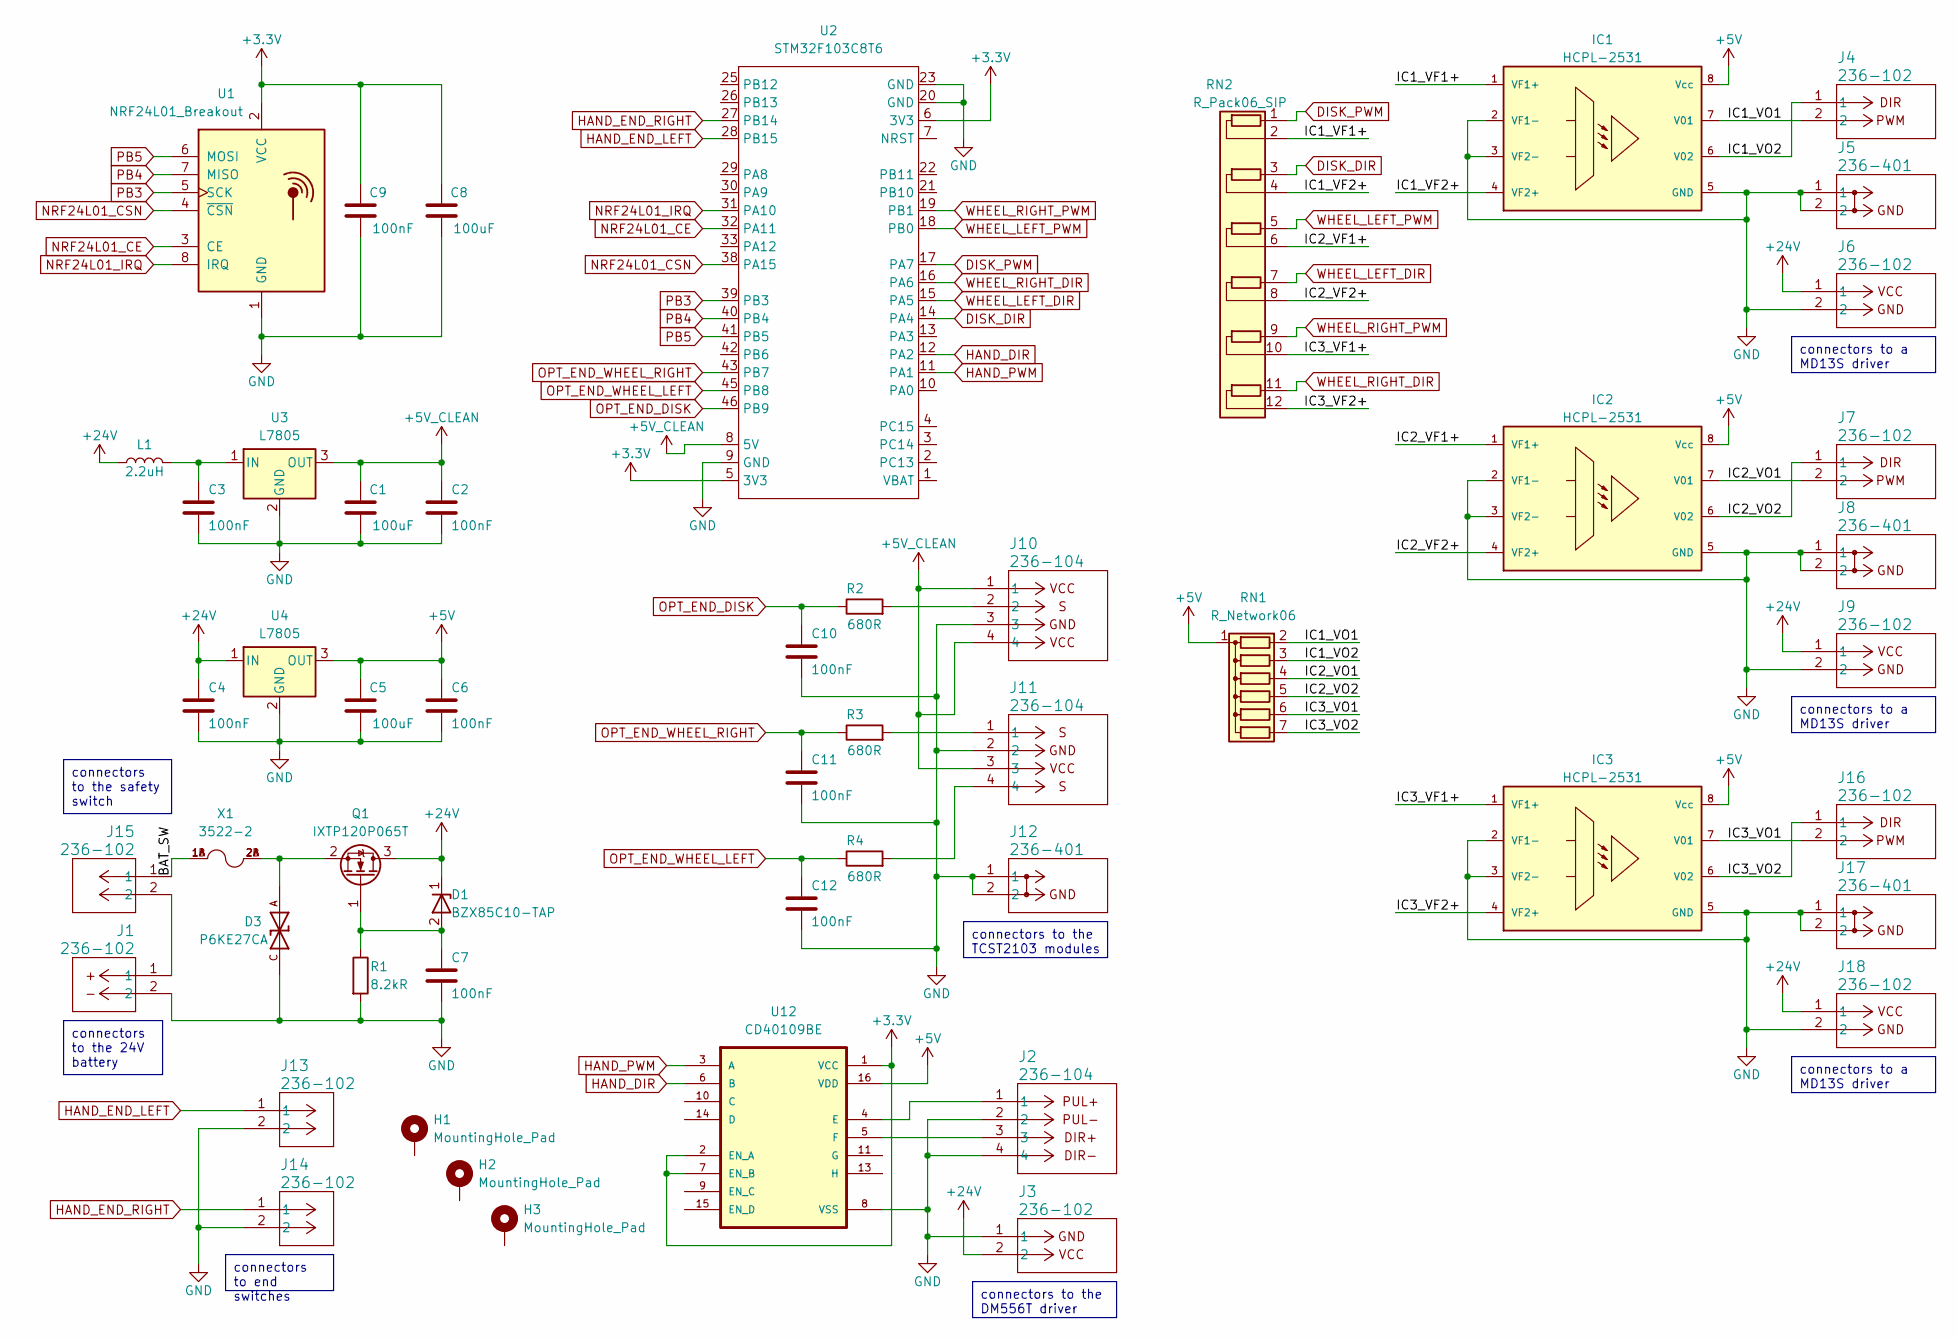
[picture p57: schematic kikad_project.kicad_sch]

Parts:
C1, C5, C8: 100uF; CP_Radial_D5.0mm_P2.00mm
C2, C3, C4, C6, C7, C9, C10, C11, C12: 100nF; C_Rect_L4.6mm_W3.8mm_P2.50mm_MKS02_FKP02
D1: BZX85C10-TAP; DO-41_VIS
D3: P6KE27CA; DIOAD1300W80L670D310; PARTREV K2105
H1, H2, H3: MountingHole_Pad; MountingHole_3.2mm_M3_Pad
IC1, IC2, IC3: HCPL-2531; DIL08; MPN HCPL-2531A-000E
J1, J3, J4, J6, J7, J9, J13, J14, J15, J16, J18: 236-102; CONN_236-102_WAG
J2, J10, J11: 236-104; CONN_236-104_WAG
J5, J8, J12, J17: 236-401; 236-744_WAG
L1: 2.2uH; L_Axial_L16.0mm_D7.5mm_P5.08mm_Vertical_Fastron_XHBCC
Q1: IXTP120P065T; TO-220-3_Vertical
R1: 8.2kR; R_Axial_DIN0207_L6.3mm_D2.5mm_P10.16mm_Horizontal
R2, R3, R4: 680R; R_Axial_DIN0207_L6.3mm_D2.5mm_P10.16mm_Horizontal
RN1: R_Network06; R_Array_SIP7
RN2: R_Pack06_SIP; R_Array_SIP12
U1: NRF24L01_Breakout; nRF24L01_Breakout
U2: STM32F103C8T6; STM32F103C8T6_pinout
U3, U4: L7805; TO-220-3_Vertical
U12: CD40109BE; DIP794W45P254L1969H508Q16; DigiKey_Part_Number 2156-CD40109BE-ND
X1: 3522-2; FUSE_3522-2; PARTREV J

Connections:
+3.3V: C8.1, C9.1, U1.2 (VCC), U2.5 (3V3), U2.6 (3V3), U12.1 (VCC), U12.2 (EN_A), U12.7 (EN_B)
+5V: C5.1, C6.1, IC1.8 (Vcc), IC2.8 (Vcc), IC3.8 (Vcc), RN1.1 (common), U4.3 (OUT), U12.16 (VDD)
+24V: C4.1, D1.1, J3.2, J6.1, J9.1, J18.1, L1.1, Q1.3 (D), U4.1 (IN)
/BAT_SW: J15.1, X1.1A, X1.1B
/IC1_VF1+: IC1.1 (VF1+), RN2.2 (R1.2)
/IC1_VF2+: IC1.4 (VF2+), RN2.4 (R2.2)
/IC1_VO1: IC1.7 (V01), J4.2, RN1.2 (R1)
/IC1_VO2: IC1.6 (V02), J4.1, RN1.3 (R2)
/IC2_VF1+: IC2.1 (VF1+), RN2.6 (R3.2)
/IC2_VF2+: IC2.4 (VF2+), RN2.8 (R4.2)
/IC2_VO1: IC2.7 (V01), J7.2, RN1.4 (R3)
/IC2_VO2: IC2.6 (V02), J7.1, RN1.5 (R4)
/IC3_VF1+: IC3.1 (VF1+), RN2.10 (R5.2)
/IC3_VF2+: IC3.4 (VF2+), RN2.12 (R6.2)
/IC3_VO1: IC3.7 (V01), J16.2, RN1.6 (R5)
/IC3_VO2: IC3.6 (V02), J16.1, RN1.7 (R6)
DISK_DIR: RN2.3 (R2.1), U2.14 (PA4)
DISK_PWM: RN2.1 (R1.1), U2.17 (PA7)
GND: C1.2, C2.2, C3.2, C4.2, C5.2, C6.2, C7.2, C8.2, C9.2, C10.2, C11.2, C12.2, D3.C, IC1.2 (VF1-), IC1.3 (VF2-), IC1.5 (GND), IC2.2 (VF1-), IC2.3 (VF2-), IC2.5 (GND), IC3.2 (VF1-), IC3.3 (VF2-), IC3.5 (GND), J1.2, J2.2, J2.4, J3.1, J5.1, J5.2, J6.2, J8.1, J8.2, J9.2, J10.3, J11.2, J12.1, J12.2, J13.2, J14.2, J17.1, J17.2, J18.2, R1.2, U1.1 (GND), U2.9 (GND), U2.20 (GND), U2.23 (GND), U3.2 (GND), U4.2 (GND), U12.8 (VSS)
HAND_DIR: U2.12 (PA2), U12.6 (B)
HAND_END_LEFT: J13.1, U2.28 (PB15)
HAND_END_RIGHT: J14.1, U2.27 (PB14)
HAND_PWM: U2.11 (PA1), U12.3 (A)
NRF24L01_CE: U1.3 (CE), U2.32 (PA11)
NRF24L01_CSN: U1.4 (~CSN), U2.38 (PA15)
NRF24L01_IRQ: U1.8 (IRQ), U2.31 (PA10)
unnamed: J1.1, J15.2
unnamed: J10.2, R2.2
unnamed: J11.1, R3.2
unnamed: J11.4, R4.2
unnamed: C7.1, D1.2, Q1.1 (G), R1.1
unnamed: D3.A, Q1.2 (S), X1.2A, X1.2B
unnamed: C3.1, L1.2, U3.1 (IN)
unnamed: J2.1, U12.4 (E)
unnamed: J2.3, U12.5 (F)
OPT_END_DISK: C10.1, R2.1, U2.46 (PB9)
OPT_END_WHEEL_LEFT: C12.1, R4.1, U2.45 (PB8)
OPT_END_WHEEL_RIGHT: C11.1, R3.1, U2.43 (PB7)
PB3: U1.5 (SCK), U2.39 (PB3)
PB4: U1.7 (MISO), U2.40 (PB4)
PB5: U1.6 (MOSI), U2.41 (PB5)
VCC: C1.1, C2.1, J10.1, J10.4, J11.3, U2.8 (5V), U3.3 (OUT)
WHEEL_LEFT_DIR: RN2.7 (R4.1), U2.15 (PA5)
WHEEL_LEFT_PWM: RN2.5 (R3.1), U2.18 (PB0)
WHEEL_RIGHT_DIR: RN2.11 (R6.1), U2.16 (PA6)
WHEEL_RIGHT_PWM: RN2.9 (R5.1), U2.19 (PB1)

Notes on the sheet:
connectors to the 24V battery
connectors to end switches
connectors to a MD13S driver
connectors to the DM556T driver
connectors to the safety switch
connectors to the TCST2103 modules

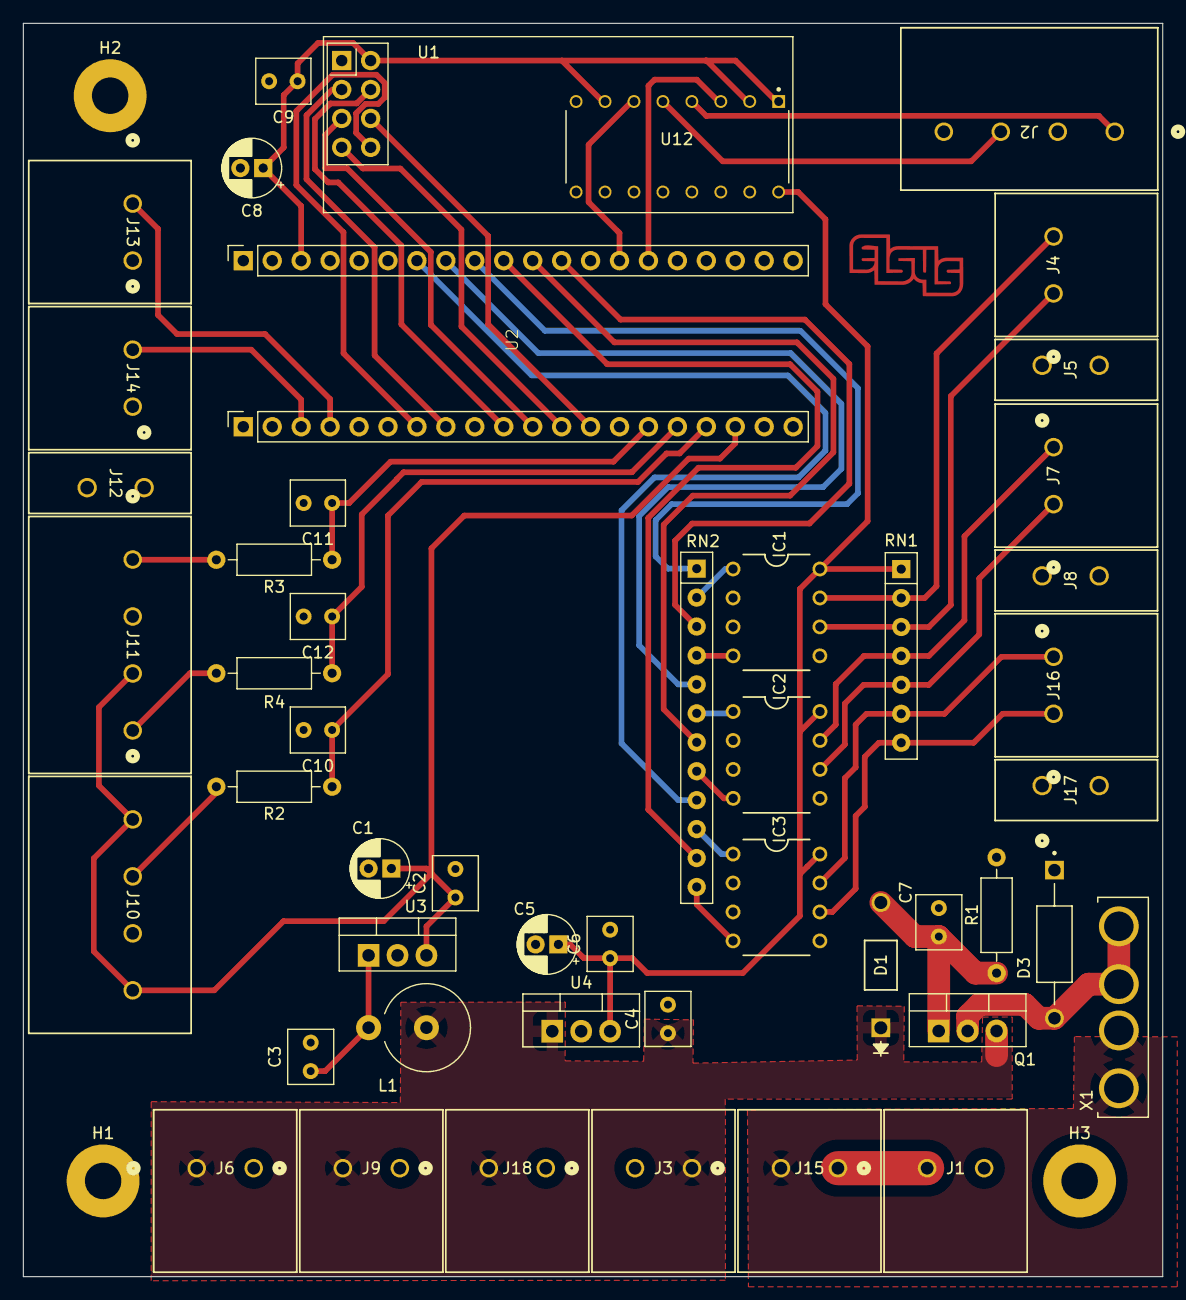
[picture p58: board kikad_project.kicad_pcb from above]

Board: 2 copper layers, 100.0 x 110.0 mm, 52 parts (0 on the bottom side), 46 nets.

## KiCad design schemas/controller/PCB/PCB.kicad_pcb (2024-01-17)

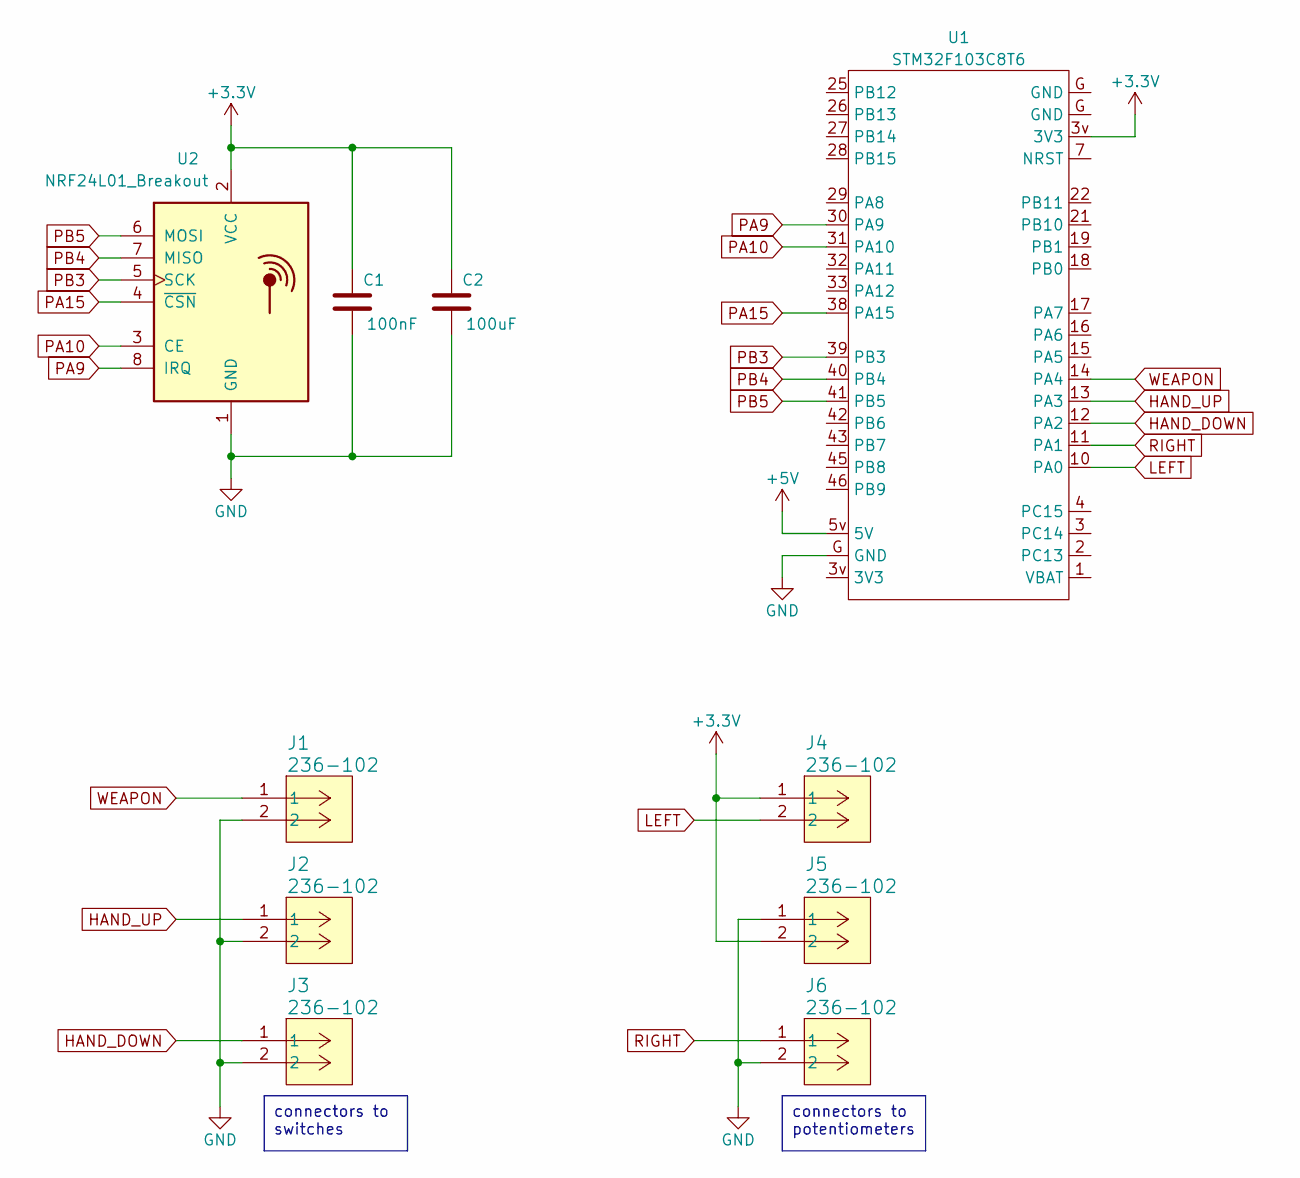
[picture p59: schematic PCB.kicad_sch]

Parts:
C1: 100nF; C_Axial_L5.1mm_D3.1mm_P7.50mm_Horizontal
C2: 100uF; CP_Radial_D5.0mm_P2.00mm
J1, J2, J3, J4, J5, J6: 236-102; CONN_236-102_WAG
U1: STM32F103C8T6; STM32F103C8T6_pinout
U2: NRF24L01_Breakout; nRF24L01_Breakout

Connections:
+3.3V: C1.1, C2.1, J4.1, J5.2, U1.3v (3V3), U2.2 (VCC)
+5V: U1.5v (5V)
GND: C1.2, C2.2, J1.2, J2.2, J3.2, J5.1, J6.2, U1.G (GND), U2.1 (GND)
HAND_DOWN: J3.1, U1.12 (PA2)
HAND_UP: J2.1, U1.13 (PA3)
LEFT: J4.2, U1.10 (PA0)
PA9: U1.30 (PA9), U2.8 (IRQ)
PA10: U1.31 (PA10), U2.3 (CE)
PA15: U1.38 (PA15), U2.4 (~CSN)
PB3: U1.39 (PB3), U2.5 (SCK)
PB4: U1.40 (PB4), U2.7 (MISO)
PB5: U1.41 (PB5), U2.6 (MOSI)
RIGHT: J6.1, U1.11 (PA1)
WEAPON: J1.1, U1.14 (PA4)

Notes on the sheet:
connectors to switches
connectors to potentiometers

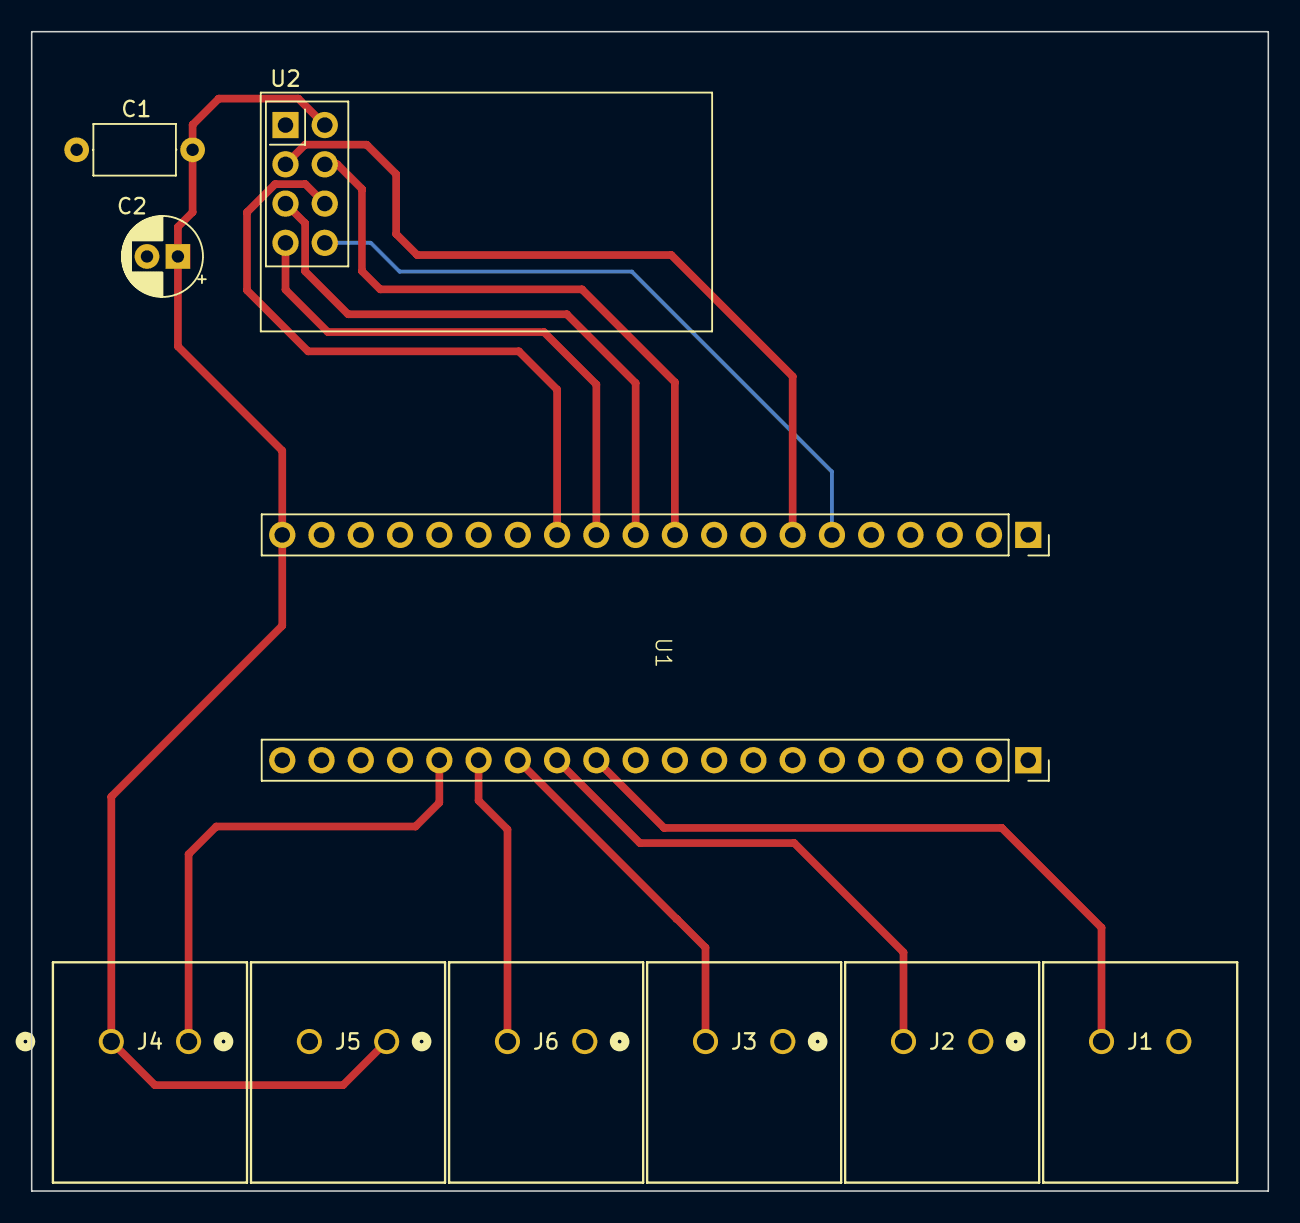
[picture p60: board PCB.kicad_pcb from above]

Board: 2 copper layers, 80.0 x 75.0 mm, 10 parts (0 on the bottom side), 13 nets.

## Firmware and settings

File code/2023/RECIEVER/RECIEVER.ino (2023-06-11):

/*
 * See documentation at https://nRF24.github.io/RF24
 * See License information at root directory of this library
 * Author: Brendan Doherty (2bndy5)

 RADIO NUMBER 1
 ROLE RX (FALSE)
 */
#include <SPI.h>
#include "printf.h"
#include "RF24.h"

RF24 radio(7, 8);  // using pin 7 for the CE pin, and pin 8 for the CSN pin
uint8_t address[][6] = { "1Node", "2Node" };

const int pwmWeaponPin = 6;
const int dirLeftPin = 2;
const int pwmLeftPin = 3;
const int dirRightPin = 4;
const int pwmRightPin = 5;                                           //
const int stepPin = 9;
const int dirPin = 10;

int handPosition = 0;    // 'real' hand position
int maxMotorSpeed = 255;  // 77 for arduino, 19000 for blue pill

struct Controls {
  int hand;     // value for hand position  || from 0 to 100
  bool weapon;  // value for weapon         || true/false
  int left;     // value for left wheel     || from -77 to +77       || from -19 000 to +19 000
  int right;    // value for right wheel    || from -77 to +77       || from -19 000 to +19 000
};
Controls payload;

void setup() {
  //Serial.begin(9600);

  pinMode(pwmWeaponPin, OUTPUT);                                     //
  pinMode(dirLeftPin, OUTPUT);
  pinMode(pwmLeftPin, OUTPUT);
  pinMode(dirRightPin, OUTPUT);
  pinMode(pwmRightPin, OUTPUT);
  pinMode(stepPin, OUTPUT);
  pinMode(dirPin, OUTPUT);

  // initialize the transceiver on the SPI bus
  if (!radio.begin()) {                                              //
    //Serial.println(F("radio hardware is not responding!!"));
    while (1) {}                                                     // hold in infinite loop
  }

  radio.setPALevel(RF24_PA_LOW);                                     // RF24_PA_MAX is default.

  radio.setPayloadSize(sizeof(payload));                             // float datatype occupies 4 bytes
  
  radio.openWritingPipe(address[1]);                                 // always uses pipe 0
  radio.openReadingPipe(1, address[0]);                              // using pipe 1
  radio.startListening();                                            // put radio in RX mode
} // setup
  
void loop() {
  uint8_t pipe;
  
  // check for recieved commands
  if (radio.available(&pipe)) {                                      // get the pipe number that recieved it
    uint8_t bytes = radio.getPayloadSize();                          // get the size of the payload
    radio.read(&payload, bytes);                                     // fetch payload from FIFO
    //Serial.print(F("Received "));
  }

  // move the hand in the chosen direction                           //
    if(payload.hand > handPosition) {
      digitalWrite(dirPin, HIGH);
      digitalWrite(stepPin, HIGH);
      delayMicroseconds(500);
      digitalWrite(stepPin, LOW);
      delayMicroseconds(500);
      handPosition++;
    } else if (payload.hand < handPosition) {
      digitalWrite(dirPin, LOW);
      digitalWrite(stepPin, HIGH);
      delayMicroseconds(500);
      digitalWrite(stepPin, LOW);
      delayMicroseconds(500);
      handPosition--;
    } else {
      digitalWrite(stepPin, LOW);
    }

    // moving the cutting disk                                       //
    if(payload.weapon == true) {
      analogWrite(pwmWeaponPin, maxMotorSpeed);
    } else {
      analogWrite(pwmWeaponPin, 0);
    } 
    
    // moving the left wheel                                         //
    if(payload.left > 0) {
      digitalWrite(dirLeftPin, HIGH);
      analogWrite(pwmLeftPin, payload.left);
    } else {
      payload.left *= -1;
      digitalWrite(dirLeftPin, LOW);
      analogWrite(pwmLeftPin, payload.left);
    }

    //moving the right wheel                                         //
    if(payload.right > 0) {
      digitalWrite(dirRightPin, HIGH);
      analogWrite(pwmRightPin, payload.right);
    } else {
      payload.right *= -1;
      digitalWrite(dirRightPin, LOW);
      analogWrite(pwmRightPin, payload.right);
    }
} // loop

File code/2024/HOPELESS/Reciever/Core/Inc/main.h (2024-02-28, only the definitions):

#define HAND_PWM_Pin GPIO_PIN_1
#define HAND_PWM_GPIO_Port GPIOA
#define HAND_DIR_Pin GPIO_PIN_2
#define HAND_DIR_GPIO_Port GPIOA
#define DISK_DIR_Pin GPIO_PIN_4
#define DISK_DIR_GPIO_Port GPIOA
#define WHEEL_LEFT_DIR_Pin GPIO_PIN_5
#define WHEEL_LEFT_DIR_GPIO_Port GPIOA
#define WHEEL_RIGHT_DIR_Pin GPIO_PIN_6
#define WHEEL_RIGHT_DIR_GPIO_Port GPIOA
#define DISK_PWM_Pin GPIO_PIN_7
#define DISK_PWM_GPIO_Port GPIOA
#define WHEEL_LEFT_PWM_Pin GPIO_PIN_0
#define WHEEL_LEFT_PWM_GPIO_Port GPIOB
#define WHEEL_RIGHT_PWM_Pin GPIO_PIN_1
#define WHEEL_RIGHT_PWM_GPIO_Port GPIOB
#define HAND_END_RIGHT_Pin GPIO_PIN_14
#define HAND_END_RIGHT_GPIO_Port GPIOB
#define HAND_END_RIGHT_EXTI_IRQn EXTI15_10_IRQn
#define HAND_END_LEFT_Pin GPIO_PIN_15
#define HAND_END_LEFT_GPIO_Port GPIOB
#define HAND_END_LEFT_EXTI_IRQn EXTI15_10_IRQn
#define NRF24L01_IRQ_Pin GPIO_PIN_10
#define NRF24L01_IRQ_GPIO_Port GPIOA
#define NRF24L01_IRQ_EXTI_IRQn EXTI15_10_IRQn
#define NRF24L01_CE_Pin GPIO_PIN_11
#define NRF24L01_CE_GPIO_Port GPIOA
#define NRF24L01_CSN_Pin GPIO_PIN_15
#define NRF24L01_CSN_GPIO_Port GPIOA
#define OPT_END_WHEEL_RIGHT_Pin GPIO_PIN_7
#define OPT_END_WHEEL_RIGHT_GPIO_Port GPIOB
#define OPT_END_WHEEL_RIGHT_EXTI_IRQn EXTI9_5_IRQn
#define OPT_END_WHEEL_LEFT_Pin GPIO_PIN_8
#define OPT_END_WHEEL_LEFT_GPIO_Port GPIOB
#define OPT_END_WHEEL_LEFT_EXTI_IRQn EXTI9_5_IRQn
#define OPT_END_DISK_Pin GPIO_PIN_9
#define OPT_END_DISK_GPIO_Port GPIOB
#define OPT_END_DISK_EXTI_IRQn EXTI9_5_IRQn

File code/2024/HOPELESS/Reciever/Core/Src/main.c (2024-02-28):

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
/* Includes ------------------------------------------------------------------*/
#include "main.h"
#include "spi.h"
#include "tim.h"
#include "gpio.h"

/* USER CODE BEGIN Includes */

#include "NRF24L01.h"

/* USER CODE END Includes */


void SystemClock_Config(void);
/* USER CODE BEGIN 0 */

const uint8_t rx_address[] = {0xEE, 0xDD, 0xCC, 0xBB, 0xAA};

Payload payload = {0, 0, 0, 0};

// 0 = disk;	1 = right;	2 = left
volatile uint8_t cycles[3] = {0, 0, 0};
volatile uint8_t enable[3] = {1, 1, 1};
// 0 = right(down)	1 = left(up)
volatile uint8_t hand_enable[2] = {1, 1};
volatile uint8_t hand_counter = 0;
/* USER CODE END 0 */

/**
  * @brief  The application entry point.
  * @retval int
  */
int main(void)
{
  /* MCU Configuration--------------------------------------------------------*/

  /* Reset of all peripherals, Initializes the Flash interface and the Systick. */
  HAL_Init();

  /* Configure the system clock */
  SystemClock_Config();

  /* Initialize all configured peripherals */
  MX_GPIO_Init();
  MX_SPI1_Init();
  MX_TIM3_Init();
  MX_TIM2_Init();
  MX_TIM4_Init();
  /* USER CODE BEGIN 2 */

  NRF24_init();
  NRF24_RX_mode(rx_address, 120);

  HAL_TIM_PWM_Start(&htim3, TIM_CHANNEL_2);
  HAL_TIM_PWM_Start(&htim3, TIM_CHANNEL_3);
  HAL_TIM_PWM_Start(&htim3, TIM_CHANNEL_4);

  HAL_TIM_Base_Start_IT(&htim4);
  HAL_TIM_Base_Start_IT(&htim2);

  /* USER CODE END 2 */

  /* Infinite loop */
  /* USER CODE BEGIN WHILE */
  while (1)
  {
    // TODO: replace the pooling
    if (0 == is_data_received(1))
    {
      if (0 == NRF24_receive(&payload))
      {
	  unload_payload();
      }
    }
    /* USER CODE END WHILE */

    /* USER CODE BEGIN 3 */
  }
  /* USER CODE END 3 */
}

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
/* USER CODE BEGIN 4 */
/**
  * @brief EXTI line detection callbacks
  * @param GPIO_Pin: Specifies the pins connected EXTI line
  * @retval None
  */
void HAL_GPIO_EXTI_Callback(uint16_t GPIO_Pin)
{
  /* TODO: sadly this interrupt still does not work as I want to
  if (GPIO_Pin == NRF24L01_IRQ_Pin)
  {
    // payload_recieved = 1;
  }
  */

  if (GPIO_Pin == OPT_END_DISK_Pin)
  {
    cycles[0]++;
  }
  if (GPIO_Pin == OPT_END_WHEEL_RIGHT_Pin)
  {
    cycles[1]++;
  }
  if (GPIO_Pin == OPT_END_WHEEL_LEFT_Pin)
  {
    cycles[2]++;
  }



  if (GPIO_Pin == HAND_END_RIGHT_Pin)
  {
    hand_enable[0] = !hand_enable[0];
  }
  if (GPIO_Pin == HAND_END_LEFT_Pin)
  {
    hand_enable[1] = !hand_enable[1];
  }
}

void HAL_TIM_PeriodElapsedCallback(TIM_HandleTypeDef* htim)
{
  if (&htim2 == htim)
  {
    if (2 * payload.hand_position != hand_counter)
    {
      hand_counter++;
      HAL_GPIO_TogglePin(HAND_PWM_GPIO_Port, HAND_PWM_Pin);
    }
    else
    {
      payload.hand_position = 0;
      hand_counter = 0;
    }
  }

  if (&htim4 == htim)
  {
    for (int i = 0; i < 3; i++)
    {
      if (enable[i] && 0 == cycles[i])
      {
	enable[i] = 0;
	cycles[i] = 0;
      }
      else if (!enable[i] && 4 > cycles[i])
      {
	cycles[i]++;
      }
      else
      {
	enable[i] = 1;
	cycles[i] = 0;
      }
    }
  }
}

void get_brushed_DIR(void)
{
  HAL_GPIO_WritePin(DISK_DIR_GPIO_Port, DISK_DIR_Pin, SET);

  if (payload.left_speed < 0)
  {
    payload.left_speed *= -1;
    HAL_GPIO_WritePin(WHEEL_LEFT_DIR_GPIO_Port, WHEEL_LEFT_DIR_Pin, RESET);
  }
  else
  {
    HAL_GPIO_WritePin(WHEEL_LEFT_DIR_GPIO_Port, WHEEL_LEFT_DIR_Pin, SET);
  }

  if (payload.right_speed < 0)
  {
    payload.right_speed *= -1;
    HAL_GPIO_WritePin(WHEEL_RIGHT_DIR_GPIO_Port, WHEEL_RIGHT_DIR_Pin, RESET);
  }
  else
  {
    HAL_GPIO_WritePin(WHEEL_RIGHT_DIR_GPIO_Port, WHEEL_RIGHT_DIR_Pin, SET);
  }
}

void get_brushed_PWM(void)
{
  // ARR => TOP
  TIM3->CCR2 = enable[0] * payload.weapon * TIM3->ARR;
  TIM3->CCR3 = enable[2] * payload.left_speed * TIM3->ARR;
  TIM3->CCR4 = enable[1] * payload.right_speed * TIM3->ARR;
}

void get_hand_DIR(void)
{
  if (hand_enable[0] && payload.hand_position < 0)
  {
    payload.hand_position *= -1;
    HAL_GPIO_WritePin(HAND_DIR_GPIO_Port, HAND_DIR_Pin, RESET);
  }
  else if (hand_enable[1])
  {
    HAL_GPIO_WritePin(HAND_DIR_GPIO_Port, HAND_DIR_Pin, SET);
  }
  else
  {
    payload.hand_position = 0; // stop
  }
}

void unload_payload(void)
{
  get_brushed_DIR();
  get_brushed_PWM();

  get_hand_DIR();
}

/* USER CODE END 4 */
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


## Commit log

2023-12-17 Start of work on ver2. Upload of the current progress
    Work on version 2 has started. What is done until now:
    * 3d model of the robot
    + the needed files for laser cutting
    * started making the electric scheme of the robot (still not ready)
    * started making the electric scheme of the joysticks (still not ready)
    [back.dxf, body back door.dxf, body back.dxf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]
2023-12-17 3d model of the robot upload
    [dread.f3d]
2023-12-19 Schematics ready(excluding PCB design)
    The electric schema for the PCB in the robot and the mounting schema are ready. The footprints for each element are present. However, the PCB design is not ready.
    [3522-2.step, CD40109BE.step, P6KE27CA.step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]
2023-12-22 control upload
    [kikad_project.kicad_pcb, kikad_project.kicad_sch]
2023-12-24 PCB ready
    [bottom.dxf, disk.dxf, inner center.dxf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]
2024-01-02 minor changes to PCB layout + major changes to mounting schema
    [3522-2.step, CD40109BE.step, P6KE27CA.step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]
2024-01-02 controler PCB version 1
    [PCB-B_Cu.gbr, PCB-B_Mask.gbr, PCB-B_Paste.gbr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]
2024-01-05 small edits to robot PCB schema and pcb layout
    [kikad_project-B_Cu.gbr, kikad_project-B_Mask.gbr, kikad_project-B_Paste.gbr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]
2024-01-17 small changes to the PCB layout
    [PCB-B_Cu.gbr, PCB-B_Mask.gbr, PCB-B_Paste.gbr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]
2024-02-18 regular upload
    1. mid production documentation
    2. minor edits on the electrical schemas
    3. small changes to the 3d model of the robot
    4. first try to wrtie the necessary code
    [1st_try Debug.cfg, disk.dxf, disk_small.dxf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]
2024-02-25 Almost ready transmitter and second version of receiver
    The lord and saviour bestowed upon me the power to complete the transmitter and the second version of the receiver
    NB: the clock of the transmitter must be edited
2024-02-25 Almost ready transmitter and almost ready receiver
    NB: there is a mess with the interrupts
2024-02-27 PCB edit + other minor changes
    [kikad_project-B_Cu.gbr, kikad_project-B_Mask.gbr, kikad_project-B_Paste.gbr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]
2024-02-29 Documentation ready
    Bless the holly lord and saviour!!!
    [kikad_project.csv]
2024-04-27 changes on the project structure
    [1st_try Debug.cfg]
2024-04-29 robot schema edit
    [kikad_project-B_Cu.gbr, kikad_project-B_Mask.gbr, kikad_project-B_Paste.gbr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]

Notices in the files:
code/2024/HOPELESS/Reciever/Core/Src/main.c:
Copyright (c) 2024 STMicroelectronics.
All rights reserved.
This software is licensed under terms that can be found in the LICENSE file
